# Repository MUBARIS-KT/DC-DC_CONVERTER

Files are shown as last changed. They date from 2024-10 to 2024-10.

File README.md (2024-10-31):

# DC to DC Converter

This project provides the complete design and code for a DC to DC converter that steps up 12V DC to 300V DC. The project is a comprehensive solution in power electronics, including PCB design, STM32 code for PWM generation, datasheets, design references, and the full converter design.

## Features

- **High Voltage Conversion**: Steps up 12V DC input to 300V DC output.
- **PCB Design**: Includes a custom PCB layout tailored for the converter.
- **STM32 PWM Generation**: Code for PWM signal generation to drive the converter.
- **Comprehensive Documentation**: Includes datasheets and design references for all components used.
- **Optimized for Power Electronics Applications**: Designed with efficiency and stability in mind, suited for high-voltage DC applications.

## Getting Started

This project is designed for use with STM32 microcontrollers and requires STM32CubeIDE for code development. The PCB design files are available and can be used with compatible design software.

### Prerequisites

- **STM32CubeIDE**: Required for programming and PWM generation.
- **PCB Design Software**: To view and edit the PCB layout files.
- **Basic Knowledge in Power Electronics**: Understanding of DC to DC converters and high-voltage safety practices.

## Usage

This project can be used as a base for developing custom high-voltage DC converters. It includes a full design, making it adaptable to various power electronics applications requiring DC step-up conversion.

## Technologies Used

- **Programming Language**: C (for STM32 PWM generation)
- **Libraries**: STM32 HAL for embedded development
- **PCB Design**: Provided layout files compatible with PCB design software

---

This README is structured for quick reference and ease of use. Let me know if you’d like any further customization!

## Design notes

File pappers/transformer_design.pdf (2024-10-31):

# DESIGN OF TRANSFORMER

# Classification of transformer

## Depending upon the type of construction used: I. Core type II. Shell type

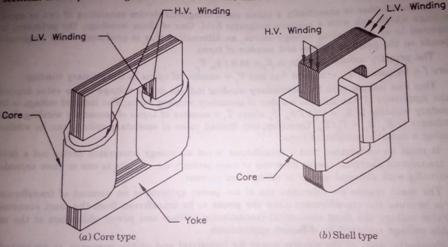
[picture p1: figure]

## Comparison of core type and shell type transformers:-

I. Construction:- Core type transformers are much simpler in design and permit easier assembly and insulation of winding.
II. Mechanical forces:- The forces produced between windings is proportional to the product of the currents carried by them. Very large electromagnetic forces are produced when secondary winding is short circuited. Since the windings carry currents in opposite direction, there exists a force of repulsion between them. Hence, the inner winding experiences a compressive force and outer winding experiences a tensile force.

In a shell type transformer, windings have greater capability of withstanding forces produced under short circuit as these windings are surrounded and supported by the core. But in a core type transformer windings have a poorer mechanical strength.

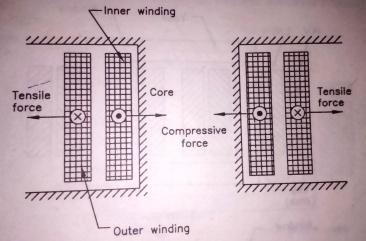
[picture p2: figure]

III. Leakage reactance:- In core type transformer large space required between the high and low voltage winding, it is not possible to subdivided the winding, while, in shell type transformer the windings can be easily subdivided by using sandwich coil. So it is possible to reduce the leakage reactance of shell type transformers.
IV. Repairs:- The winding of core type transformer is completely accessible so coils can be easily inspected. And also core type transformer is easy to dismantle for repair. In shell type transformer, the coils are surrounded by core, therefore difficulty in inspection and repair of coils.
V. Cooling:- In core type transformer windings are exposed and therefore the cooling is better in winding than core. In case of shell type transformer core is exposed therefore cooling is better than winding.

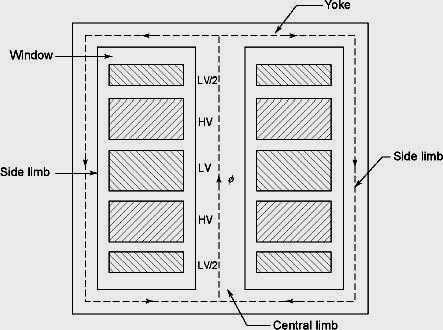
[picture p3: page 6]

CORE TYPE | SHELL TYPE
1. | Easy | in | design | and
construction.
1. Comparatively complex.
2. Has low mechanical strength due to non- bracing of windings.
2. High mechanical strength.
3. Reduction of leakage reactance is not easily possible.
3. Reduction of leakage reactance is highly possible.
4. The assembly can be easily dismantled for repair work.
4. It cannot be easily dismantled for repair work.
5. Better heat dissipation from windings.
5. Heat is not easily dissipated from windings since it is surrounded by core.
6. Has longer mean length of core and shorter mean length of coil turn. Hence best requirement
6. It is not suitable for EHV (Extra High voltage) requirement.

## Classification on the basis of type of service: I. Distribution transformer II. Power transformer

## Classification on the basis of power utility: I. Single phase transformer II. Three phase transformer

# Construction of transformer

I. Transformer core
II. Winding
III. Insulation
IV. Tank
V. Bushings
VI. Conservator and breather VII. Tapping and tap changing VIII.Buchholz Relay
IX. Explosion vent
X. Transformer oil

## - The most important function performed

by transformers are,

### – Changing voltage and current level in an electric

system.

### – Matching source and load impedances for maximum power transfer in electronic and

control circuitry.
– Electrical isolation.

### Nomenclature

Vp

, Vs

### = terminal voltages at primary and Secondary winding respectively, V

Ep

, Es

### = emf induced in the primary and secondary windings per phase, V

Et

### = emf per turn, V

Tp

, Ts

### = number of primary and secondary turns per phase

Ip

, I
s

### = primary and secondary currents per phase , A

ap

, as

### = area of the primary and secondary winding conductors, m² Φm –=main flux in weber = AiBm

Bm

### = Maximum value of the flux density = Φm / Ai

### tesla

Ai – Net iron area of the core or leg or limb (m² )= KiAgi
Ki – Iron or stacking factor = 0.9 approximately Agi – Gross area of the core, m²
Ac – area of copper in window, m²
Aw – window area, m²
D – distance between core centers, m d= diameter of circumscribing circle, m Kw – window space factor
δ - Current density (A/m²
). Assumed to be same for both LV and HV winding.

## Output Equation of Transformer

- The equation which relates the rated kVA output of a transformer to the area of core and window is called output equation.
- In transformers the output kVA depends on flux density and ampere-turns.
- The flux density is related to core area and the ampere-turns is related to window area.
- The low voltage winding is placed nearer to the core in order to reduce the insulation requirement.
- The space inside the core is called window and it is the space available for accommodating the primary and secondary winding.
- The window area is shared between the winding and their insulations.

### The simplified cross-section of core type and shell type single phase transformers

### Core Type Transformer Shell Type Transformer¹⁴

### Single phase core type transformer

The induced emf in a transformer,

Emf per turn,

The window in single phase transformer contains one primary and

one secondary winding.

The window space factor Kw is the ratio of conductor area in window

to total area of window.

Conductor area in window,

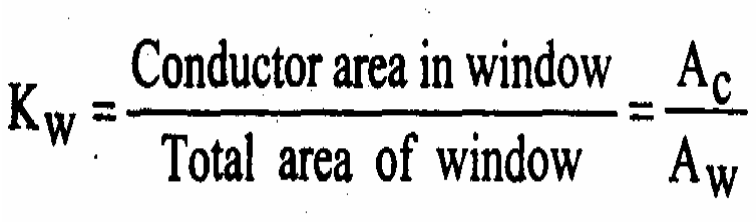
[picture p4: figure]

The current density is same in both the windings. Therefore Current

density =

Area of cross - section of primary conductor,

Area of cross - section of secondary conductor,

If we neglect magnetizing mmf then primary ampere turns is equal to secondary ampere turns. Therefore ampere turns,

Total copper area in window,
Ac = Copper area of primary winding + Copper area of secondary winding
= (Number of primary turns x area of cross-section of primary conductor) + (Number of secondary turns x area of cross -section of secondary conductor)

On equating the above equations, we get,

Therefore Ampere turns,

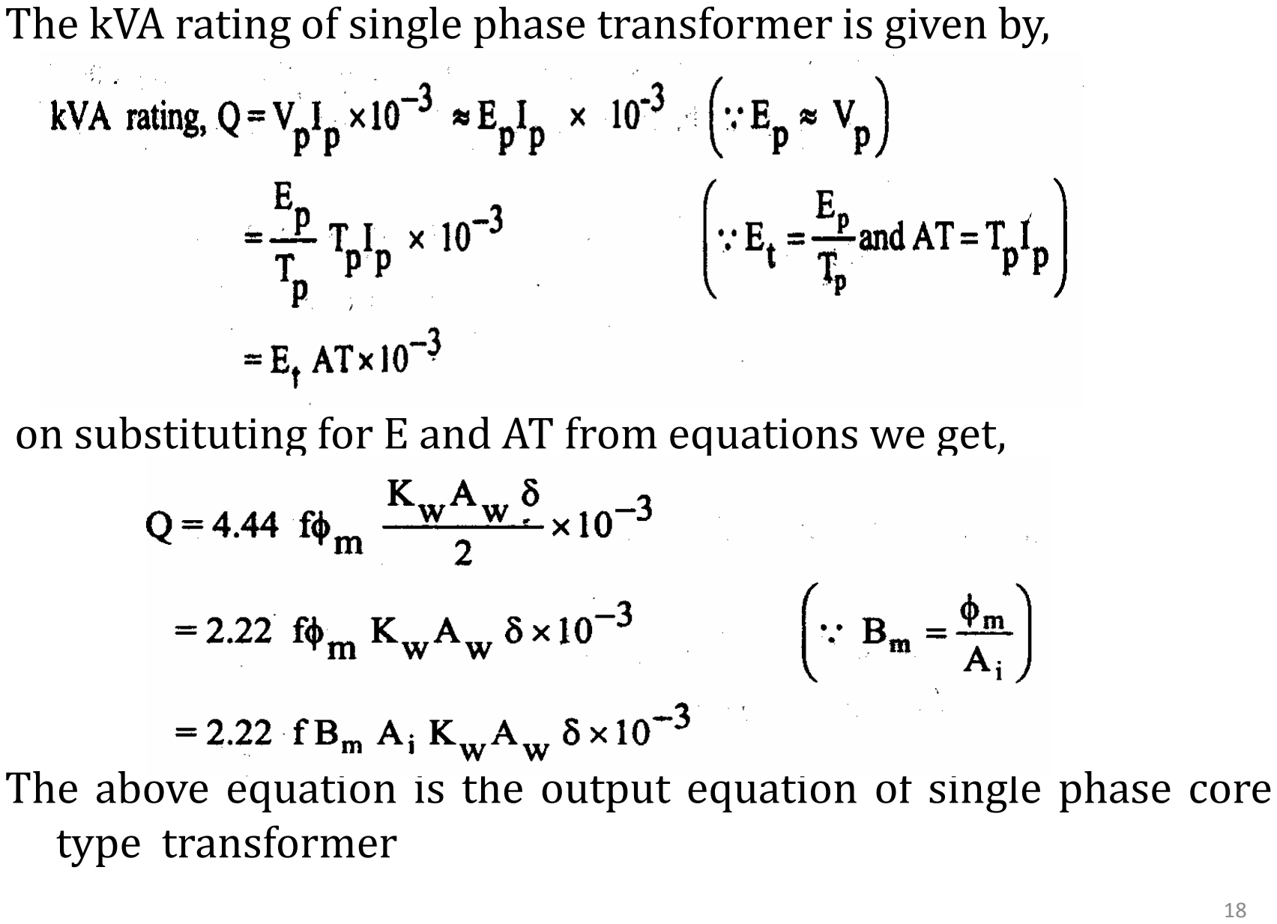
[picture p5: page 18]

The kVA rating of single phase transformer is given by,

on substituting for E and AT from equations we get,

The above equation is the output equation of single phase core type transformer

### Single phase shell type transformer

The induced emf in a transformer,

Emf per turn,

The window in single phase transformer contains one primary and

one secondary winding.

The window space factor Kw is the ratio of conductor area in window

to total area of window.

Conductor area in window,

The current density is same in both the windings. Therefore Current

density =

Area of X - section of primary conductor,

Area of X - section of secondary conductor,

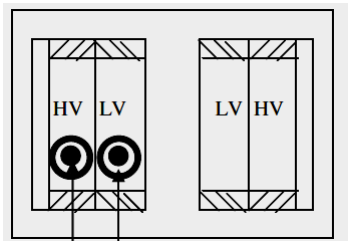
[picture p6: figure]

If we neglect magnetizing mmf then primary ampere turns is equal to secondary ampere turns. Therefore ampere turns,

Since there are two windows, it is sufficient to design one of the two windows as both the windows are symmetrical. Since the LV and HV windings are placed on the central leg, each window accommodates Tp

and Ts

turns of both primary and
secondary windings
Copper area in window Ac

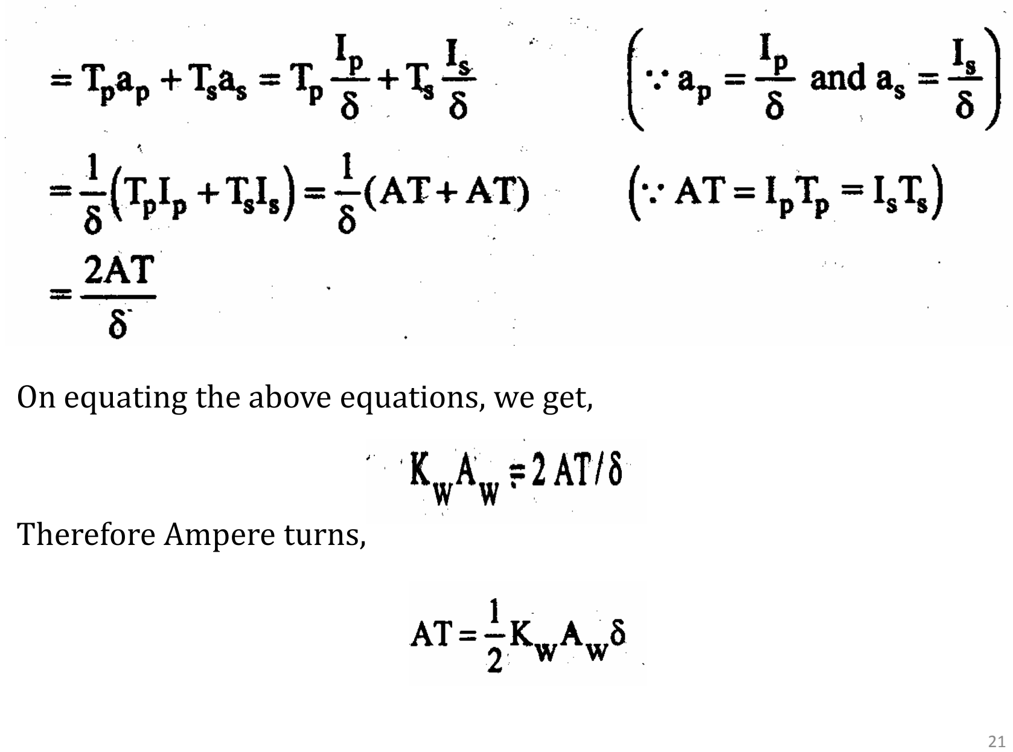
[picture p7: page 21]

On equating the above equations, we get,

Therefore Ampere turns,

The kVA rating of single phase shell type transformer is given by,

on substituting for E and AT from equations we get,

The above equation is the output equation of single phase shell type transformer

### Three phase core type transformer

- Core type three phase transformer has three limbs and two windows as shown in figure.
- Each limb carries the low voltage and high voltage winding of a phase.

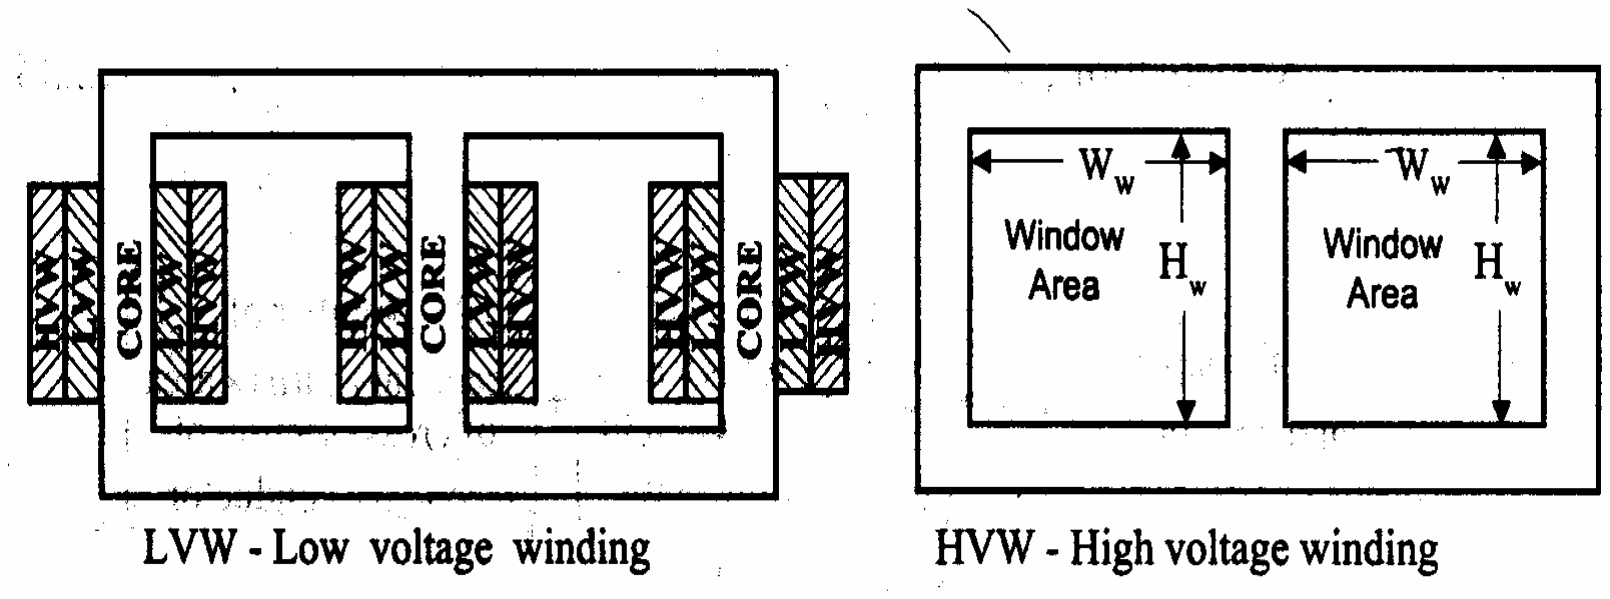
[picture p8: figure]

The induced emf in a transformer,

Emf per turn,

In case of three phase transformer, each window has two

primary and two secondary windings.

window space factor Kw is

Conductor area in window,

The current density is same in both the windings. Therefore

Current density =

Area of cross - section of primary conductor,

Area of cross - section of secondary conductor,

If we neglect magnetizing mmf then primary ampere turns is equal to secondary ampere turns. Therefore ampere turns,

Total copper area in window, Ac = (2 x Number of primary turns x area of cross-section of primary conductor) + ( 2 x Number of secondary turns x area of cross - section of secondary conductor)

On equating the above equations, we get,

The kVA rating of three phase transformer is given by,

on substituting for E and AT from equations we get,

The above equation is the output equation of three phase transformer

### Three phase shell type transformer

### Rating of the transformer in Q = Vp

Ip

### x 10⁻³ = Ep

Ip

### x 10⁻³ kVA = 4.44 Φm f Tp

### x Ip

### x 10⁻³ kVA

Since there are six windows, it is sufficient to design one of the six windows, as all the windows are symmetrical. Since each central leg carries the LV and HV windings of one phase, each window carries windings of only one phase.

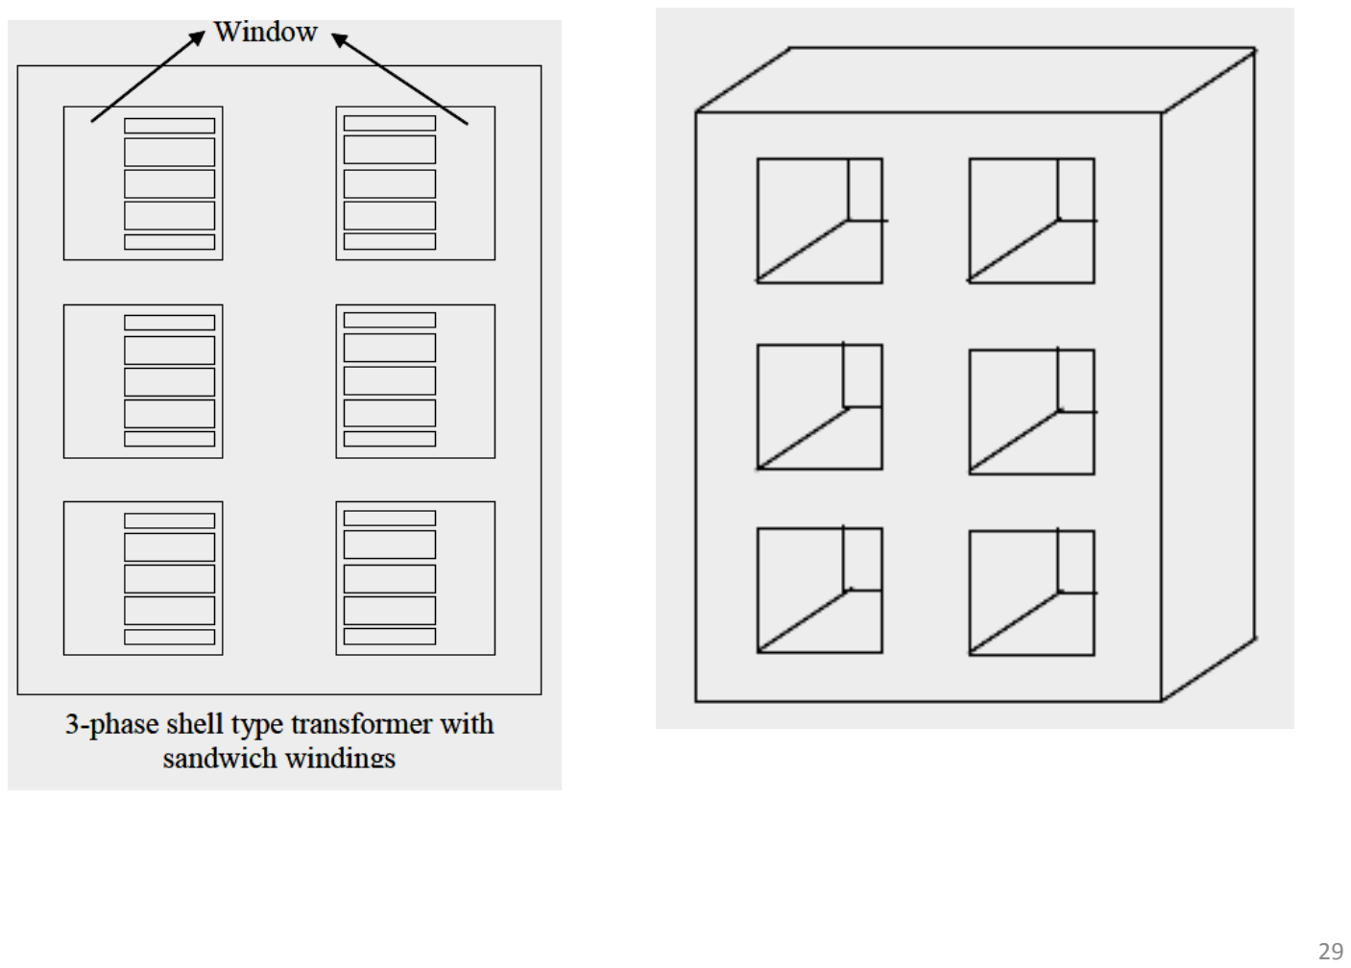
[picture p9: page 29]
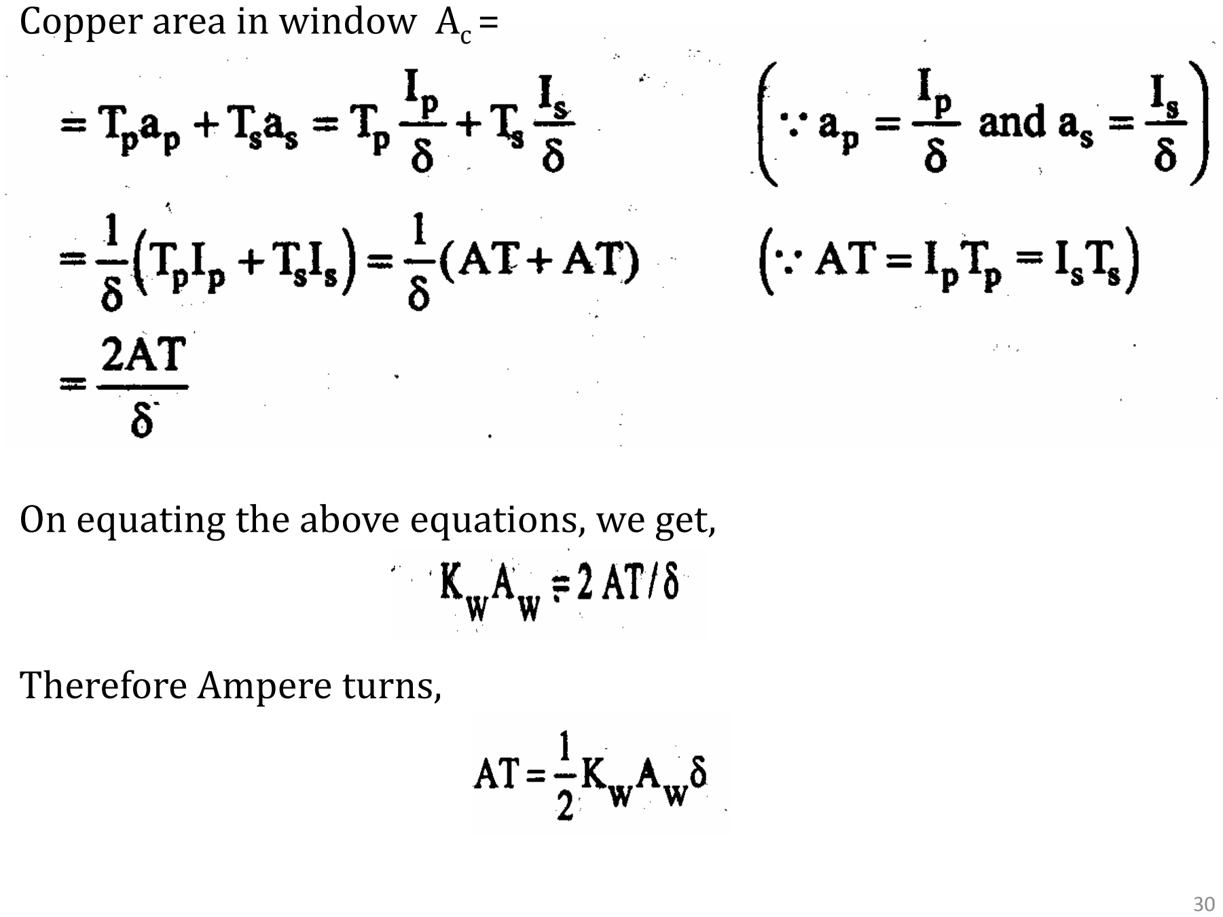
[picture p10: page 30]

Copper area in window Ac

=

On equating the above equations, we get,

Therefore Ampere turns, on substituting AT in kVA rating,

Q = 3 x 4.44 AiBmf x (AwKwδ/2) x 10⁻³ kVA

Q = 6.66 f δ AiBm AwKw

x 10⁻³ kVA

### Output equation of transformer

Single phase core type & shell type transformer :-

Three Phase core type transformer :-

Three Phase shell type transformer :-

### Q = 6.66 f Bm δ KwAw Ai

### . 10⁻³ kVA

## Usual values of flux density

Normal Si-Steel | 0.9 to 1.1 T

### (0.35 mm thickness, 1.5%—3.5% Si)

HRGO | 1.2 to 1.4 T

### (Hot Rolled Grain Oriented Si Steel)

CRGO | 1.4 to 1.7 T

### (Cold Rolled Grain Oriented Si Steel) (0.14---0.28 mm thickness)

This depends upon cooling method employed

Natural Cooling: | 1.5---2.3 A/mm2
AN | Air Natural cooling
ON | Oil Natural cooling
OFN | Oil Forced circulated with Natural air cooling
Forced Cooling : | 2.2---4.0 A/mm2
AB | Air Blast cooling
OB | Oil Blast cooling
OFB | Oil Forced circulated with air Blast cooling
Water Cooling:5.0 ---6.0 A/mm2 OW Oil immersed with circulated Water cooling OFW Oil Forced with circulated Water cooling

## Usual values of current density

## Emf per turn equation

To solve the output equation,
kVA = 2.22 or 3.33 or 6.66 f δ AiBm AwKw x 10⁻³ having two unknowns Ai

and Aw , volt per turn equation is considered.
Rating of the transformer per phase Q = Vp

Ip

x 10⁻³ = Ep
Ip
x 10⁻³ kVA | (Vp ≈ Ep
)
= 4.44 Φm f Tp

Ip

x 10⁻³

The term Φm is called the magnetic loading and I1T1

is
called the electric loading. The required kVA can be obtained by selecting a higher value of Φm and a lesser of IpTp or vice-versa.

As the magnetic loading increases, flux density and hence the core loss increases and the efficiency of operation decreases. Similarly as the electric loading increases, number of turns, resistance and hence the copper loss increases. This leads to reduced efficiency of operation. It is clear that there is no advantage by the selection of higher values of IpTp or Φm. For an economical design they must be selected in certain proportion. Let, ratio of specific magnetic and electric loading be,

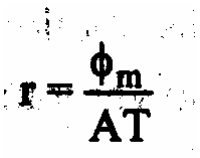
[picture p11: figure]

Considering the primary voltage and current per phase

kVA rating of transformer:

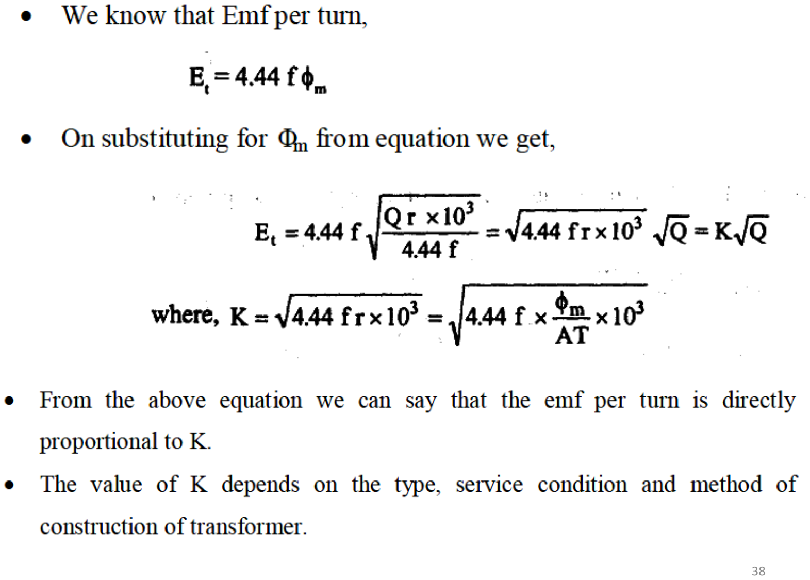
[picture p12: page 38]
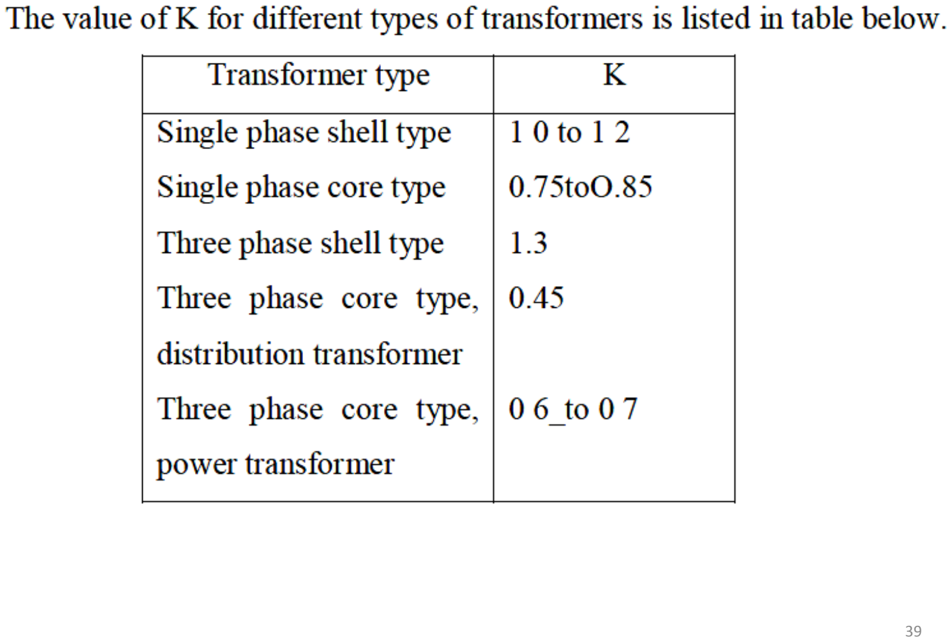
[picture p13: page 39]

## Design of Cores

Rectangular core: It is used for core type distribution transformer and small power transformer for moderate and low voltages and shell type transformers.
In core type transformer the ratio of depth to width of core varies between 1.4 to 2.
In shell type transformer width of central limb is 2 to 3 times the depth of core.
Square and stepped cores: For high voltage transformers, where circular coils are required, square and stepped cores are used.

# Square and stepped core

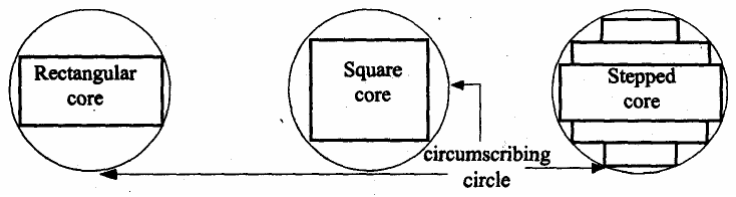
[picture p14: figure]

## Square Core

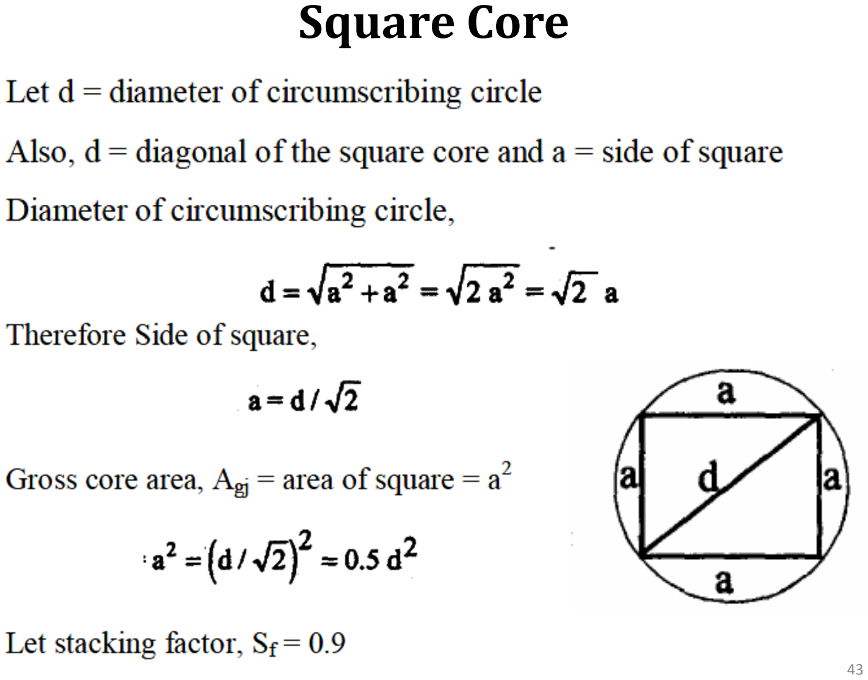
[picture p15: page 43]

## Square Core

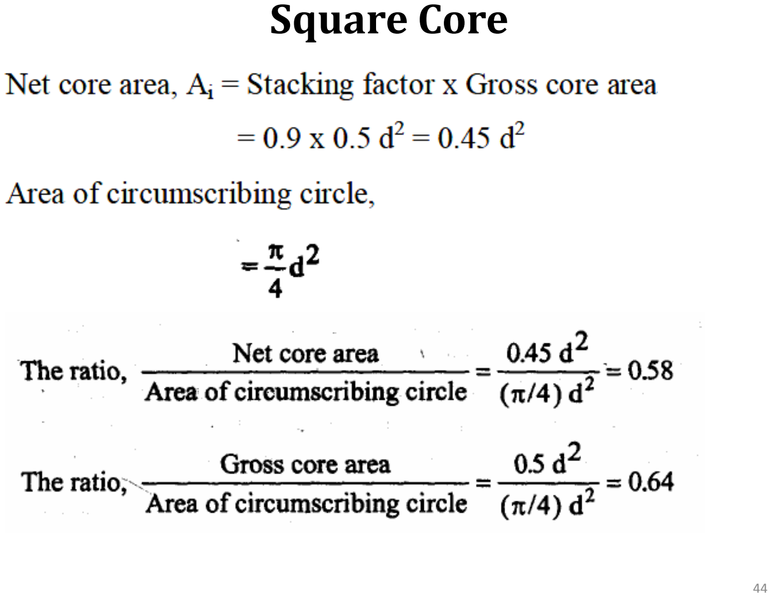
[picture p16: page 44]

## Two Stepped Core for Cruciform Core

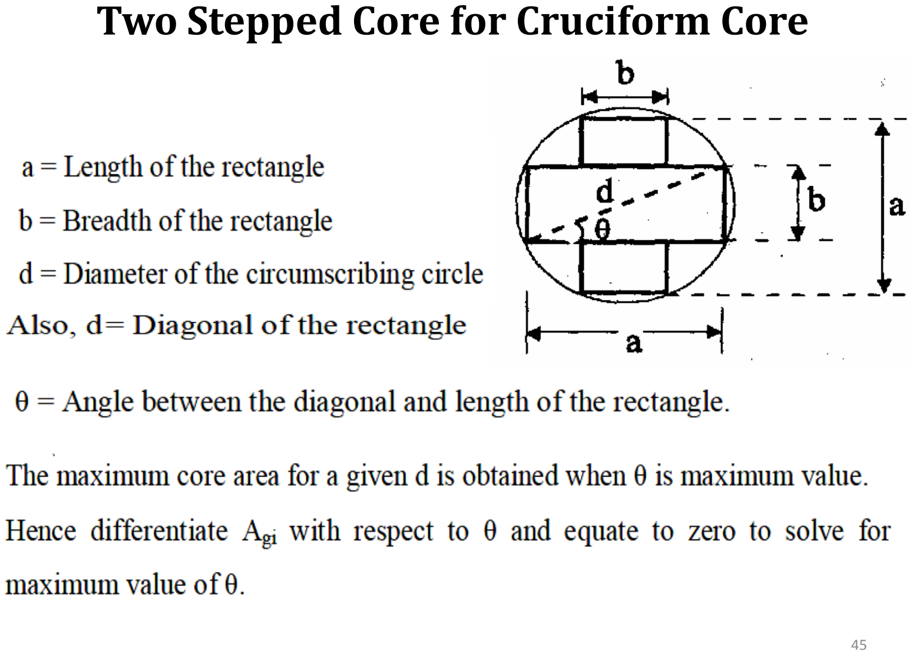
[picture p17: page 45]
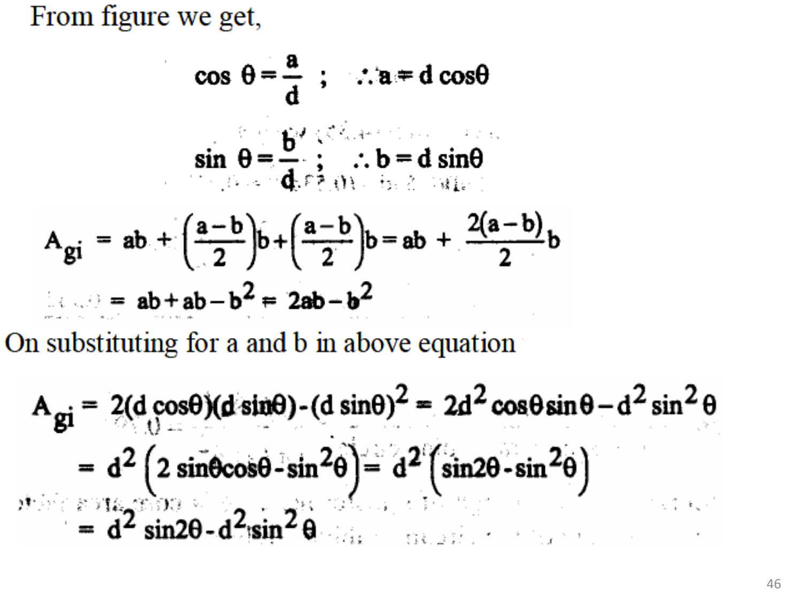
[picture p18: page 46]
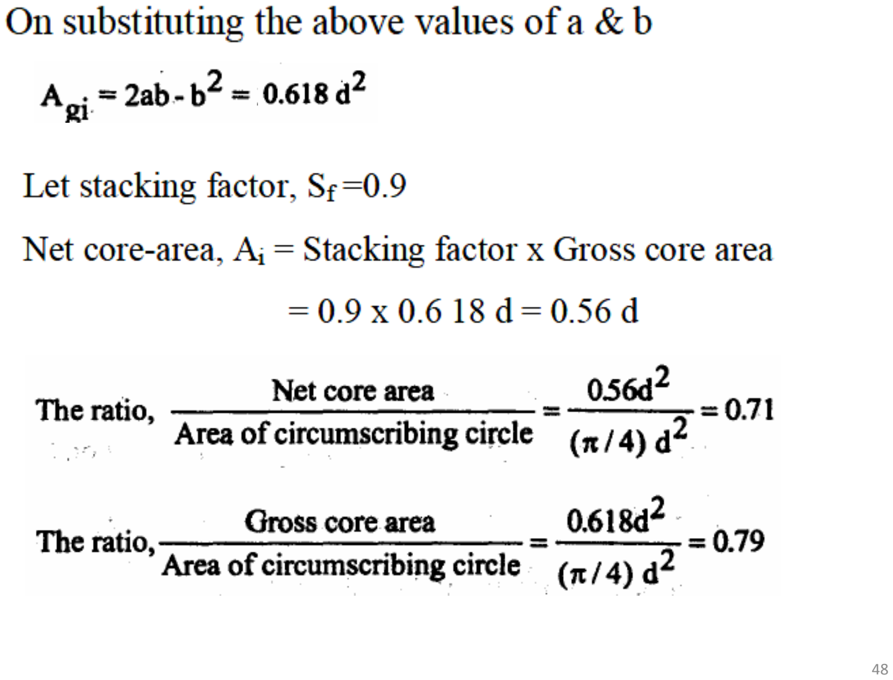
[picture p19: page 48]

### Cross-section and dimensions of Stepped cores

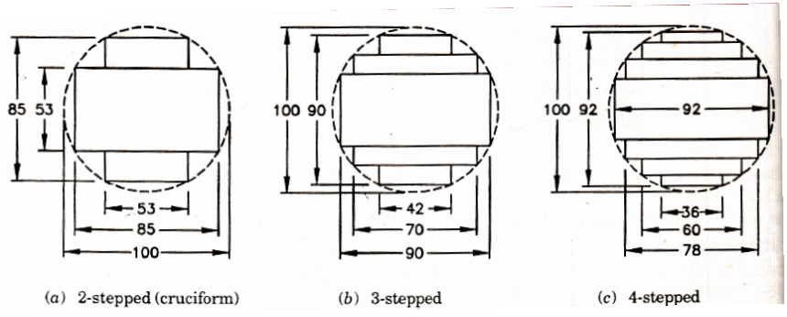
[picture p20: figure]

Area %age of circumscribing circle | Square | Cruciform | Three stepped | Four Stepped
Gross core area, Agi Net core area, Ai | 64 58 | 79 71 | 84 75 | 87 78
Net core area 2 Ai=kcd , kc | 0.45 | 0.56 | 0.6 | 0.62

Window Space Factor: It is the ratio of copper area in the window to the total window area.

Kw = 10/(30+kV) | for transformer rating 50 to 200kVA
Kw = 12/(30+kV) | for rating about 1000 kVA
Kw = 8/(30+kV) | for rating about 20 kVA

Window dimensions:
The area of window depend upon total conductor area and window space factor.
Area of window Aw = total conductor area/ window space factor = 2.ap Tp/Kw for 1-ph transformer = 4.ap Tp/Kw for 3-ph transformer

Aw = height of window x width of window = Hw x Ww
The ratio of height to width of window, Hw /Ww is b/w 2 to 4.

Design of Yoke: The section of yoke can either be taken as rectangular or it may be stepped.
In rectangular section yokes,
depth of the yoke = depth of core
area of yoke Ay = Dy x Hy
Dy = depth of yoke= width of largest core stamping = a
Ay = 1.15 to 1.25 of Agi for hot rolled steel
= Agi for CRGO

### Overall Dimensions

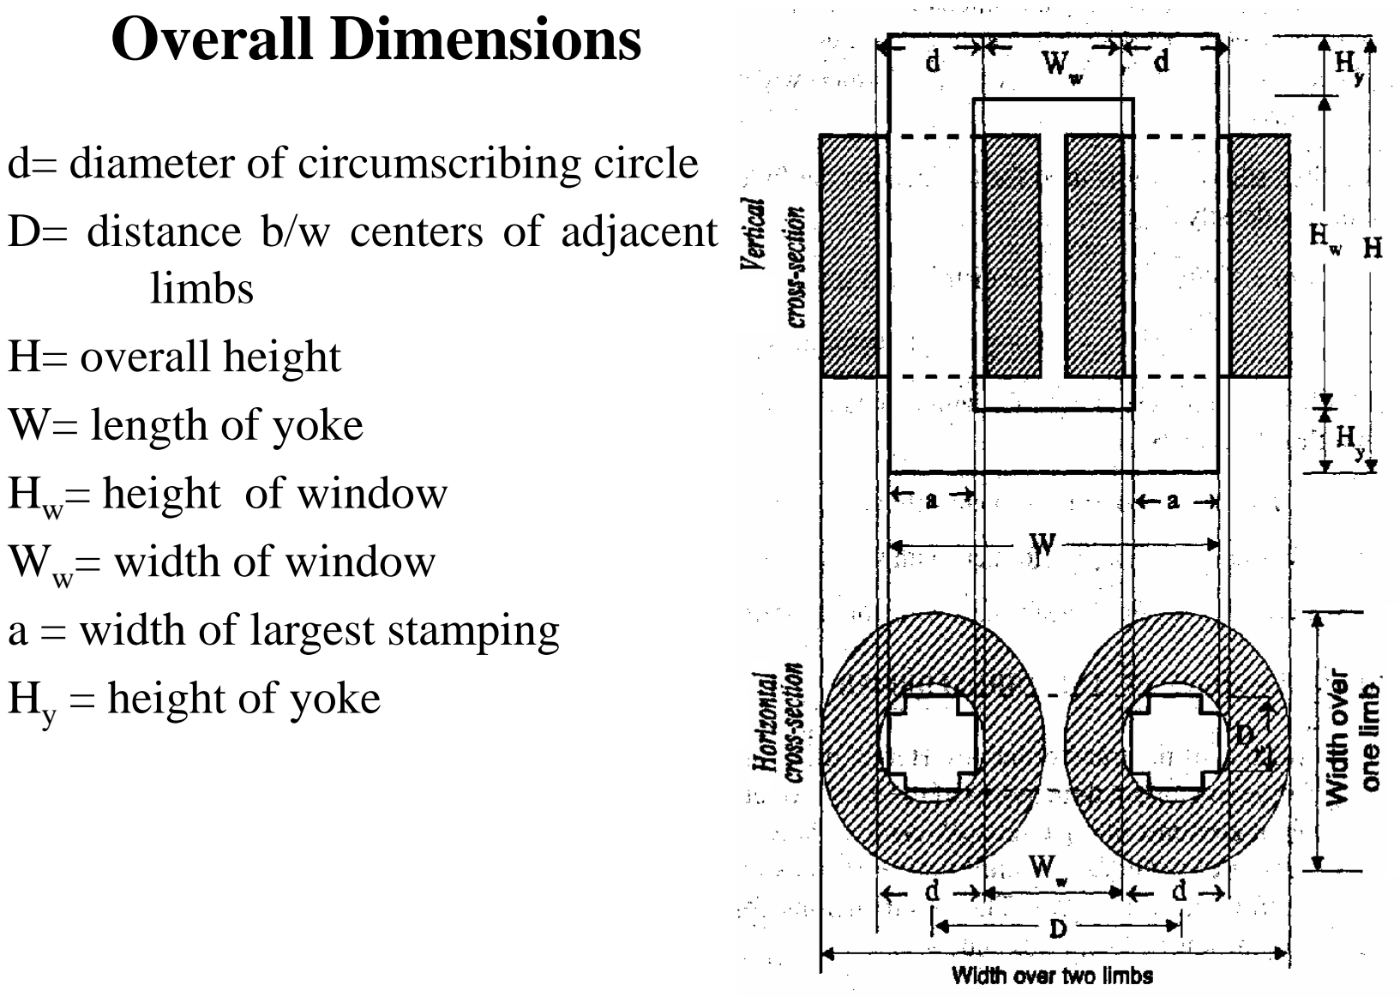
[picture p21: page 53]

d= diameter of circumscribing circle D= distance b/w centers of adjacent limbs
H= overall height
W= length of yoke
Hw

= height of window
Ww

= width of window
a = width of largest stamping Hy

= height of yoke

1-Φ Core Type Transformer
D = d + Ww
Dy

= a
H = Hw + 2Hy
W = D + a
Width over two limbs = D + outer diameter of hv winding Width over one limb = outer diameter of hv winding
3-Φ Core Type Transformer
D = d + Ww

, Dy

= a
H = Hw + 2Hy
W = 2D + a
Width over three limbs = 2*D + outer diameter of hv winding Width over one limb = outer diameter of hv winding

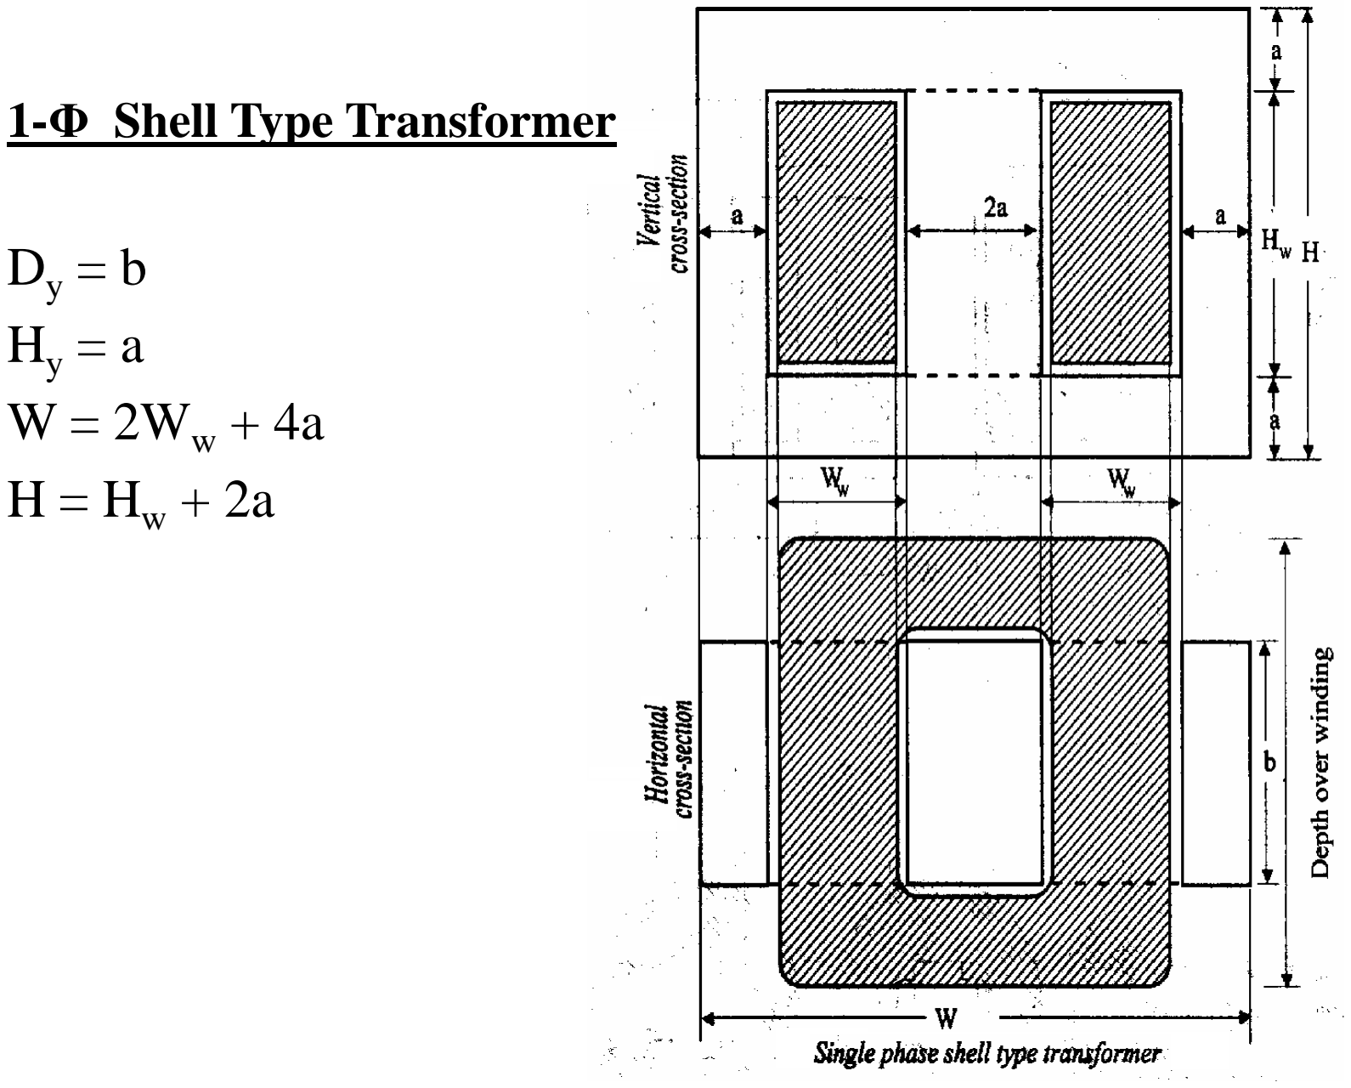
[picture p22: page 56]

1-Φ Shell Type Transformer

Dy = b
Hy = a
W = 2Ww + 4a
H = Hw + 2a

Estimation of no of turns :

Primary no of turns Tp = Vp / Et

Secondary no of turns Ts = Vs / Et

Estimation of sectional area of windings

Primary current Ip

= Q*10⁻³
/3Vp

Secondary current Is

= Q*10⁻³
/3Vs

Sectional area of primary winding ap

= Ip

/ δ

Sectional area of primary winding as

= Is

/ δ

Resistance of Transformer

Resistant of the primary winding/phase rp

= (ρLmt) Tp

/ap ohm
Mean length of turn of the primary winding Lmt_p

= π x mean
diameter of the primary winding
Resistant of the secondary winding/phase rs

= (ρLmt) Ts /as ohm
Mean length of turn of the Secondary winding Lmt_s

= π x mean
diameter of the secondary winding
Resistance of the transformer referred to primary / phase Rp

= rp + rs

‘ = rp + rs
(Tp

/Ts

)
Resistance of the transformer referred to primary / phase Rs

= rs + rp

‘ = rs + rp
(Ts

/Tp

)

Reactance of Transformer

Useful flux: It is the flux that links with both primary and secondary windings and is responsible in transferring the energy Electro-magnetically from primary to secondary side. The path of the useful flux is in the magnetic core.
Leakage flux: It is the flux that links only with the primary or secondary winding and is responsible in imparting inductance to the windings. The path of the leakage flux depends on the geometrical configuration of the coils and the neighboring iron masses.

If xp

and xs

are the leakage reactances of the primary and secondary windings, then the total leakage reactance of the transformer referred to primary winding
Xp

= xp + xs

'

= xp+ xs

(Tp

/Ts

)

2

and total leakage reactance of the transformer referred to primary winding
Xs

= xs + xp

'

= xs+ xp

(Ts

/Tp

)

2

Voltage Regulation

V .R. = Is RsCosΦ2 ± Is Xs SinΦ2 *100
Es
= RsCosΦ2
* 100 ± Xs SinΦ2

*100
Es
/ Is | Es

/ Is
= %RsCosΦ2 ± %Xs SinΦ2

No-load current of transformer

The no-load current I0 is the vectorial sum of the magnetizing current Im and core loss or working component current I
c
[Function of Im is to produce flux Φm in the magnetic circuit and the function of I
c

is to satisfy the no load losses of the transformer].

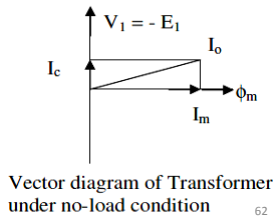
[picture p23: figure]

No load input to the transformer/ph = V1

I0 Cosϕo = V1
Ic

No load losses as the output is zero and input = output + losses.

Since the copper loss under no load condition is almost negligible,

the no load losses can entirely be taken as due to core loss only. Thus

the core loss component of the no load current

I
c

= core loss/ V1

for single phase transformers

Ic

= core loss/ 3V1

for three phase transformers

RMS value of magnetizing current Im

=

The magnetic circuit of a transformer consists of both iron and air path. The iron path is due to legs and yokes and air path is due to the unavoidable joints created by the core composed of different shaped stampings. If all the joints are assumed to be equivalent to an air gap of length lg

, then the total ampere turns for the transformer magnetic circuit is equal to ATfor iron + 800,000lgBm

ATo

= ATfor iron + 800,000lgBm

ATfor iron = 2 atc

l

c + 2aty

l
y

for single phase transformer

ATfor iron = 3 atc

l

c + 2aty

l
y

for three phase transformer

l
c

, l
y

= length of flux path through core and yoke respectively atc

, aty
= mmf/m for flux densities in core and yoke respectively

1. In case of a transformer of normal design, the no load current will generally be less than about 2% of the full load current.
2. No load power factor Cosϕo = Ic/Io and will be around 0.2.
3. Transformer copper losses:
a) The primary copper loss at no load is negligible as Io

is very less.
b) The secondary copper loss is zero at no load, as no current flows in the secondary winding at no load.
4. Core or iron loss:
Total core loss = core loss in legs + core loss in yokes.
Core loss in leg = loss/kg in leg * weight of leg in kg = loss / kg in leg * volume of the leg (Ai

*Hw

) * density of
steel or iron used
Core loss in yoke = loss/kg in Yoke * volume of yoke (Ay

* mean length of
the yoke) * density of iron used

### Temperature rise of Transformer

•The losses developed in the transformer cores and windings are converted into thermal energy and cause heating of corresponding transformer parts.
•The heat dissipation in transformer occurs by Conduction, Convection and Radiation.
The paths of heat flow in transformer are the following
1. From internal most heated spots of a given part (of core or winding) to their outer surface in contact with the oil.
2. From the outer surface of a transformer part to the oil that cools it.
3. From the oil to the walls of a cooler, eg. Wall of tank.
4. From the walls o the cooler to the cooling medium air or water.

•In the path 1 mentioned above heat is transferred by conduction. •In the path 2 and 3 mentioned above heat is transferred by convection of the oil.
•In path 4 the heat is dissipated by both convection and radiation.
In small capacity transformers the surrounding air will be in a position to cool the transformer effectively and keeps the temperature rise well with in the permissible limits.
As the capacity of the transformer increases, the losses and the temperature rise increases. In order to keep the temperature rise with in limits, air may have to be blown over the transformer. This is not advisable as the atmospheric air containing moisture, oil particles etc., may affect the insulation. To overcome the problem of atmospheric hazards, the transformer is placed in a steel tank filled with oil.

Further as the capacity of the transformer increases, the increased losses demands a higher dissipating area of the tank or a bigger sized tank. This calls for more space, more volume of oil and increases the cost and transportation problems. To overcome these difficulties, the dissipating area is to be increased by artificial means with out increasing the size of the tank. The dissipating area can be increased by
1. fitting fins to the tank walls | 2. fitting tubes to the tank
3. using corrugated tank | 4. using auxiliary radiator tanks

Since the fins are not effective in dissipating heat and corrugated tank involves constructional difficulties, they are not much used now a days. The tank with tubes are much used in practice.

Heat goes dissipated to the atmosphere from tank by radiation and convection. It has been found by experiment that a plain tank surface dissipate 6.0W and 6.5W/m²–

oC by radiation and
convection respectively. Thus a total loss dissipation is 12.5W/m²–

oC.

Temp rise θ

St = Heat dissipating surface of tank

Plain Walled Tanks

Design of Tank with Tubes

If the temperature rise of plain tank exceeds the permissible limit of about 50 degree centigrade, then cooling tubes are to be added to reduce the temperature rise. With the tubes connected to the tank, dissipation due to radiation from a part of the tank surface screened by the tubes is zero. So there is no change in surface as far as dissipation of heat due to radiation is concerned. Because the oil when get heated up moves up and cold oil down, circulation of oil in the tubes will be more. Obviously, this circulation of oil increases the heat dissipation by convection about 35%.

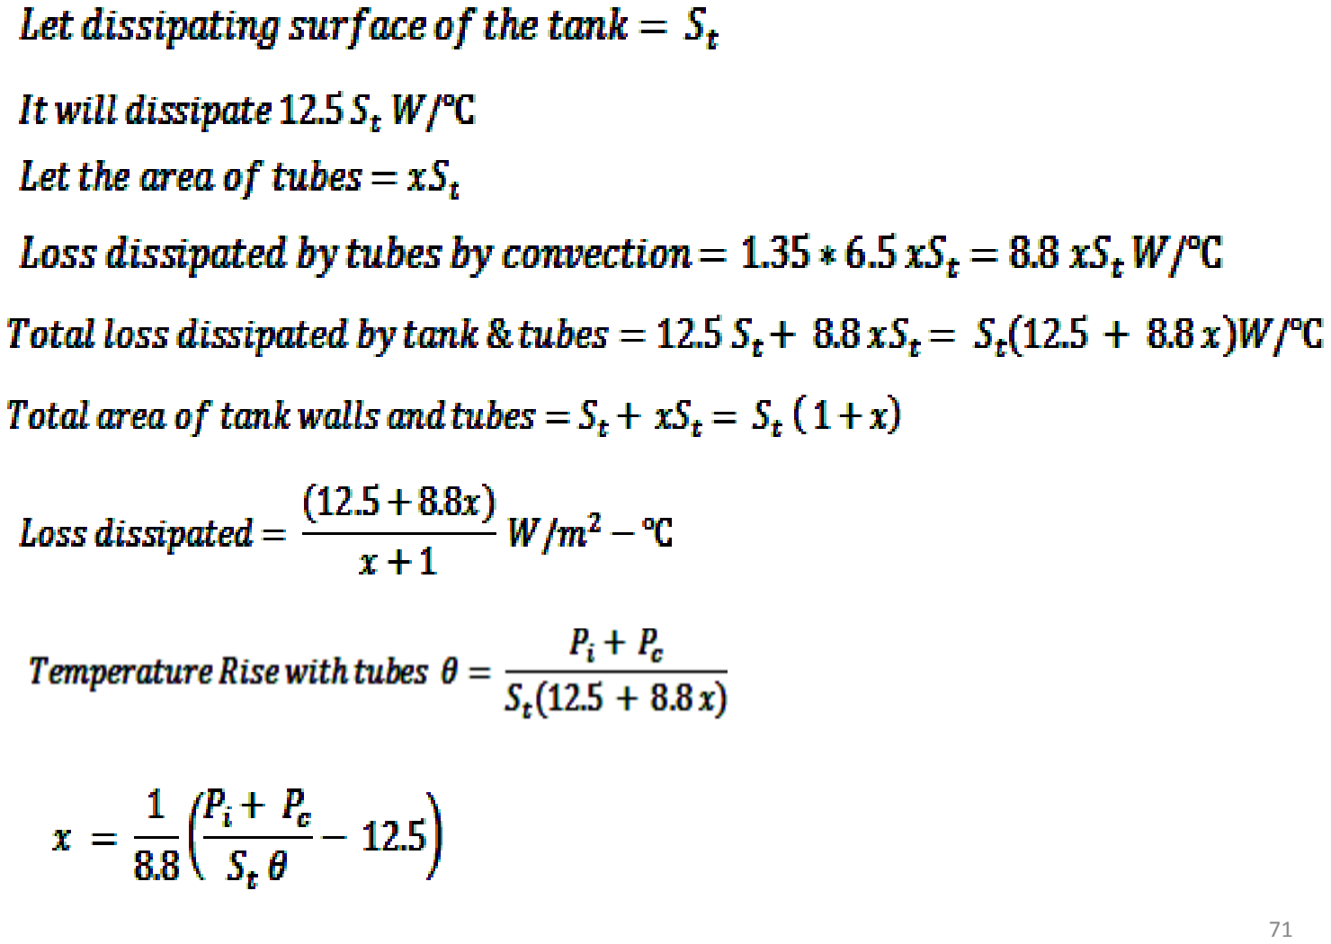
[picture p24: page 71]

The diameter of tubes, normally used, is 50 mm and they are spaced at 75 mm

Cooling of Transformer

The coolants used in transformers are air and oil.
Transformers using air as coolant are called Dry type transformers while transformers which use oil as coolant are called Oil immersed transformers.

Methods of Cooling of Transformers: the choice of cooling method depends upon the size, type of application and the type of conditions of installation sites.
The symbols designated these methods depend upon medium of cooling used and type of circulation employed.
Medium:- Air-A, Gas-G, Oil-O, Water-W, Solid insulation-S Circulation:- Natural-N, Forced-F

Cooling of Dry-type transformer Air Natural (AN), Air Blast (AB)

Cooling of oil immersed transformer Oil Natural (ON)
Oil Natural Air Forced (ONAF)
Oil Natural Water Forced (ONWF) Forced Circulation of Oil (OF)
i. Oil Forced Air Natural (OFAN) ii. Oil Forced Air Forced (OFAF) iii. Oil Forced Water Forced (OFWF)

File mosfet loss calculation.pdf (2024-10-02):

### MOSFET

### MosFET Losses

The losses in a switching MosFET are due to

- Conduction losses
- Losses due to on-state resistance/Rds-on losses
- Switching losses
- Losses due to output capacitor/Coss losses
- Turn on losses
- Turn off losses
- Gate losses – Gate charge losses and losses on the internal gate resistor

The equations regarding the above losses are expressed below

Where,

Rdson losses
The conduction loss in a MosFET is due to drain to source on-state resistance. Rdson depends upon the gate to source voltage and the junction temperature. In the datasheet of a MosFET, there will be two graphs indicating the variation of Rdson, one with respect to gate-source voltage and drain current, another one with respect to junction temperature.

From the first curve, find the Rdson corresponding to the maximum drain current (RMS) and Vgs or find the multiplier if the curve gives normalized values. Multiply with the maximum Rdson given in table to obtain the actual value.

From the Rdson vs junction temperature curve, find the Rdson or multiplier corresponding to a junction temperature of 75°C or higher as per the maximum external ambient temperature. If the ambient is above 50°C, select the Rdson multiplier corresponding to 125°C og junction temperature. Find the Rdson_hot by multiplying the Rdson obtained from the first curve or table value

The Rdson losses can be found out from equation below

Where,

= RMS value of the current through MosFET

= Rdson at working junction temperature

Coss Losses
Coss is the virtual capacitor across MosFET drain and source. While switch is off, the Coss will be charged to the voltage across drain and source and when the switch turns on Coss discharges first.

Find the Coss from curve showing capacitance vs drain to source voltage, for the working Vds.

The Coss losses can be found from equation below

Where,

Coss losses

Coss at working

Drain to source voltage

Switching frequency

Turn on and Turn off of MosFET
The equivalent circuit below shows the MosFET with components having great effects in switching process.


Figure 1. MosFET equivalent circuit

The datasheet of a MosFET shows 3 capacitances,

Input capacitor

Output capacitor

Reverse transfer capacitance

The relation between the datasheet capacitances and equivalent circuit capacitances are as given below

with shorted

Where,

Gate to source capacitor

Gate to drain capacitor

Drain to source capacitor

Turn-on Process
The graph below shows the MosFET turn on process.


Figure 2 – MosFET turn on curve

– When a voltage of | is applied across MosFET gate, | and | is charged initially. Until the
voltage reaches the threshold value of gate voltage | , there is no change in voltage and current across
MosFET.
– Once the gate voltage reaches | , the current starts increasing, but drain to source voltage still
remains the same. When the gate voltage reaches the plateau voltage | , | is fully charged and the
drain current reaches its final value. This time | is called turn on delay time | .
– Once gate voltage reaches plateau voltage | , the voltage remains at the same level until the
capacitor | is fully charged. This capacitor is called Miller capacitor and the region is known as Miller
plateau. When voltage reaches plateau, | starts falling and at the end of plateau region, | reaches
the minimum value of 10% of maximum | . The time | is called rise time

– Once | is fully charged at the end of plateau, the capacitors | and | charges up to the final
value of applied | .
The gate charge parameters in MosFET datasheet | and | are the bare minimum charge required to
turn on the MosFET, but an additional charge should be required to keep the MosFET on, thus making the total charge to be

. Power loss will be there when voltage and current changes, this occur at times and

. The equations for the times can be found out from the capacitor charging equations.


Figure 3 – Turn on times and capacitances

The capacitor charging equation in general is
(
(

⁄ )

)
(

)

Where,

Capacitor voltage at the end of time t.

Source voltage

Time taken for the capacitor voltage to rise from 0 to

Charging resistor

The capacitance

For times | and
, the capacitor | charges from gate supply through a resistor | , where | is
the sum of internal and external gate resistances in the charging path.

[

]

Transforming the general equation into MosFET charge parameters, we will get
(

)

(

)

Equation 2 – 1 gives
(

)

Where,

Turn on delay time

Sum of internal and external gate resistances in the charging path

Input capacitor at working , taken from graph

Gate-source driver supply voltage

Gate threshold voltage

Miller plateau voltage

For time

, the capacitor | charges from gate supply through a resistor | at a voltage | . The
rise time | can be found out from the equation below.
(

)

Where,

Rise time

Sum of internal and external gate resistances in the charging path

Reverse transfer capacitor at working , taken from graph

Gate-source driver supply voltage

Drain to source working voltage

Miller plateau voltage

The total on time is given by,

(

) | (

)

Turn-off Process
The graph below shows the MosFET turn off process.


Figure 4 – Mosfet turn off curve

– When the gate voltage of | is made zero from the driver, the voltage across Mosfet gate
capacitors starts discharging from the high level value of | . Until the voltage reaches the miller plateau
voltage | , there is no change in voltage and current across MosFET.
– Once the gate voltage reaches | , | starts rising and at the end of plateau region | reaches
the value of 90% of maximum | . This time | is called turn off delay time | .

– At the end of plateau region, the drain current and gate voltage starts falling. Drain current reaches
its minimum value, when the gate voltage crosses the threshold value of gate voltage | . As the drain
current falls, the leakage and stray inductances in the switching path generates a spike in the | . The
time | is called fall time and at the end of fall time, the mosfet is completely turned off.
– The remaining gate voltage from | discharges to zero at this time period.
Power loss will be there when voltage and current changes, this occur at times | and

. The
equations for the times can be found out from the capacitor discharging equations. The figure below shows the turn off times and capacitances.


Figure 5 – Mosfet turn off times and capacitances

The capacitor discharging equation in general is

(

⁄ )
(

)

Where,

Capacitor voltage at the end of time t.

Initial voltage

Time taken for the capacitor voltage to fall from

to

Discharge resistor

The capacitance

For times | and
, the capacitor | discharges from the plateau voltage | through a resistor | ,
where | is the sum of internal and external gate resistances in the gate turn off path.

Transforming the general equation into MosFET gate discharge parameters, we will get

(

)

Where,

Fall time

Sum of internal and external gate resistances in the discharging path

Input capacitor at working , taken from graph

Gate threshold voltage

Miller plateau voltage

For time

, the capacitor | discharges through a resistor | at a voltage | . The turn off delay
time | can be found out from the equation below.
(

)

Where,

Turn off delay time

Sum of internal and external gate resistances in the discharging path

Reverse transfer capacitor at working , taken from graph

Drain to source working voltage

Miller plateau voltage

The total off time is given by,

(

) | (

)

Turn on and turn off losses
Now that we have the turn on and turn off time of mosfet, we can find out the losses in these regions.

Turn on losses can be calculated from

Where,

Turn on losses

Drain to source voltage excluding and spikes

Total turn on time

Switching frequency

The current at which mosfet turns on – For discontinuous and boundary conduction modes, I min will be zero and hence there will not be any turn on losses. For continuous conduction mode, will be the difference between the peak current and peak to peak ripple current.

Turn off losses can be calculated from

Where,

Turn off losses

Drain to source voltage including the turn off spike

Total turn off time

Switching frequency

The current at which mosfet turns off – For all conduction modes, will be the maximum peak current in the mosfet.

Gate losses
Gate losses are due to the gate charge losses and the power loss on the internal gate resistor due to gate current.

Where,

Total gate losses

Gate charge losses

Losses on the internal gate resistance

Gate charge losses
The total gate charge of the mosfet has to be found out from the datasheet curve for the working gate voltage.

Gate charge losses can be found out from the equation below

Where,

Total gate charge from datasheet curve

Gate-source driver supply voltage

Switching frequency

Losses in internal gate resistance
When the gate current flows through the internal gate resistance, the ohmic losses contribute a minor portion in the total losses. The total gate charge divided by the time taken for charge and discharge respectively will give the average current while charging and discharging. The figure 6 below explains the charging and discharging characteristics of mosfet.


Figure 6 – Mosfet gate characteristics – turn on and turn off

At time

, input capacitor | charges from 0 to gate threshold | through | . The time

is
given by the equation;
(

)

At time

, capacitor | charges at gate threshold | through | . The time

is given by the
equation;
(

)

At time

, capacitor | charges from gate threshold voltage | to final value of the applied gate
voltage | through | . The time | can be found out from the capacitor time constant equation
considering 98% charge.

At time

, input capacitor | discharges from | to gate threshold | through | . The time
is given by the equation;
(

)

At time

, capacitor | discharges at gate threshold | through | . The time
| | | | is given by
the equation;
(

)

At time

, capacitor | discharges from gate threshold voltage | to 0 through | . The time
can be found out from the capacitor time constant equation considering 98% discharge.

Total charging time and discharging time is given by

The average current during turn on and turn off is given by

Average power loss in gate resistor is given by

(

) (

)

Where,

The average gate current during on time and off time

Total charging time and discharging time

### MosFET Design Considerations

There are certain things to be considered while selecting a mosfet. The major two things which effect the switching are listed below

•

⁄ protection

- External gate resistor selection
- Gate-source resistor selection

dV/dt Protection
When the mosfet turns on and off, drain to source voltage changes very fast. While this process, there is chance that false turn on may occur or at certain conditions, catastrophic failure may occur if the dV/dt is not limited. While turn on and turn off of the mosfet, the dV/dt can occur. The turn on time dV/dt protection can be given by connecting a resistor across mosfet gate to source and turn off time protection can be given by selecting the external gate resistor properly.

There are two ways dV/dt can occur while turn off. The maximum rate of rise of drain to source voltage is limited by the peak reverse recovery of body diode. While the mosfet is turning off, the drain to source voltage rises, the miller capacitor discharges through the gate resistor and creating a voltage drop across gate to source. If this voltage drop exceeds the gate threshold value, the mosfet turns on again, this may lead into failure. Another mechanism of false turn on is due to the parasitic BJT appears across drain and source of mosfet.

Turn off dV/dt protection can be given by selecting lower turn off impedance

| . One common
method is to provide a diode to bypass some resistance in the turn on path.

When the mosfet is used in inverter or freewheeling applications, the body diode conducts at some switching times, there the reverse recovery should be considered for maximum dV/dt.

External Gate resistor selection
The external gate resistor has to be selected according to two parameters
- dV/dt Protection
- Gate drive current capability

Gate resistor selection based on dV/dt protection – turn off
The maximum dV/dt limit can be found out by the equation below. One important parameter to consider is the negative temperature coefficient in the gate threshold voltage. At higher temperatures, the gate threshold voltage will considerably reduce due to this negative temperature coefficient.

(

- )

Where,

the maximum allowable dV/dt

Gate threshold voltage

Gate threshold voltage temperature coefficient

Mosfet junction temperature

Internal gate resistance

Gate to drain capacitor = Reverse transfer capacitor at working

Figure 7 below shows the mosfet turn off equivalent circuit with a gate drive circuitry.


Figure 7 – Mosfet gate turn off path with gate drive

The gate resistance at turn off is the sum of internal gate resistance, external gate resistance and the turn off impedance of gate drive circuitry.

Where,

Internal gate resistance

External gate resistance

Gate drive resistance

The maximum possible external gate resistance value depends upon the actual dV/dt present in the circuit. Maximum turn off resistance is given by

(

)
(

)

Where,

(

)
the maximum dV/dt possible in the circuit

has to be selected which is lesser than the maximum value obtained from equation 1 and 2. Another factor to be considered is if the external gate resistor selected is too low, which reduces the fall time where the current falls very fast, which in turn increases the dI/dt and hence the spike in drain source voltage. Thus care should be taken to select the proper gate resistance.

Gate resistor selection based on gate drive current capability – turn on
The on time gate resistor selection is based upon the gate drive current capability. Lower the value of gate resistor, smaller the turn on time, but higher the gate current. While selecting the gate resistor, the gate drive current has to be taken into account. Again higher dV/dt causes switching noises which appear as radiated emission.

The minimum turn on gate resistance is given by

Where,

Maximum on time gate current, which is limited by the gate driver

Gate-Source resistor selection
The gate to source resistor is important in giving dV/dt protection while mosfet turn on. A resistance value lesser than the maximum can be selected which is depending upon the maximum possible dV/dt appearing in the mosfet. The maximum value of gate source resistor is given by the equation below

(

)
(

)

Where,

The maximum value of Gate to Source resistance
(

)
The maximum dV/dt possible in the circuit

Steps to find the gate resistors
Selecting a gate resistor is an iterative process. Even if theoretically matches also, while doing the EMI EMC tests the gate resistor tuning may be required, as the stray inductance completely depends upon the switching tracing in PCB, mosfet leads, soldering etc.

Steps to find the turn off resistance

STEP 1 : Find the maximum dV/dt limit from the equation (If esr is not given in mosfet datasheet, use the gate source ESR value)

(

)

STEP 2 : Select a dV/dt lesser than the limit – use approximations like select fall time from datasheet to start with and from design with 20% spike voltage.
STEP 3 : Find the maximum off time gate resistance and hence the maximum external gate resistance possible from the equations below – use available values, omit if not known.

(

)
(

)

STEP 4 : Select nearest standard value for external gate resistance and find the fall time and turn off delay time.
(

)

(

)

STEP 5 : Find the mosfet turn off spike voltage generated by the stray inductances- consider 20nH for approximation.
STEP 6 : Find the actual maximum dV/dt from equation below. Check if the dV/dt max is less than the dV/dt limit. If yes, proceed to STEP 7, else go to STEP 3 and substitute lesser value of dV/dt max.
STEP 7 : Find the turn off losses in the mosfet and check whether the value is acceptable or not. If acceptable we have the external gate resistance value, if not acceptable reduce the dV/dt further and repeat the steps from STEP 3 onwards until a satisfactory result is achieved.

(

) | (

)

Steps to find the turn on resistance

STEP 1 : Find the maximum gate drive current possible from the driver and find the gate resistance required.
STEP 2 : Check if the minimum value obtained from STEP 1 is lesser than the sum of internal and external gate resistors at turn off. If its lesser, use the same external resistance for on time also, else select the nearest standard value and proceed to next step.
STEP 3 : Calculate the turn on delay time, rise time and turn on losses.
(

)

(

)

(

) (

)

Steps to find gate source resistance

STEP 1 : Find the maximum gate source resistor for the turn on dV/dt calculated as below and select the nearest standard value lesser than the maximum.
(

)

(

)
(

)

Sample calculation

### References

[1]. Power MOSFET Basics: Understanding Gate Charge and Using it to Assess Switching Performance - Device Application Note AN608A- VISHAY SILICONIX
[2]. Power MOSFET Electrical Characteristics Application Note – Toshiba
[3]. Power MOSFET Basics By Vrej Barkhordarian, International Rectifier, El Segundo, Ca.
[4]. Fundamentals of MOSFET and IGBT Gate Driver Circuits - Application Report SLUA618A- Texas Instruments
[5]. PowerMOSFET Application Note - AN-080E Rev.1.1- Fuji Power MOSFET
[6]. Understanding power MOSFET data sheet parameters - application note AN11158 – Nexperia [7]. AN-9010 MOSFET Basics - Fairchild

### EMI-EMC

Electro- magnetic interference (EMI) can be defined as the electro magnetic energy which affects the functioning of an electronic device. Electromagnetic compatibility (EMC) is the devices ability to work in noisy environment. The measure of emi generated by the device which is known as emission testing, and the assessing the proper functioning of a device under electro-magnetic energy field is known as susceptibility or immunity.

### EMC standards and limits

CISPR11-FCC Part 15C

The measure for emi noise generation is of two types

Conducted emission and radiated emission

Conducted emission is the disturbance produced by the power electronic converter in the ac mains when it is operating. The frequency range for conducted emission measurement is 150kHz to 30MHz.

Radiated emission is the electro magnetic energy waves produced by the power electronic circuit in a near field through air. The frequency range starting from 30mHz to 1GHz.

The equipments are classified into groups and classes as per the CISPR11 standard.

Class A equipment is equipment suitable for use in all establishments other than domestic and those directly connected to a low voltage power supply network which supplies buildings used for domestic purposes

Class B equipment is equipment suitable for use in domestic establishments and in establishments directly connected to a low voltage power supply network which supplies buildings used for domestic purposes

The tables below shoes the conducted and radiated noise levels in class B equipments


### Common mode noise and differential mode noise

The figure below explains the common mode and differential mode noises

In differential mode noise, the noise source appears across power supply lines and is in series with the power supply line, and the noise current flows in the same direction as the power supply current. It is called "differential mode" because the outgoing and return currents are oppositely-directed.

Common mode noise is noise in which a noise current that has leaked via a stray capacitance or the like passes through ground and returns to the power supply line. It is called "common mode" noise because the direction of the noise currents on the positive (+) and the negative (-) sides of the power supply have the same direction. A noise voltage does not appear across the power supply lines.

The noise appearing in switching power supplies can be well explained using figure below.


Figure 1 Common mode and differential mode noise

The differential mode noises is due to the high speed turn on and turn off of switching elements which in turn produces the ringing between the trace inductance and stray capacitances. The current and voltage are given by the equations

The mosfet turn on and turn off ringing are due to the LC tank circuits appearing for the switching time.

### Radiation

The figure below shows the radiation due to differential mode appearing at a point at a distance r from the loop with an area S, which is having a loop current of Id and a frequency f. The equation of electric field intensity is given by the equation in the figure


Figure 1 : radiation due to differential mode noise

The figure shows the radiation due to common mode noise which varies depending upon the cable length, common mode current and frequency.


Figure 2 : radiation due to common mode noise

### References

[1]. EMC Basics verA2 – Rohm Semiconductor [2].

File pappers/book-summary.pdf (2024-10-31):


# Power Electronics Step-by-Step

# Power Electronics Step-by-Step

Design, Modeling,

# Simulation, and Control

## Weidong Xiao

University of Sydney

New York Chicago San Francisco Athens London Madrid
Mexico City Milan New Delhi Singapore Sydney Toronto

Library of Congress Control Number: 2020949938

McGraw Hill books are available at special quantity discounts to use as premiums and sales promotions or for use in corporate training programs. To contact a representative, please visit the Contact Us page at www.mhprofessional.com.

Power Electronics Step-by-Step: Design, Modeling, Simulation, and Control

Copyright © 2021 by McGraw Hill. All rights reserved. Printed in the United States of America. Except as permitted under the United States Copyright Act of 1976, no part of this publication may be reproduced or distributed in any form or by any means, or stored in a data base or retrieval system, without the prior written permission of the publisher.

1 2 3 4 5 6 7 8 9 LCR 25 24 23 22 21 20

ISBN 978-1-260-45697-4
MHID 1-260-45697-8

This book is printed on acid-free paper.

Sponsoring Editor
Lara Zoble

Editorial Supervisor
Stephen M. Smith

Production Supervisor
Lynn M. Messina

Acquisitions Coordinator
Elizabeth M. Houde

Project Managers
Poonam Bisht and
Rishabh Gupta, MPS Limited

Copy Editor
Mohammad Taiyab Khan, MPS Limited

Proofreader
Nicole Schlutt

Indexer
Michael Ferreira

Art Director, Cover
Jeff Weeks

Composition
MPS Limited

Information contained in this work has been obtained by McGraw Hill from sources believed to be reliable. However, neither McGraw Hill nor its authors guarantee the accuracy or completeness of any information published herein, and neither McGraw Hill nor its authors shall be responsible for any errors, omissions, or damages arising out of use of this information. This work is published with the understanding that McGraw Hill and its authors are supplying information but are not attempting to render engineering or other professional services. If such services are required, the assistance of an appropriate professional should be sought.

To my son, William, and my daughter, Emily

About the Author
Weidong Xiao is Associate Professor in the School of Electrical and Information Engineering and the Centre for Future Energy Networks at the University of Sydney. His research involves modeling, design, simulation, and control of power electronics with focus on photovoltaic power systems. Dr. Xiao has authored one book and hundreds of technical papers and is on an editorial board at IEEE.

# Contents

ix

x | Contents
2.6 | Passive Components | | 41
2.7 | Circuits for Low-Pass Filtering | | 43
2.8 | Summary | | 47
Bibliography | | 48
Problems | | 49
3 | Non-Isolated DC/DC Conversion | | 51
3.1 | Pulse Width Modulation | | 51
| 3.1.1 | Analog PWM | | 51
| 3.1.2 | Digital PWM | | 53
3.2 | Operational Condition | | 54
| 3.2.1 | Steady State | | 54
| 3.2.2 | Nominal Operating Condition | | 55
3.3 | Buck Converter | | 55
| 3.3.1 | Steady-State Analysis | | 57
| 3.3.2 | Continuous Conduction Mode | | 58
| 3.3.3 | Discontinuous Conduction Mode | | 59
| 3.3.4 | Boundary Conduction Mode | | 60
| 3.3.5 | Case Study and Circuit Design | | 61
| 3.3.6 | Simulation of Buck Converter for
| | Concept Proof | | 63
3.4 | Boost Converter | | 67
| 3.4.1 | Steady-State Analysis | | 67
| 3.4.2 | Continuous Conduction Mode | | 69
| 3.4.3 | Boundary Conduction Mode | | 69
| 3.4.4 | Discontinuous Conduction Mode | | 70
| 3.4.5 | Circuit Design and Case Study | | 72
| 3.4.6 | Simulation and Concept Proof | | 73
3.5 | Non-Inverting Buck-Boost Converter | | 76
3.6 | Buck-Boost Converter: Inverting Version | | 79
| 3.6.1 | Steady-State Analysis | | 79
| 3.6.2 | Continuous Conduction Mode | | 80
| 3.6.3 | Boundary Conduction Mode | | 80
| 3.6.4 | Discontinuous Conduction Mode | | 81
| 3.6.5 | Circuit Design and Case Study | | 82
| 3.6.6 | Simulation and Concept Proof | | 83
3.7 | Cuk Converter ´ | | | 85
| 3.7.1 | Steady-State Analysis | | 86
| 3.7.2 | Specification and Circuit Design | | 88
| 3.7.3 | Modeling for Simulation | | 89
3.8 | Synchronous Switching | | 92
3.9 | Summary | | 92
Bibliography | | 94
Problems | | 94

Contents | xi
4 | Computation and Analysis | | 97
4.1 | Root Mean Square | | 97
4.1.1 | DC Waveforms | | 99
4.1.2 | AC Waveforms | 101
4.2 | Loss Analysis and Reduction | 101
4.2.1 | Conduction Loss | 102
4.2.2 | Switching Loss | 102
4.2.3 | Cause of Switching Delay | 104
4.2.4 | Minimization of Switching Loss | 104
4.3 | Gate Driver | 106
4.3.1 | Low-Side Gate Driver | 107
4.3.2 | High-Side Gate Driver | 108
4.3.3 | Half-Bridge Driver | 109
4.4 | Fourier Series | | 110
4.5 | Power Quality of AC | | 110
4.5.1 | Displacement Power Factor | | 111
4.5.2 | Total Harmonic Distortion | | 112
4.6 | Power Quality of DC | | 114
4.7 | Thermal Stress and Analysis | | 116
4.8 | Summary | | 118
Bibliography | | 118
Problems | | 119

### 5 DC to Single-Phase AC Conversion | 123

5.1 | Square Wave AC | 124
5.1.1 | Chopping | 125
5.1.2 | Phase Shift and Modulation | 125
5.1.3 | Total Harmonic Distortion | 128
5.2 | Sine-Triangle Modulation | 129
5.2.1 | Bipolar Pulse Width Modulation | 129
5.2.2 | Unipolar Pulse Width Modulation | 131
5.2.3 | Moving Average and Filtering Circuit | 133
5.3 | Two-Switch Bridge for DC/AC | 134
5.4 | Modeling for Simulation | | 135
5.4.1 | Bridge Model | 135
5.4.2 | Phase Shift Modulation | 136
5.4.3 | Bipolar Pulse Width Modulation | 136
5.4.4 | Unipolar Pulse Width Modulation | 137
5.4.5 | Integrated Modes for Simulation | 137
5.5 | Case Study | 138
5.5.1 | Chopped Square AC Output | 138
5.5.2 | Sinusoidal AC Output | 139
5.6 | Summary | 140
Bibliography | 141
Problems | 141

xii Contents

### 6 Single-Phase AC to DC Conversion | 143

6.1 | Half-Wave Rectification | 143
6.1.1 | Capacitor for Filtering | 144
6.1.2 | Case Study | 145
6.2 | Full-Wave Bridge Rectifier | 145
6.2.1 | Capacitor for Filtering | 146
6.2.2 | Inductor for Filtering | 148
6.2.3 | LC Filter | 150
6.3 | Active Rectifier | 153
6.4 | Alternative Configuration | 155
6.4.1 | Synchronous Rectifier | 155
6.4.2 | Center-Tapped Transformer | 156
6.5 | Modeling for Simulation | 157
6.5.1 | C Filter for One-Diode Rectifier | 157
6.5.2 | Full-Wave Rectifier without Filtering | 158
6.5.3 | Full-Wave Rectifier with C Filtering | 159
6.5.4 | Full-Wave Rectifier with L Filter | 161
6.5.5 | Full-Wave Rectifier with LC Filter | 161
6.5.6 | Active Rectifier | 163
6.6 | Summary | 164
Bibliography | 165
Problems | 165

### 7 Isolated DC/DC Conversion | 167

7.1 | Region of Magnetic Field | 167
7.1.1 | Operational Quadrant and Classification | 168
7.1.2 | Critical Checkpoint for Saturation | 169
7.2 | Flyback Topology | 169
7.2.1 | Derivation from Buck-Boost Converter | 170
7.2.2 | Flyback Operation | 171
7.2.3 | Continuous Conduction Mode | 172
7.2.4 | Discontinuous Conduction Mode | 173
7.2.5 | Circuit Specification and Design | 174
7.2.6 | Simulation for Concept Proof | 175
7.3 | Forward Converter | 177
7.3.1 | Two-End-Switching Topology | 177
7.3.2 | One-Transistor Solution | 180
7.3.3 | Circuit Specification and Design | 181
7.3.4 | Simulation for Concept Proof | 182
7.4 | Synchronous Rectification | 183
7.5 | Full Bridge for DC/AC Stage | 185
7.5.1 | Steady-State Analysis | 186
7.5.2 | Circuit Specification and Design | 187
7.5.3 | Simulation for Concept Proof | 188
7.6 | Push-Pull Converters | 189
7.7 | Variation and Enhancement | 191

Contents | xiii
7.8 | Summary | 192
Bibliography | 194
Problems | 194

### 8 Conversion Between Three-Phase AC and DC | 197

8.1 | DC/AC Conversion | 197
8.1.1 | Bridge and Switching Operation | 197
8.1.2 | 180◦ Modulation | 200
8.1.3 | Sine-Triangle Modulation | 202
8.1.4 | Modeling for Simulation | 204
8.1.5 | Case Study and Simulation Result | 205
8.2 | AC/DC Conversion | 207
8.2.1 | Passive Rectifier for Three Pulses per Cycle | 207
8.2.2 | Passive Rectifier for Six Pulses per Cycle | 209
8.2.3 | Passive Rectifier for 12 Pulses per Cycle | 210
8.2.4 | Active Rectifier | | 211
8.2.5 | Simulation | 213
8.3 | AC/AC Conversion | 214
8.4 | Summary | 216
Bibliography | 216
Problems | 217

### 9 Bidirectional Power Conversion | 219

9.1 | Non-Isolated DC/DC Conversion | 219
9.2 | Dual Active Bridge | 221
9.2.1 | Forward Power Flow | 222
9.2.2 | Reverse Power Flow | 225
9.2.3 | Zero-Voltage Switching | 227
9.2.4 | Losing Zero-Voltage Switching | 231
9.2.5 | Critical Phase Shift for ZVS | 233
9.2.6 | Simulation and Case Study | 235
9.3 | Conversion Between DC and AC | 236
9.3.1 | Between DC and Single-Phase AC | 237
9.3.2 | Between DC and Three-Phase AC | 237
9.4 | Summary | 238
Bibliography | 239
Problems | 239

### 10 Averaging for Modeling and Simulation | 241

10.1 Switching Dynamics | 241
10.2 Continuous Conduction Mode | 242
10.2.1 Buck Converter | 242
10.2.2 Dynamic Analysis of Second-Order Systems | 244
10.2.3 Boost Converter | 246
10.2.4 Buck-Boost Converter | 247

xiv Contents

10.3 Discontinuous Conduction Mode | 249
10.3.1 Buck Converter | 249
10.3.2 Boost Converter | 250
10.3.3 Buck-Boost Converter | 251
10.4 Integrated Simulation Model | 252
10.4.1 Buck Converter | 252
10.4.2 Boost Converter | 253
10.4.3 Buck-Boost Converter | 255
10.5 Summary | 256
Bibliography | 257
Problems | 257
| 11 Linearized Model for Dynamic Analysis | 259
11.1 General Linearization | 259
11.2 Linearization of Dual Active Bridge | 261
11.3 Linearization Based on CCM | 263
11.3.1 Boost Converter | 263
11.3.2 Buck-Boost Converter | 266
11.3.3 Non-Minimal Phase | 269
11.4 Linearization Based on DCM | 271
11.5 Summary | 271
Bibliography | 272
Problems | 273
| 12 Control and Regulation | 275
12.1 Stability and Performance | 275
12.2 On/Off Control | 276
12.2.1 Hysteresis Control | 277
12.2.2 Case Study and Simulation | 278
12.3 Affine Parameterization | 279
12.3.1 Design Procedure | 280
12.3.2 Desired Closed Loop | 281
12.3.3 Derivation of Q(s) and C(s) | 282
12.3.4 Relative Stability and Robustness | 283
12.4 Controller Implementation | 286
12.4.1 Digital Control | 286
12.4.2 PID Controllers | 288
12.4.3 Analog Control | 289
12.4.4 Case Study for Buck Converter | 290
12.4.5 Case Study for Boost Converter | 292
12.5 Cascade Control | 293
12.5.1 Case Study and Simulation | 294
12.5.2 Advantage | 295
12.6 Windup Effect and Prevention | 296
12.6.1 Case Study and Simulation | 296
12.6.2 Anti-Windup | 297

Contents xv

12.7 Sensing and Measurement | 299
12.7.1 Voltage Sensing and Conditioning | 300
12.7.2 Current Sensing and Conditioning | 302
12.8 Summary | 303
Bibliography | 304
Problems | 305
Acronyms | 307
Index | 311

# Preface

P
ower electronics has drawn significant attention in recent years because of the trend toward modern electrical systems, the variety of load profiles, and the high demand for integrating renewable energy. Although there are quite a few books on the subject available for use in academia and industry, there is a lack of proper guidebooks for beginners and self-learners to learn modern power electronics efficiently. Traditional power electronics instructors focus on AC/DC and AC/AC conversion because AC has been dominant among applications since the 1880s. For example, many books put great emphasis on the analysis and design of various AC/DC rectifiers using either diode or thyristor bridges, usually with the consideration of all kinds of load profiles. However, some topologies have been phased out due to stricter power quality requirements and limited functionality. The latest power electronics relies on active switching technologies using modern power semiconductors. One distinguishing characteristic of this book is the focus on the latest technologies and solutions.
The topologies for non-isolated DC/DC conversion are introduced at the beginning to demonstrate the switching concept, which is fundamental in power electronics. The concept is essential for learners because an increasing proportion of generation and load units is based on DC instead of AC. In particular, one chapter is dedicated to bidirectional DC power flow devices, which are widely used for rechargeable batteries, ultracapacitors, and solid-state transformers. Throughout the book, the instructions for each important subject in power electronics are given within a clear framework. The step-by-step approach is aimed at helping readers build up their knowledge progressively. For example, the knowledge of DC/AC (Chap. 5) and AC/DC (Chap. 6) conversion naturally leads to the discussion of galvanic isolated DC/DC converters (Chap. 7) since many topologies are based on the integration of both conversion stages, which finally join together as DC/AC/DC configurations with isolation transformers. The insights of the step-by-step approach come from the author’s self-learning and teaching experience in power electronics and renewable power systems.
Dynamic modeling methods are properly categorized into multiple classes, including switching, averaging, and small-signal models, following the scales of linearity from highly nonlinear to piecewise linear. The switching dynamics leads to the development of detailed simulation models that are only based on basic blocks in MATLAB/Simulink, which is a commercial software widely available in universities. In particular, averaging dynamic modeling mostly leads to switching-agnostic models that can be utilized for fast simulation and nonlinear control measures. It has been proven effective in simulating long-term operations of a system with a large number of power converters and

## xvii

xviii | Preface
| distributed generation units. Moreover, the final phase of dynamic modeling features linearized mathematical functions, based on dynamic analysis and linear control theory. For a closed-loop controller design, the technique of affine parameterization is intro- duced, which translates controller parameters to stability and performance. The step- by-step approach allows readers to understand the basics of system simulation and to bridge the gap between linear control theory and power electronics.

This book can serve as a reference book as well as the textbook in a senior-level uni-
| versity course related to the subject of power electronics. It also covers practical design subjects that can be very useful for readers in industry who seek to master the subject matter through self-study or professional training. Familiarity with the fields of electron- ics, signal theory, and linear control engineering is recommended so as to fully benefit from this book.

## Key Features

| This book is comprehensive in covering the fundamental subjects in modern power elec- tronics and control engineering. The book is organized as follows:
- The common platforms and tools for developing power electronics are introduced at the beginning.
- A comprehensive classification of power electronics applications is presented in terms of signal waveforms, power flow directions, and voltage levels.
- One important feature of this book is the emphasis on computer-aided analysis, design, and evaluation. Without losing generality, all simulation models are built and mathematical analyses are carried out using the fundamental blocks in Simulink.
- Gate drivers for power switches, which are essential for modern power electronics, are covered.
- The book also covers the topologies used for bidirectional DC/DC conversion, which has been widely adopted in industry because of the increasing usage of energy storage, such as rechargeable batteries.
- Modeling for simulation follows a modular and step-by-step approach such that a converter system is divided into individual blocks, including the power train, low-pass filtering, load, modulation, and control. The development follows the operational principle and creates a clear framework that makes it easy to understand, construct, and debug.
- Simulation models are built for most converter topologies and related modulation methods for readers to follow.
- A dedicated chapter is provided to demonstrate the averaging technology for modeling and simulation purposes. The averaging methodology is general and covers not only continuous conduction mode but also discontinuous conduction mode.
- The development of mathematical models for dynamic analysis and controller synthesis is separate from the discussion on converter simulation. Linearization and small-signal methodology are utilized to mathematically construct linear

Preface xix

models to accommodate the well-established linear control theory for the analyses of damping, speed, stability, and robustness.
- Most chapters provide a significant number of practical examples in the form of case studies in order to demonstrate and verify the design. Readers can duplicate the results through various computer-aided design and analysis platforms, which also provide a systematic way to develop and evaluate new systems.
- Abundant photos, diagrams, graphs, equations, and tables appear throughout the book for a clear explanation of the subject matter. A significant number of flowcharts have been drawn to show the procedures of system design as well as component selection in a step-by-step manner.
- A brief introduction to tools and types of equipment is recommended for those who wish to practice power electronics, including electrical computer-aided design, simulation platforms, and hardware.
- A comprehensive summary is presented at the end of each chapter.

## Organization by Chapter

The book is divided into 12 chapters, organized in such a way as to provide easy following and understanding. The text provides step-by-step introductions of the individual components and controls for power electronics systems. A brief description of each chapter follows:
Chapter 1 provides a brief background about power electronics. Some important terms are clarified in this chapter to avoid ambiguity.
Chapter 2 introduces important components of power electronics. The power electronics industry came into existence upon the diode’s invention. Switching technology led to the development of various transistors and thyristors. The characteristics of power inductors, capacitors, and resistors are discussed in this chapter.
Chapter 3 introduces the best-known topologies for non-isolated DC/DC conversion, namely buck, boost, buck-boost, and C`uk. Simulation verification accompanies each design state.
Chapter 4 focuses on power computation to evaluate power equivalence, loss analysis, and power quality, which naturally leads to the necessity of gate driver circuits. Chapter 5 discusses DC to single-phase AC conversion, especially the bridge circuit and modulation methods to achieve the design objective.
Chapter 6 introduces power conversion from single-phase AC to DC and addresses the related power quality concerns.
Chapter 7 focuses on isolated DC/DC conversion, which is an advanced arrangement built on the topologies in previous chapters.
Chapter 8 deals with three-phase AC power conversion. It covers DC/AC, AC/DC, and AC/AC conversion. The modulation for DC to three-phase AC conversion is also introduced.
Chapter 9 focuses on the topologies for bidirectional power conversion, featuring non-isolated DC/DC, isolated DC/DC, and DC/AC converters. A special topology is introduced and analyzed, which is the dual active bridge.

xx Preface

Chapter 10 introduces an averaging technique for dynamic modeling and fast sim-
| ulation of different converters in the cases of continuous conduction modes and discon- tinuous conduction modes.

Chapter 11 discusses mathematical modeling of power converters for dynamic anal-
| ysis. Linearization is widely used to derive the small-signal models. The non-minimal- phase issue is also discussed.

Chapter 12 provides control system analysis and design. Affine parameterization is
| introduced as a systematic way to synthesize controllers for power conversion regarding the balance of stability, robustness, and performance.

## Acknowledgments

| I would like to thank Mr. Jacky Han for a great work of proofreading, technically and grammatically. Special thanks go to Ms. Lara Zoble, Senior Editor in the Professional Group at McGraw Hill, for providing professional support for this project through all phases. Since I was busy writing this book for the past two years, I missed sharing quality time with my family members. Hence, last but not the least, I heartily thank all of them for their great patience and understanding, because without their continuous support and sacrifices this book would not have been possible.

## Technical Support

| All modeling and simulation for case studies in this book were developed by the basic functions of Simulink®
and MATLAB®
, which will help readers understand the fun-
| damental principles behind various simulation tools. Version R2018b or higher of the MATLAB®
and Simulink®
software can be used to repeat the results of the example
| cases or to develop new studies accordingly.

Weidong Xiao

# Power Electronics Step-by-Step

# CHAPTER 1

# Background

D
irect current (DC) flows in only one direction of electric charge, whereas its counterpart, alternating current (AC), periodically reverses current flowing direction. These two forms of currents widely present in power electronics and power systems. The “battle of the currents” refers to the significant debate and competition of electric power transmission systems in the United States, either AC or DC, in the late 1880s. It turned out that the AC-based power distribution and transmission prevailed because of its more cost-effectiveness and efficiency than DC. Power grids started with AC-based networks. Thanks to the early development of line-frequency (LF) power transformers, AC voltage can be either “stepped up” or “stepped down” to achieve different voltage levels. For a given level of power, higher voltage indicates less current flow and lower conduction loss in the transmission. Up to now, the LF power transformer is still the backbone in the power grids around the world to support high-voltage (HV) power transmission, medium-voltage (MV) distribution, and low-voltage (LV) supply to end-users. The lack of power electronics is considered one of the critical reasons leading to the failure of DC in the “battle of the currents’’ and the dominance of AC in the present power networks.
Technological development brings optimism that DC will eventually win, since the recent trend indicates more and more DC-based power generation, transmission, distribution, and applications. DC can eliminate the long-term difficulties of AC related to its frequency stability, power factor, synchronization, and interconnection. For example, the renewable resource of photovoltaic and fuel-cell generators produces DC. The utilization of energy storage of rechargeable batteries is mainly through DC. These components are important to represent the future energy network in terms of “smart” and “green” energy systems. Meanwhile, the steep growth of DC-powered loads is due not only to the computer-related products but also to the spread of devices for lighting and home appliances. Even though the majority of electric motors are conventional AC devices, high performance can only be realized by using the driver system, which is based on power electronics and mostly supplied by DC. High-voltage DC (HVDC) is becoming the norm for long-distance power transmission, thanks to the advantage of low loss and simple interconnection. The broad utilization and fast advance of power electronics make DC weigh more than before for all different voltage levels, such as high voltage (HV), medium voltage (MV), low voltage (LV), and extra-low voltage (ELV). Power electronics uses the solid-state technology to convert, process, and regulate electric power flow in terms of voltage and current from one form to another. The static power conversion technology serves as the power interface for a variety of applications. The industry started with the invention of the p-n junction to produce diodes. It boomed with the availability of thyristors thanks to the turn-on controllability. The power semiconductor devices can achieve safe and efficient power conversion and regulate the
1

### 2 Chapte r One

different levels of voltage, current, and power. Recently, the rapid growth of power electronics is considered as the backbone of modernized power systems, high-efficiency power supplies, and future energy networks because of the following factors:

- Advances in power semiconductor devices for controllable, high-efficiency, reliable, and versatile implementations.
- Trend toward modern electrical systems regarding distributed power generation, modular energy storage, and renewable power generation.
- Rise of portable consumer electronics and high-efficiency appliances.
- Advances and maturity of control engineering regarding both hardware and software to achieve high-performance and reliable operation.
- Demand for high-efficiency power supply systems to reduce pollution and retire low-efficiency devices.

## 1.1 Classification of Power Conversion

The level of power conversion can be different from the milliwatt to megawatt capacity. Various criteria can be applied to classify the system of power electronics. A device that converts power signals from one form to another is commonly called “converter,” which has become the most common term in power electronics. Therefore, one classification can be based on the conversion form in terms of DC and AC:

- AC-to-DC conversion (AC/DC)
- DC-to-AC conversion (DC/AC)
- DC-to-DC conversion (DC/DC)
- AC-to-AC conversion (AC/AC)

The AC-to-DC converter is commonly called a “rectifier,” referring to the rectification operation. Meanwhile, the DC-to-AC converter is sometimes called the “inverter.” Figure 1.1 illustrates the blocks to present the classification of AC/DC, DC/AC, DC/DC, and AC/AC. These will be applied in system diagrams throughout the book.
Another classification is based on the direction of active power flow in steady state. For example, rechargeable batteries require bidirectional power flow to charge and discharge when one converter is utilized for the power interface. The same operation is commonly required for the power conversion to interface ultracapacitors. Thus, the power conversion can be classified as either unidirectional or bidirectional, as illustrated in Fig. 1.2. The input and output ports can be clearly identified in the unidirectional power conversion. The input port is always connected to the source; meanwhile, the load is linked to the output port. When energy storage is applied, e.g., rechargeable batteries, the definition of input and output ports is no longer clear for
(a) | (b) | (c) | (d)

FIGURE 1.1 Blocks of power conversion: (a) AC/DC; (b) DC/AC; (c) DC/DC; (d) AC/AC.

Background | 3
Input: | voltage
source

Output:
load current

Converter

Converter

voltage
current

voltage
current

voltage
current

(a)

(b)

FIGURE 1.2 Diagrams showing power conversion: (a) unidirectional; (b) bidirectional.

the bidirectional converters. The DC terminal of rechargeable batteries can be either the source or load, depending on the conversion operation. The bidirectional power conversion shows fast growth due to the wide utilization of rechargeable batteries. The bidirectional power conversion can have any of the following forms: AC/DC, DC/AC, DC/DC, and AC/AC.
Classification can be defined and based on the voltage level. Power converters are widely utilized to supply portable devices, such as tablets, mobile phones, and laptops, which are classified as the group of extra-low-voltage (ELV) applications. Based on the average value of human body resistance, the voltage level is usually considered as low risk to life. Other voltage levels are higher and pose a threat to life; therefore, devices having such a higher voltage should be strictly isolated from human contacts. The following definitions are considered as a reference for the discussion and analysis that follow.
- Extra-low voltage (ELV): <50 V
- Low voltage (LV): 50–1000 V
- Medium voltage (MV): 1–35 kV
- High voltage (HV): 35–230 kV
- Extra-high voltage (EHV): >230 kV

Classification of voltage levels can be sourced from the International Electrotechnical Commission (IEC). It should be noted that the voltage rates listed above are just for a general reference. The strict definition varies for DC and AC, and is different from one country to another. Figure 1.3 demonstrates the diagrams of power systems indicating various voltage levels at the different conversion stages. Theoretically, the higher the voltage level, the lower the conduction loss for long-distance transmission and distribution.
The conventional power system is represented by the highly centralized grid structure, as shown in Fig. 1.3a. The power from the centralized power generation facility is eventually delivered to end-users through the networks of transmission and distribution. Voltage conversion mainly relies on power transformers. The modernized network adopts more renewable energy resources, distributed power generations, demand response, and energy storage. The impact of microgrids and smart grids is likely to change the future grid infrastructure, especially at the distribution levels, as illustrated in Fig. 1.3b. An important element of such power systems is the prosumer that is able to supply power to grids from the local power generation system. Power electronics eventually plays an important role in supporting the transition into modern

### 4 Chapte r One

Centralized
Generation

(a)

(b)

Centralized
Generation

Transmission
HV or EHV

Transmission
HV or EHV

Distribution
&
MV loads

MV distribution,
loads, storage,
and generation

LV & ELV supply,
loads, storage, EVs,
and generation

LV supply
&
loads

ELV supply
&
loads
HV | HV | MV | LV | LV | ELV
MV | HV HV | MV | MV | LV
MV | MV

FIGURE 1.3 Conversion for power systems: (a) conventional; (b) modernized.

Dynamics and control engineering; Electromagnetics; Power; Electronics; Thermal analysis; Electric machines; Solid-state physics; Circuit theory; Power systems; Signal processing; Simulation and computing

FIGURE 1.4 Interdisciplinary nature of power electronics.

electrification. The bidirectional power conversion will be demanded at different levels to make the future system efficient, adaptable, reliable, and more.

## 1.2 Interdisciplinary Nature of Power Electronics

Power electronics is commonly considered as the bridge between the power engineering and electronic application. The subject actually covers many technologies more than power and electronics. The interdisciplinary nature of power electronics is illustrated in Fig. 1.4.
Accurate power conversion cannot be realized without the support of control engineering. Modern power electronics tends to use digital control technology and relies on fast computing hardware and digital signal processors to improve control capability and performance. The solid-state components of electromagnetics and electronics form the foundation of power electronics. The power switching operation relies on the advances in power semiconductor devices to reduce both conduction and high-frequency loss.

Background 5

System analysis and design are always based on circuit and electromagnetic theories. Fast computer simulation has become a norm for the concept proof and guides for system improvement. Additionally, more and more power conversions are digitally controlled by various computational devices such as microprocessors, digital signal processors, microcontrollers, and field-programmable gate array (FPGA). Electric machines bridge mechanical engineering and electrical engineering, but rely on power electronics to efficiently and accurately drive the motion and convert generating power for utilization. Thermal analysis is commonly linked to mechanical analysis and design but becomes an important sector to support the highly efficient and reliable power conversion.

## 1.3 Typical Applications

The telecommunications industry mainly relies on DC and uninterrupted power supplies (UPS), which require the conversion of AC/DC and DC/DC. The DC power traditionally supports the operation of signal processing, transmission, amplifier, etc. Modern power electronics tends to directly serve as the power amplifiers for communication purposes, which provide simplicity and improve the overall system efficiency. Modern transportation tends to be electrified to reduce pollution and better dynamics. The concept of electric vehicles (EVs) is referred to as not only ground automobiles but also any form of transportation in air and water. The propulsion is based on electric motors, drivers, energy storage units, etc. Power electronics is essential for the system coordination, power management, speed regulation, battery charging, and discharging. EVs are also expected to participate in the grid support for future energy network in partnership with power electronics. Aerospace relies on power supplies to operate space shuttles, stations, satellites, etc. Modern aircrafts demand more power electronics to coordinate the power balance among loads, generators, and energy storage units for high efficiency and high power density.
Modern homes are full of various electrical appliances, e.g., microwave ovens, airconditioners, induction cookers, high-efficiency lightings, and residential photovoltaic (PV) power generators. Power electronics plays an important role in supporting the smart operation, high efficiency, reliability, and flexibility. Portable electronic devices are increasingly being used in our daily lives. DC and conversion are required for power supply to computers, cell phones, and tablets.
Future energy networks demand more power conditioning to interface various renewable energy resources such as PV and wind. The HVDC applications have shown significant advantages over HVAC for long-distance transmission. The operation relies on the AC/DC and DC/AC conversion at the HV level. Solid-state transformers at the MV level have become the trend for grid support and make the system more controllable, based on the application of bidirectional power conversion. Further, the utilization of energy storage, e.g., rechargeable batteries, requires power converters for energy management and power regulation.
Recently, DC systems show high potential to replace traditional AC power infrastructure at different voltage levels because of advances in power electronics. The ELVDC and HVDC have become the norms in daily life and long-distance power transmission. More efforts will focus on the applications of LVDC and MVDC in attaining high efficiency, high reliability, flexible interconnection, and low cost.

### 6 Chapte r One

## 1.4 Tools for Development

Hardware equipment and software platforms are required to practice power electronics, which commonly include:

- Software packages for electronic and electrical computer-aided design (ECAD).
- Software platforms for circuit simulation and control system analysis.
- Oscilloscopes with high-bandwidth probes for measuring and recording voltage and current signals.
- Desktop or portable multimeters to detect voltage, current, resistance, and temperature.
- DC and AC programmable power supplies to sufficiently support dynamic speed and power rating.
- Function generators to produce required signals for quick tests.
- Programmable AC and DC loads to emulate variable load profile, meet power rating requirement, and perform disturbed load variation.
- Soldering machines and repair stations for prototyping and practical solution.
- Impedance analyzers or LCR meter to evaluate a circuit network or individual components, e.g., inductor and capacitor, etc.
- Data logger for long-term data acquisition or evaluation of long-term system performance, such as battery charge/discharge cycle and power quality, etc.
- Thermal imager or thermal meter for untouched temperature sensing and thermal assessment.

It is worthwhile to emphasize the importance of thermal analysis in power electronics even though the subject is traditionally related to other disciplines. Regarding power conversion, the temperature is considered an indirect measure of the system efficiency and electrical performance. More and more studies treat the device temperature as the direct indicator of aging and lifespan prediction. Therefore, the thermal imager and meter are important tools for practicing power electronics. The thermal sensing embedded in circuits also becomes the trend to operate a highly reliable and efficient power conversion system.

### 1.4.1 Electrical Computer-Aided Design

One key feature of ECAD software is to develop circuit schematics and printed circuit boards (PCBs). Typical, commercially available ECAD software platforms are as follows:

- EAGLE
- Circuit maker and Altium Designer
- Allegro PCB Designer
- OrCAD PCB Designer

Even though the ECAD software platforms are different from each other, the PCB design generally follows the same step-by-step procedure, as illustrated in Fig. 1.5. Schematic symbol libraries should be first created or loaded from other existing

Background; Circuit schematic capture; Component placement; PCB trace routing; Satisfied?; iterative adjustment; PCB Manufacturing; yes; Technical review and simulation

Load or create libraries of all component symbols in schematics

Load or develop libraries of all component footprints for PCB layout

Match of schematic symbols and pins with PCB footprints

Transform from schematic diagram into PCB design interface

FIGURE 1.5 Schematics showing computer-aided design procedure to manufacture PCB.

resources, including all components that need to be placed in the circuit diagram. The circuit schematic should first be developed for simulation and technical review. The simulation can be performed by the same ECAD software or a completely different platform, such as MATLAB/Simulink.
When the schematic design is approved, the next important step is to select physical components. The selection involves a comprehensive procedure that largely influences the system performance, cost, and reliability. Some PCBs can be directly picked from off-the-shelf products. Many need to be specifically designed and custom-made, e.g., magnetic components of inductors and transformers. The component footprint links the conceptual and representative symbols in the schematic to the practical device mounted on the PCB. It is essential for the library of the component footprints to correspond to/with the symbols and pins in the schematic diagram while representing the real footprints of practical components. The schematic diagram should be updated to include the information of footprints or other physical information resulting from the footprint libraries.
The next step is to transform all the components and connection of the schematic diagram to the PCB design platform, which will appear as the practical footprints in the PCB design interface. The interconnection should strictly follow the design in the schematic diagram. The final step is the PCB layout and routing. The most important step is to place all components in the best location and rotate them for the simplest interconnection. Performing optimal placement and making iterative adjustments are time-consuming, but they are the only ways to minimize the critical and total routing length with full consideration of the thermal constraints as well as system performance. Short traces

### 8 Chapte r One

in PCBs not only improve board density and cost-effectiveness but also show many benefits. The short trace on board leads to low loss, low parasitic inductance, and low electromagnetic inference (EMI), which results in high efficiency, clean signal path, low oscillation, and system robustness. Grounding design is another key factor that should be carefully considered. It provides many benefits of creating one complete layer just for the common ground interconnection. Thermal consideration and ventilation design in PCB are also critical since power converters prefer a “cool” environment for a long-term operation, which links to the reliability and long lifespan.
In general, the PCB design is a time-consuming but critical step in power electronics, which requires a comprehensive review in each step to minimize mistakes and imperfections. Modern power electronics relies on high-frequency power switching and depends on optimally designed PCB to achieve high performance.

### 1.4.2 Simulation

Simulation is an effective tool to prove the concept of theoretical design and circuit analysis. Computer simulation for circuits started with the development of the Simulation Program with Integrated Circuit Emphasis (SPICE) in the 1970s. A group of scholars at the University of California, Berkeley, initialized this significant development in the computer simulation history. Based on the principle of SPICE, the Personal Simulation Program with Integrated Circuit Emphasis (PSPICE) was founded and released by the company MicroSim. The addition of “P” refers to the software operating platform, the personal computer (PC), which became affordable and widely used in the 1980s. Coding was generally required to operate the early version of PSPICE. The latest versions provide graphic-based human–machine interfaces that are easy to learn and use. Following the success of PSPICE, several software packages are commercially available to simulate power electronics. Some of them are listed below:

- PSpice Simulator by Cadence Design Systems Inc. (https://www.cadence.com)
- PSIM by Powersim Inc. (https://powersimtech.com/)
- LTspice by Analog Devices, Inc. (https://www.analog.com)
- PLECS by Plexim GmbH (https://www.plexim.com)
- Simscape Electrical™ package with MATLAB/Simulink by MathWorks (https://www.mathworks.com)

A schematic capture interface is commonly provided by the software packages to develop the circuit-based model. The graphic interface can illustrate the simulation result in terms of time-domain waveforms and frequency-domain analysis. Most components in the library can be integrated with non-ideal factors, such as equivalent series resistors (ESRs), the voltage drop of power semiconductors, and even parasitic parameters. It aims to show the capability for accurate simulation, close to the real-world conditions. Convergence failure is one critical issue for the circuit-based simulation. It has been a common problem for new users to use the early version of PSPICE. The issue generally results from the lack of fundamental knowledge of simulation and power electronic dynamics. The improper setting is another common cause of nonconvergence. Due to the constraints of numerical simulation, some parameters must be included in the model to guarantee convergence. For example, the circuit design can allow a voltage source suddenly applied to a capacitor with a different voltage charge. It causes the convergence issue if the capacitor parameters include zero value of ESR. In theory, the current should

Background 9

jump to an infinite level in response to the step voltage change and lead to nonconvergence in numerical simulation.
There are arguments about the precise simulation including all non-ideal factors. The challenge leads to how the parameters of non-ideal factors can be accurately extracted from a practical system to represent the real-world scenario. Otherwise, this can create a dilemma for learners of power electronics if the problem is not clearly and properly addressed. It is even difficult for experienced engineers to develop accurate models including all non-ideal factors, such as parasitic components in power electronic devices. Even though a component datasheet provides some information about the non-ideal factors, it is simply considered a quick reference since the test is based on a very specific condition. A simple example shows that the ESR value of power semiconductor devices is only valid for one specific operating condition since it changes significantly with the core temperature. The reality faces nonlinear and time-variant factors in a physical system. Circuit parameters mostly becomes unpredictable in real-time operations since they change with the operating conditions, environmentally and electrically. The body temperature or core temperature of a physical device is difficult to be accurately predicted in reality. Therefore, making simulation exactly follow the experimental result requires significant effort and experience, but the accuracy is only guaranteed case by case, not in general.
The author always recommends the start of simulation to be based on all ideal components for quick concept proof without too much complication. The misdefinition of non-ideal factors can only result in more trouble of simulation rather than any precise representation. It has been found that many users simply rely on the random or default values of non-ideal factors to start a circuit-based simulation. It turned out to show more misleading information rather than accuracy and precision. The misleading information is mostly hard to be explained or debugged due to the lack of a deep understanding of simulation fundamentals. Power electronics trusts more on the experimental result rather than on the so-called “accurate simulation,” confronting the complication of nonideality in the real world.
Throughout this book, simulation is only based on ideal components to avoid any mixed and confusing information about non-ideal factors. The discussion focuses on system dynamics to construct the fundamental knowledge of simulation principles. All simulation models shown in this book are based on the fundamental blocks of MATLAB/Simulink, without any complication or dedicated software tools. The approach allows beginners to better understand the simulation fundamentals, utilizing the given functions instead of being inhibited by the constraints on a certain software platform. It also shows the best agreement with the theoretical analysis in terms of steady states and transient responses.

## 1.5 Ideal Power Conversion

Modern power electronics tends to develop converters with the balance of conversion efficiency, lifespan, reliability, cost-effectiveness, power quality, power density, and functionality. The following expectations from power converters lead to continuous improvement and research:

- Stable and robust operation, regardless of disturbance or non-ideal environment.
- Conversion efficiency to be close to 100%.

### 10 Chapte r One

- High power quality appearing at all converter terminals referred to the nominal form of DC or AC.
- Accurate and fast regulation of voltage, current, and power.
- A fast and robust response to reject all sorts of disturbance.
- High power density to forge a small size and efficient operation.
- Low cost without compromising the lifespan.

Efficiency is one of the most important measures of power conversion. The low-efficiency power converters also increase the device size due to significant volume of heat sinks required. Modern power electronic devices are compact, thanks to high-frequency switching and higher efficiency. The efficiency curve is a common illustration for conversion performance according to the variation of the input and/or output characteristics in terms of power, voltage, and current. However, engineers always face the dilemma of maintaining the balance among the performance indices described earlier. As per the current technology, there is a clear trade-off among the factors of affordability, power density, and life expectancy. For example, a long-life capacitor is typically bulkier and more expensive than its short-life counterparts. Thus, a clear and detailed specification should be developed at the beginning of the design stage to find the best balance for the performance indices detailed earlier.

## 1.6 AC and DC

Modern power electronics deals with various forms of voltage and current, which are typically classified as DC, single-phase AC, and three-phase AC. Ideal DC can be plotted as a straight line as the waveform showing nothing but the zero-frequency component. Power electronics produce all different kinds of DC waveforms that can be significantly different from the ideal one. DC follows only one direction, of which the signal waveform does not show zero-crossing. However, the definition does not limit current amplitude as it can vary significantly and periodically from time to time. Thus, the averaged value, peak-to-peak ripple amplitude, and root-mean-square (RMS) value are the important measures for the rating and quality of such DC waveforms, which are covered in Chap. 4.

### 1.6.1 Single-Phase AC

An ideal single-phase AC voltage refers to the sinusoidal waveform showing the constant values in terms of frequency (ω) and amplitude (Vm), which is expressed by vac = Vm sin(ωt). When the voltage is applied to a pure resistive load, R, the current is expressed

by io =

Vm
R

sin(ωt). The instantaneous power is represented by (1.1), where Pm =

V

2
m
R
The averaged value of po can be derived and expressed by (1.2).

po(ωt) = vac(ωt) × io(ωt) = Pm ×

1 − cos(2ωt)
2

(1.1)

AVGpo(ωt)
=

Z π

0

Pm ×

1 − cos(2ωt)
2
d(ωt) = Pm
2

(1.2)

Figure 1.6 shows the waveforms of voltage, current, and power. The power waveform does not show zero-crossing since it follows one direction from the source to the

Background; AVG

FIGURE 1.6 Waveforms of ideal single-phase AC source and load including voltage, current, and power.

RMS; Sine; Square Chopped square

+Vm

−Vm

ωt

0 | π/4 | 3π/4 | 5 π | π/4 | 7π/4 | 9 2π | π/4 | 11π/4 | 13 3π | π/4 | 15π/4

FIGURE 1.7 Illustration of different AC waveforms.

load. The ripple frequency of the power is shown as 2ω, which is the double value of the frequency of vac and io. The power waveform indicates the active power measured in watts. The example illustrates the zero value of the reactive power that is measured in VAR.
AC waveform in power electronics is not limited to the ideal sinusoidal wave, as illustrated in Fig. 1.6. The definition of AC signal indicates a periodic waveform with zero-crossings of its current. Different kinds of AC waveforms are commonly produced by the switching operation of power converters. Figure 1.7 illustrates two common types: square waveform and chopped square waveform. They are plotted with the pure sine waveforms for comparison, and indicate the equality of the power consumption effectiveness when they are applied to the same resistive load. Other AC waveforms also appear in power electronics, such as the triangle waveform.

### 1.6.2 Three-Phase AC

Three-phase electric power is the backbone of AC systems in terms of generation, transmission, and distribution. The three-phase AC is commonly represented by three single-phase AC signals, as shown in Fig. 1.8a. The source and load share a common neutral point, which is the WYE connection or star connection. The line-to-neutral (LN) voltage and phase current are defined and expressed by (1.3) and (1.4), respectively. Ideally, all

### 12 Chapte r One

neutral
(a) (b)
3-phase source | Load in WYE

R

R

R

120°
120°

+

+

+

−

−

−

ia

i v | b an

vbn

vcn

vcn

van

vbn

ic

FIGURE 1.8 Illustration of three-phase source and load in WYE connection: (a) circuit; (b) phasor.

three-phase waveforms indicated in the circuit should be sinusoidal and share the same frequency and the same amplitude.

van = Vm sin(ωt), vbn = Vm sin
ωt −

2π
3

, vcn = Vm sin
ωt −

4π
3
(1.3)
ia = Im sin(ωt), ib = Im sin
ωt −

2π
3

, ic = Im sin
ωt −

4π
3
(1.4)

where Im =

Vm
R

, and the phase difference is 120◦ or

2π
3

among the three-phase voltage waveforms. The instantaneous power of each phase is computed by

pa = van × ia = Pm sin²
(ωt) | (1.5)

pb = vbn × ib = Pm sin²

ωt −

2π
3
| (1.6)

pc = vcn × ic = Pm sin²

ωt −

4π
3
| (1.7)

where Pm = Vm ×Im. The phasor diagram is commonly used to demonstrate three-phase signals, as shown in Fig. 1.8b. The phase voltage, current, and power are plotted in time domain and shown in Fig. 1.9. The phase lag of the LN voltage waveforms is measured as

2π
3

among the phases A, B, and C.

One important feature of the three-phase power systems is that the sum of the instantaneous power values of pa, pb
, and pc is a straight line, as shown in Fig. 1.10, when the balance of three phases is presented and the power factor is unity. The feature is important for the conversion between DC and three-phase AC. The sum of the three-phase AC power is expressed by
X(pa, pb
, pc) = 1.5Pm | (1.8)

Another configuration of three-phase power systems is the ∆ connection, as shown in Fig. 1.11a. The line-to-line (LL) voltages become the direct measurements, which are across the load resistors and symbolized by vab, vbc, and vca. The phasor diagram can

Background; van; vbn; vcn

FIGURE 1.9 Illustration of ideal three-phase waveforms.


FIGURE 1.10 Illustration of ideal three-phase waveforms in term of power.

demonstrate the connection between the LN and LL voltages, as illustrated in Fig. 1.11b. Mathematically, they are expressed by

vab = van − vbn =

√

3Vm sin
ωt +

π
6
(1.9)

vbc = vbn − vcn =

√

3Vm sin
ωt −

π
2
(1.10)

vca = vcn − van =

√

3Vm sin
ωt −

7π
6
(1.11)

where the voltage van = Vm sin(ωt)is the reference signal to mathematically present other LN and LL voltage waveforms. The LL and LN voltages show the amplitude difference of √
3. It is shown that the phase of vab leads van by 30◦ or

π
6

, the phase of vbc leads vbn by 30◦

, and the phase of vca leads vcn by 30◦ . The LL voltage waveforms also show the phase difference of 2π
3

among the three phases.

### 14 Chapte r One

3-phase
source

neutral

Load
in delta connection

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
− | +

−

vcn

vbn

van

vab

−v
v | an ca

vbn

−vcn
vbc

van

−vbn

vab

vcn

30°

120°

vca

ia

ib

ic

vbc

(a) (b)

FIGURE 1.11 Illustration of three-phase source and load in delta connection: (a) circuit; (b) phasor.

(a) | (b) | (c)

FIGURE 1.12 Galvanic isolation by (a) magnetics; (b) light; (c) capacitor.
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

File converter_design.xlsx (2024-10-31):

FULL BRIDGE CONVERTER DESIGN
INPUT PARAMETERS |  |  |  |  |  | OUTPUT DISPLAY
Input Voltage | Vin | 12 | v |  |  | Input Current | Iin | 83.33333333 | A
Output Voltage | Vo | 300 | v |  |  | Output Current | Io | 3.333333333 | A
Power | P | 1000 | w |  |  | Number of 10 turns | N1 | 0.8898454409 |  | 1
Duty Cycle | D | 0.5 |  |  |  | Number of 20 turns | N2 | 44.49227205 |  | 50
Switching frequency | Fs | 30000 | Hz |  |  | turn's ratio | n | 50
Diode Voltage drop | Vd | 2 | v |  |  | Area product(calcltd) | Ap | 54004.09647 | mm4
Current ripple ratio | CR | 0.4 |  |  |  | Inductance | I | 1160.714286 | H | 73 TURNS OF 17 SWG
Waveform factor | Kf | 5.656854249 |  |  |  | Capacitance | C
Core Type |  | EE5221
Copper Area (EE5521) | Ac | 361.2 | mm2
Window Area (EE5521) | Aw | 375.55 | mm2
Area Product (EE5521) | Ap | 135648.66 | mm4
Current Density | J | 3e-06 | A/M2
Magnetic flux density | Bm | 0.22 | T
Area factor | Ku | 0.4
 |  |  |  | V1 | 12
 |  |  |  | V2 | 600
 |  |  |  | %Io | 1
 |  |  |  | Io max | 3.833333333
 |  |  |  | Io min = | 2.833333333
 |  |  |  | Io rms = | 2.365844928
 |  |  |  | %IL | 1.333333333
 |  |  |  | ripl max | 4.666666667
 |  |  |  | rppl min | 2
 |  |  |  | del IL | 2.666666667
2024-07-25
design for 100 w converter for testing
primari inductance
primary resistance | 0.4
secondary inductance
seondary resistnce | 1.6
Losses Calculation | rds ON(mOHM)
80nf10 | 15
STB200nf03 | 0.0036 @ 10v

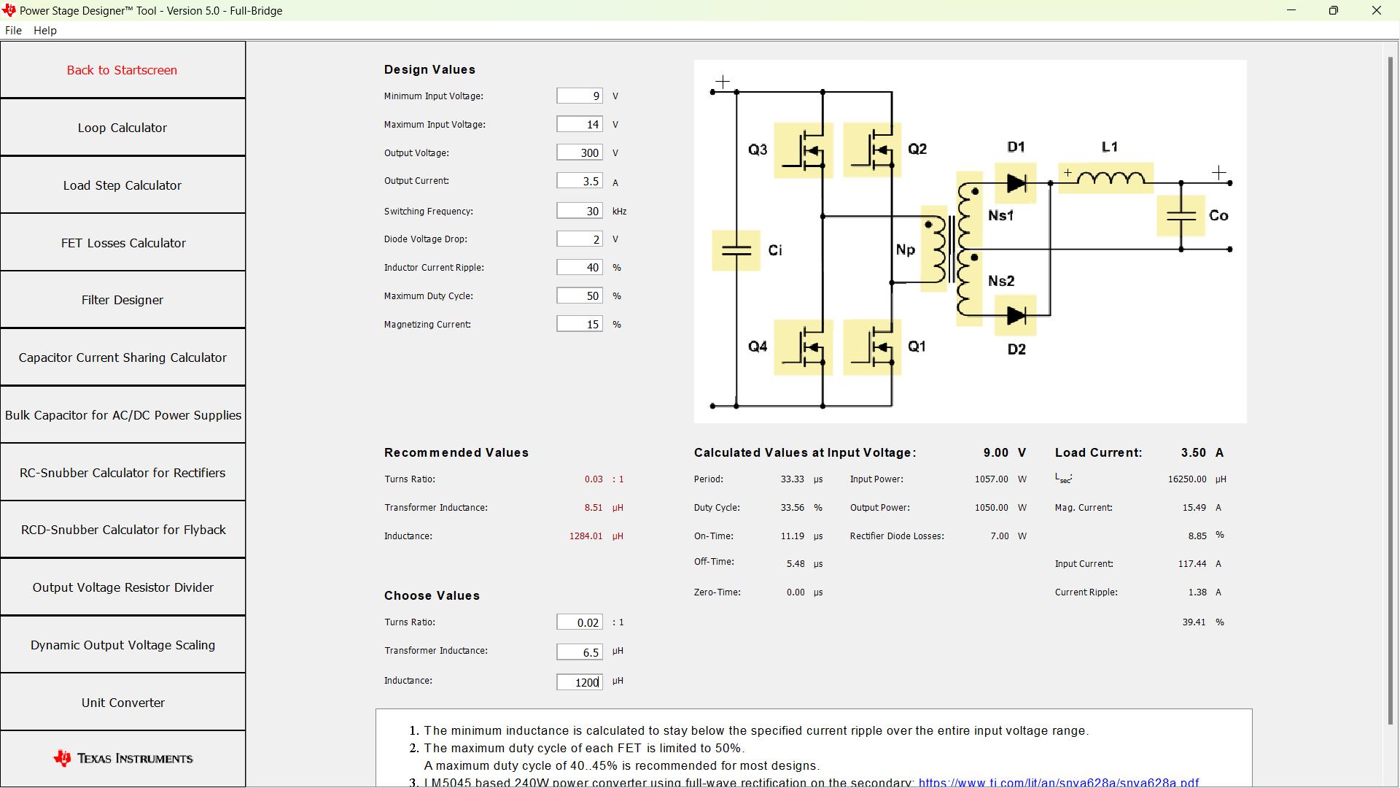
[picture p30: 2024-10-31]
Screenshot (3).png

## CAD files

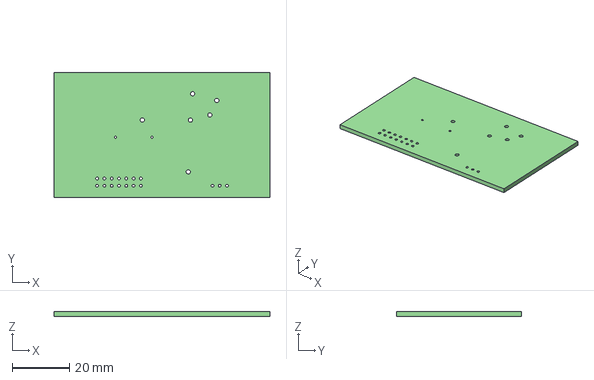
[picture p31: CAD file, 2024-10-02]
Gate Driver TLP152 V1.1/Gate Driver TLP152.step
75.2 x 43.4 x 1.60 mm

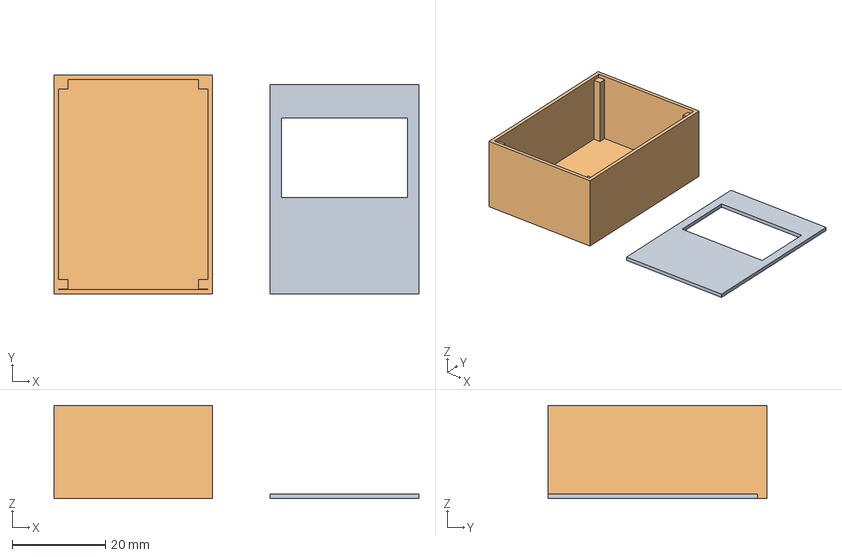
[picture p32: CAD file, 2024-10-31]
w5500/sketch_sep17b/ssd1306-1.8.5/ssd1306-1.8.5/examples/games/arkanoid/schematics/case.3mf
78.3 x 47.0 x 20.0 mm

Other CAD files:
pwm_ert_rtw/ert_main.obj
PWM/pwm_ert_rtw/ert_main.obj
matlab files/pwm_ert_rtw/ert_main.obj
matlab files/pwm_ert_rtw/F2837xD_PieCtrl.obj
PWM/pwm_ert_rtw/F2837xD_usDelay.obj
matlab files/pwm_ert_rtw/MW_c28xGlobalInterrupts.obj
PWM/pwm_ert_rtw/F2837xD_PieVect.obj
pwm_ert_rtw/F2837xD_PieVect.obj
matlab files/pwm_ert_rtw/MW_c28xx_pwm.obj
PWM/pwm_ert_rtw/sysctl.obj
pwm_ert_rtw/sysctl.obj
matlab files/pwm_ert_rtw/F2837xD_Adc.obj
PWM/pwm_ert_rtw/memcpy_fast.obj
pwm_ert_rtw/F2837xD_Ipc_Driver_Lite.obj
matlab files/pwm_ert_rtw/F2837xD_CpuTimers.obj
PWM/pwm_ert_rtw/MW_c28xx_adc.obj
PWM/pwm_ert_rtw/F2837xD_Adc.obj
PWM/pwm_ert_rtw/F2837xD_CodeStartBranch.obj
PWM/pwm_ert_rtw/F2837xD_CpuTimers.obj
PWM/pwm_ert_rtw/F2837xD_DefaultISR.obj
PWM/pwm_ert_rtw/F2837xD_Dma.obj
PWM/pwm_ert_rtw/F2837xD_GlobalVariableDefs.obj
PWM/pwm_ert_rtw/F2837xD_Gpio.obj
PWM/pwm_ert_rtw/F2837xD_Ipc_Driver_Lite.obj
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

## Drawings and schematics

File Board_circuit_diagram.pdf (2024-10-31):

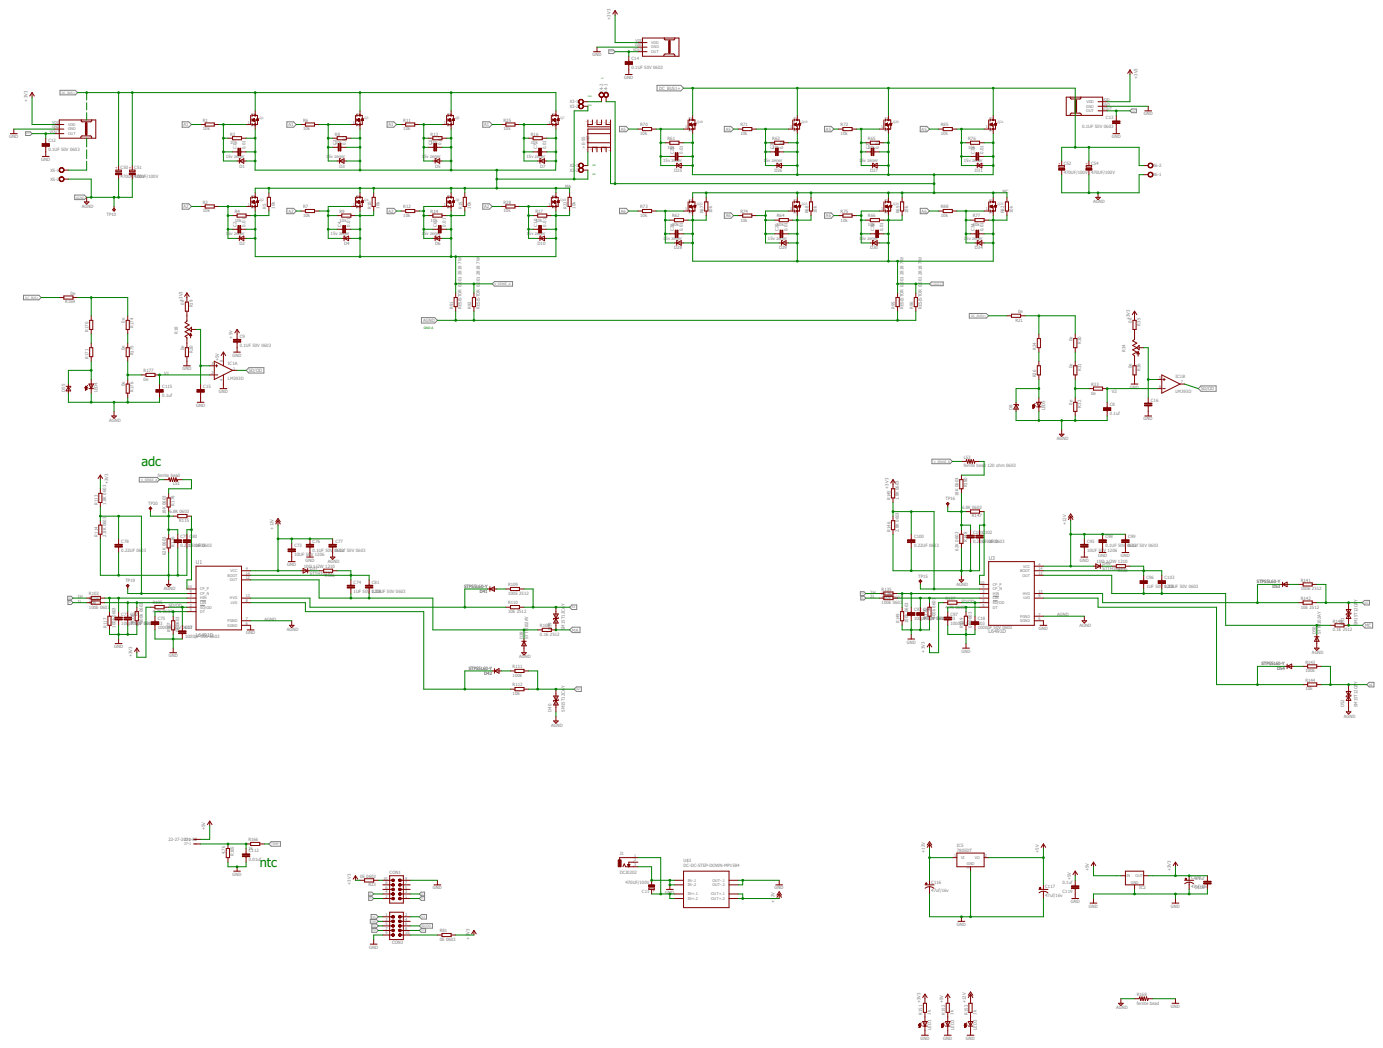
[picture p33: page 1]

DC-DC-STEP-DOWN-MP1584

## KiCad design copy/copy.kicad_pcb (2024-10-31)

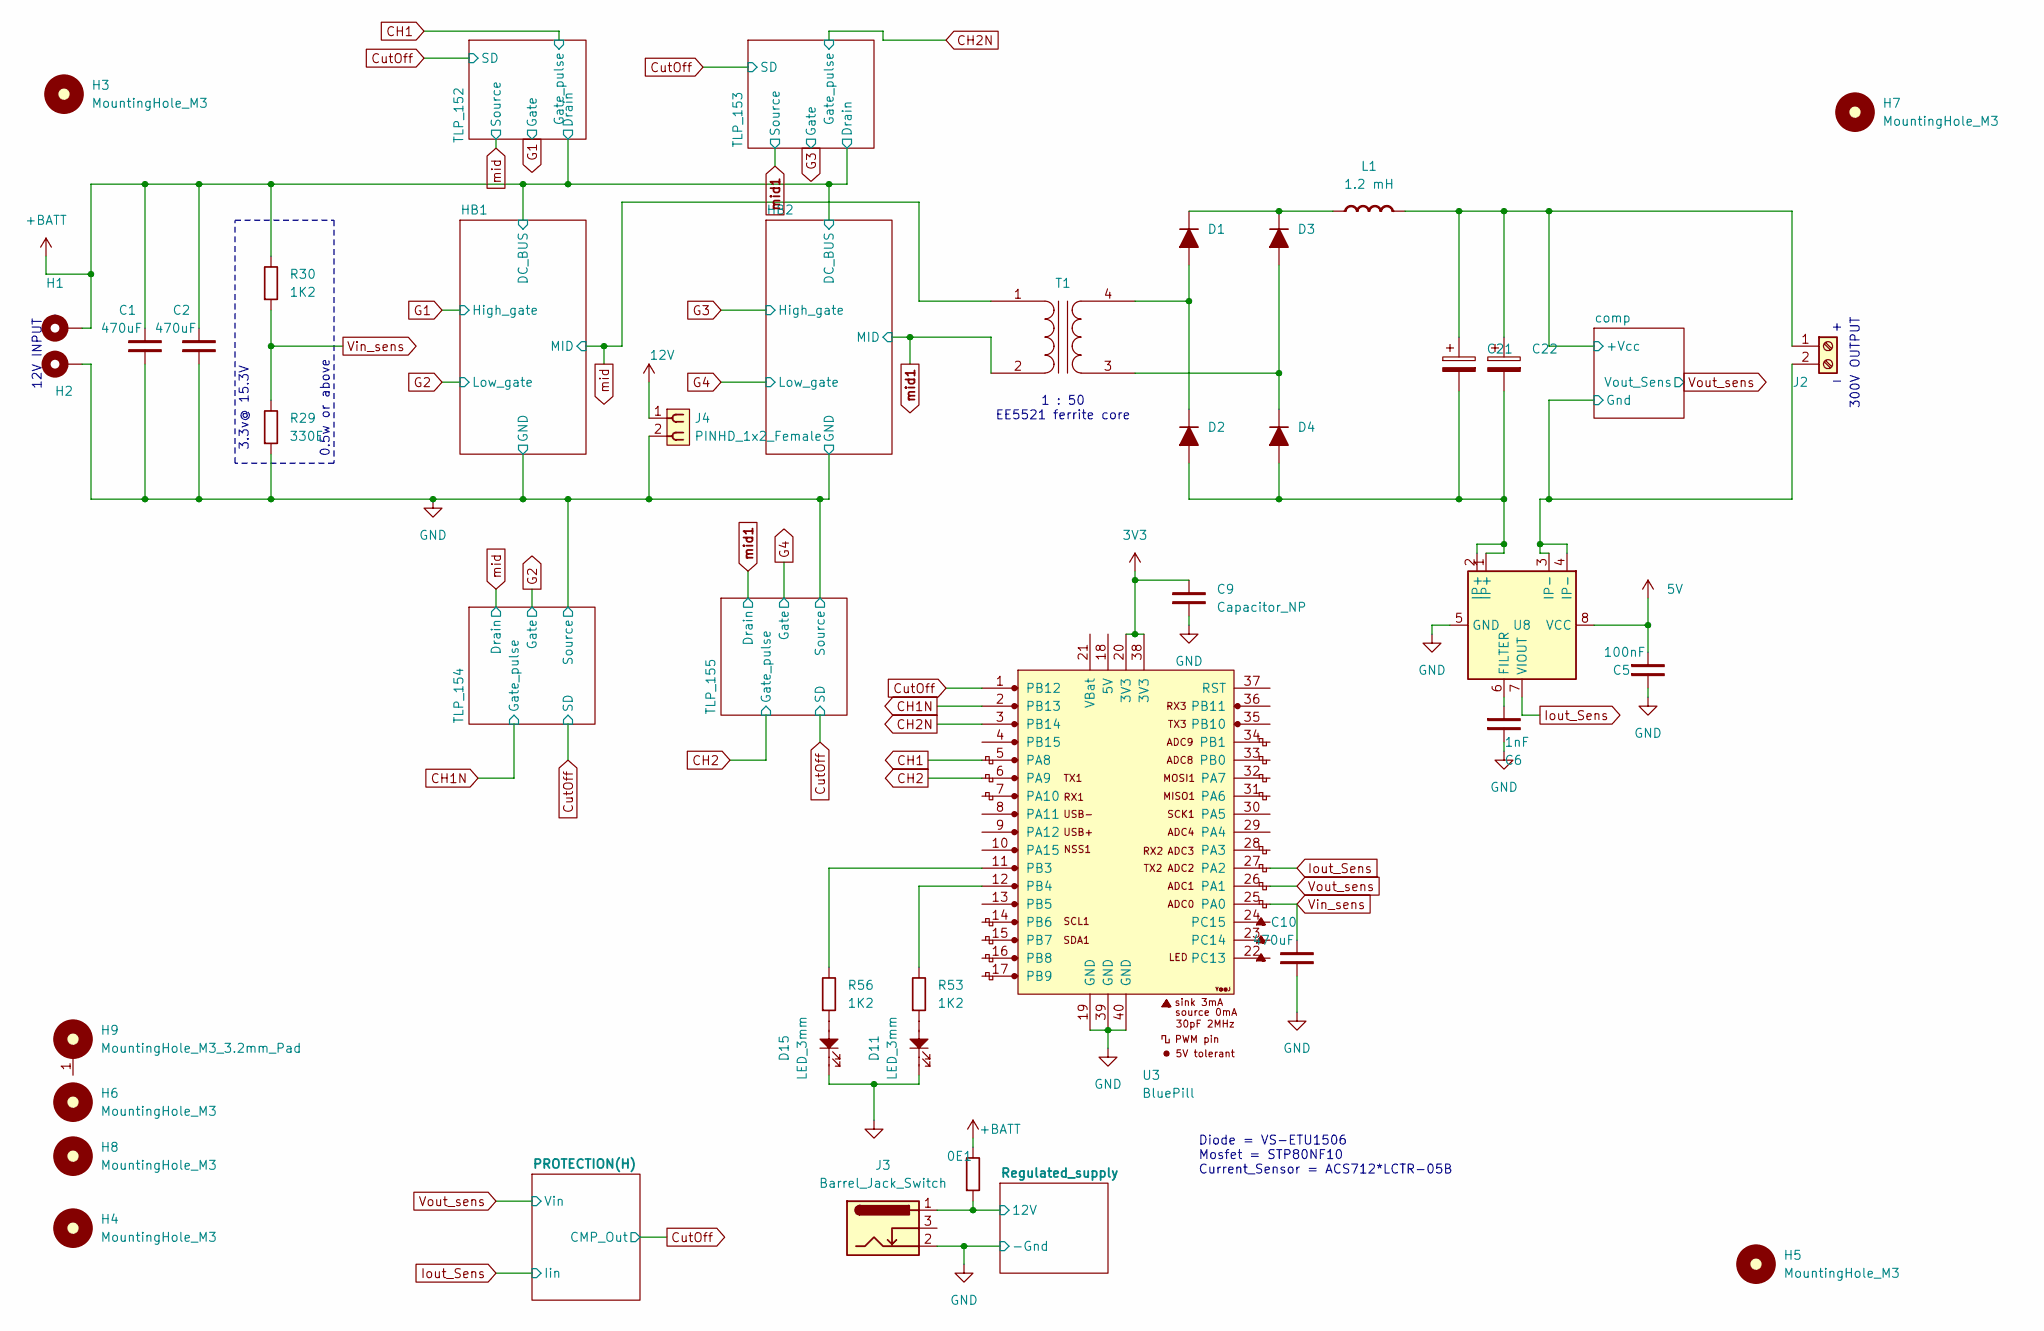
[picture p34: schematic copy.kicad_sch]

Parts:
0E1: Resistor; R_Axial_DIN0207_L6.3mm_D2.5mm_P10.16mm_Horizontal
C1, C2: 470uF; CP_Radial_D12.5mm_P5.00mm
C5: 100nF; C_Disc_D4.7mm_W2.5mm_P5.00mm
C6: 1nF; C_0805_2012Metric_Pad1.18x1.45mm_HandSolder
C9: Capacitor_NP; C_Disc_D3.0mm_W2.0mm_P2.50mm
C10: 470uF; C_0805_2012Metric_Pad1.18x1.45mm_HandSolder
C21, C22: CP_Generic; CP_Radial_D35.0mm_P10.00mm_SnapIn
D1, D2, D3, D4: VS-ETU1506; TO-220-2_Vertical
D11, D15: LED_3mm; LED_D3.0mm
H1, H2: M5_bolt_terminal; bolt_terminal_15x14.5mm
H3, H4, H5, H6, H7, H8: MountingHole_M3; MountingHole_3.2mm_M3
H9: MountingHole_M3_3.2mm_Pad; MountingHole_3.2mm_Pad
J2: 01x02; TerminalBlock_bornier-2_P5.08mm
J3: Barrel_Jack_Switch; BarrelJack_Horizontal
J4: PINHD_1x2_Female; 2pin_RMC
L1: 1.2 mH; EE 55; Rating A
R29: 330E; R_0805_2012Metric_Pad1.20x1.40mm_HandSolder
R30: 1K2; R_Axial_DIN0207_L6.3mm_D2.5mm_P10.16mm_Horizontal
R53, R56: 1K2; R_0805_2012Metric_Pad1.20x1.40mm_HandSolder
T1: Transformer_1P_1S; EE 55
U3: BluePill
U8: ACS712xLCTR-05B; SOIC-8_3.9x4.9mm_P1.27mm

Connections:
3V3: C9.2, U3.20 (3V3), U3.38 (3V3); also elsewhere on the board
5V: C5.1, U8.8 (VCC); also elsewhere on the board
12V: 0E1.1, J3.1, J4.1; also elsewhere on the board
+BATT: 0E1.2, C1.2, C2.2, H1.1, R30.2; also elsewhere on the board
/comp/+Vcc: C21.1, C22.1, J2.1, L1.2 (-); also elsewhere on the board
/comp/Gnd: J2.2, U8.3 (IP-), U8.4 (IP-); also elsewhere on the board
CH1: U3.5 (PA8); also elsewhere on the board
CH1N: U3.2 (PB13); also elsewhere on the board
CH2: U3.6 (PA9); also elsewhere on the board
CH2N: U3.3 (PB14); also elsewhere on the board
CutOff: U3.1 (PB12); also elsewhere on the board
GND: C1.1, C2.1, C5.2, C6.2, C9.1, C10.1, D11.1, D15.1, H2.1, J3.2, J4.2, R29.1, U3.19 (GND), U3.39 (GND), U3.40 (GND), U8.5 (GND); also elsewhere on the board
Iout_Sens: U3.27 (PA2), U8.7 (VIOUT); also elsewhere on the board
unnamed: D1.2 (A), D2.1 (K), T1.4 (SB)
unnamed: D1.1 (K), D3.1 (K), L1.1 (+)
unnamed: C21.2, C22.2, D2.2 (A), D4.2 (A), U8.1 (IP+), U8.2 (IP+)
unnamed: D3.2 (A), D4.1 (K), T1.3 (SA)
unnamed: D11.2, R53.1
unnamed: D15.2, R56.1
unnamed: R56.2, U3.11 (PB3)
unnamed: R53.2, U3.12 (PB4)
unnamed: C6.1, U8.6 (FILTER)
Vin_sens: C10.2, R29.2, R30.1, U3.25 (PA0)
Vout_sens: U3.26 (PA1); also elsewhere on the board
mid: T1.1 (AA); also elsewhere on the board
mid1: T1.2 (AB); also elsewhere on the board

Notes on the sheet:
12V INPUT
3.3v@ 15.3V
Diode = VS-ETU1506 Mosfet = STP80NF10 Current_Sensor = ACS712*LCTR-05B
0.5w or above
300V OUTPUT
1 : 50 EE5521 ferrite core

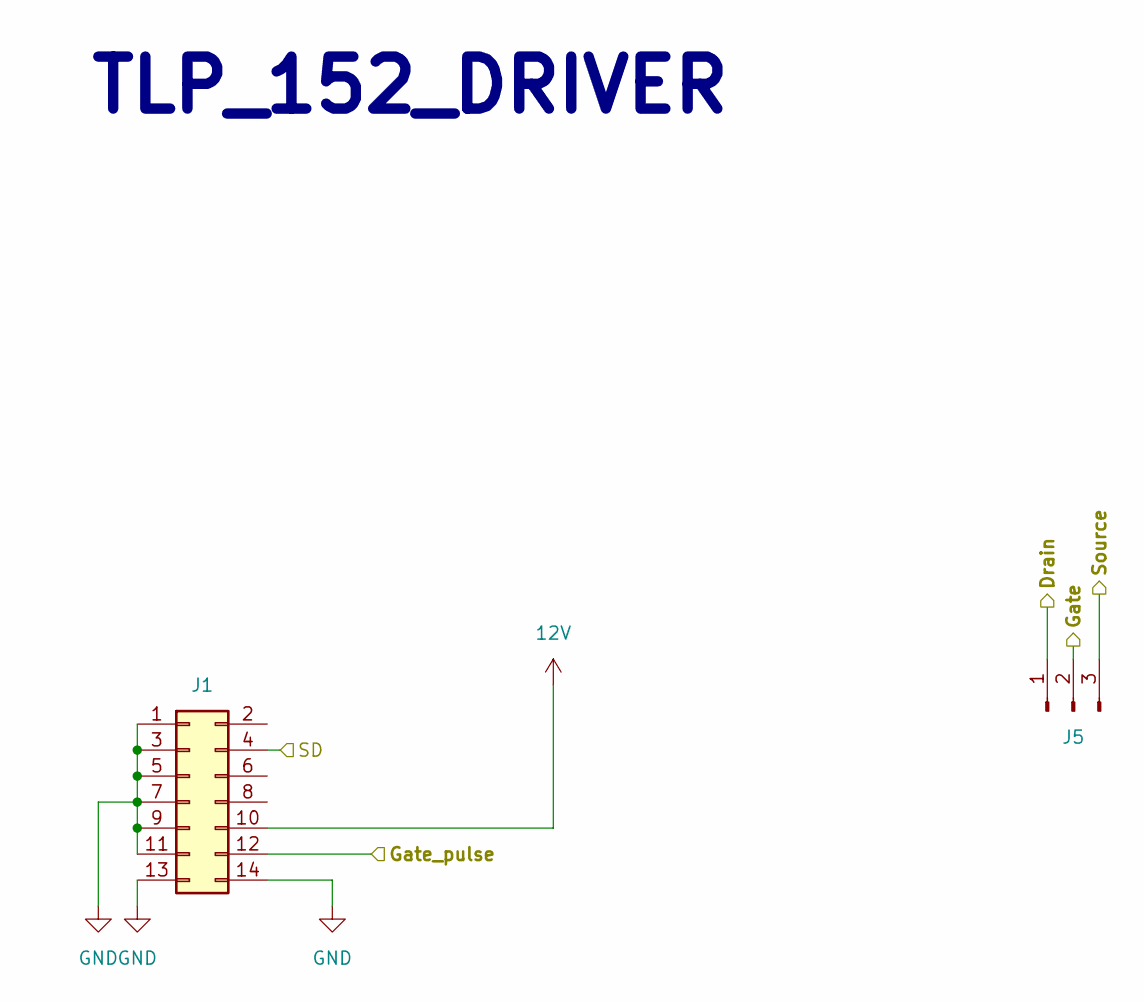
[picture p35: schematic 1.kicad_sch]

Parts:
J1: Conn_02x07_Row_Letter_Last; PinHeader_2x07_P2.54mm_Vertical
J5: Conn_01x03_Pin; PinHeader_1x03_P2.54mm_Horizontal

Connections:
12V: J1.10 (Pin_5b); also elsewhere on the board
+BATT: J5.1; also elsewhere on the board
CH2N: J1.12 (Pin_6b); also elsewhere on the board
CutOff: J1.4 (Pin_2b); also elsewhere on the board
G3: J5.2; also elsewhere on the board
GND: J1.1, J1.3 (Pin_2a), J1.5 (Pin_3a), J1.7 (Pin_4a), J1.9 (Pin_5a), J1.11 (Pin_6a), J1.13 (Pin_7a), J1.14 (Pin_7b); also elsewhere on the board
mid1: J5.3; also elsewhere on the board

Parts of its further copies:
J6, J8, J10: Conn_02x07_Row_Letter_Last; PinHeader_2x07_P2.54mm_Vertical
J7, J9, J11: Conn_01x03_Pin; PinHeader_1x03_P2.54mm_Horizontal

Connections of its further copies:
12V: J6.10 (Pin_5b), J8.10 (Pin_5b), J10.10 (Pin_5b); also elsewhere on the board
+BATT: J9.1; also elsewhere on the board
CH1: J8.12 (Pin_6b); also elsewhere on the board
CH1N: J6.12 (Pin_6b); also elsewhere on the board
CH2: J10.12 (Pin_6b); also elsewhere on the board
CutOff: J6.4 (Pin_2b), J8.4 (Pin_2b), J10.4 (Pin_2b); also elsewhere on the board
G1: J9.2; also elsewhere on the board
G2: J7.2; also elsewhere on the board
G4: J11.2; also elsewhere on the board
GND: J6.1, J6.3 (Pin_2a), J6.5 (Pin_3a), J6.7 (Pin_4a), J6.9 (Pin_5a), J6.11 (Pin_6a), J6.13 (Pin_7a), J6.14 (Pin_7b), J7.3, J8.1, J8.3 (Pin_2a), J8.5 (Pin_3a), J8.7 (Pin_4a), J8.9 (Pin_5a), J8.11 (Pin_6a), J8.13 (Pin_7a), J8.14 (Pin_7b), J10.1, J10.3 (Pin_2a), J10.5 (Pin_3a), J10.7 (Pin_4a), J10.9 (Pin_5a), J10.11 (Pin_6a), J10.13 (Pin_7a), J10.14 (Pin_7b), J11.3; also elsewhere on the board
mid: J7.1, J9.3; also elsewhere on the board
mid1: J11.1; also elsewhere on the board

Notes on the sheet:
TLP_152_DRIVER

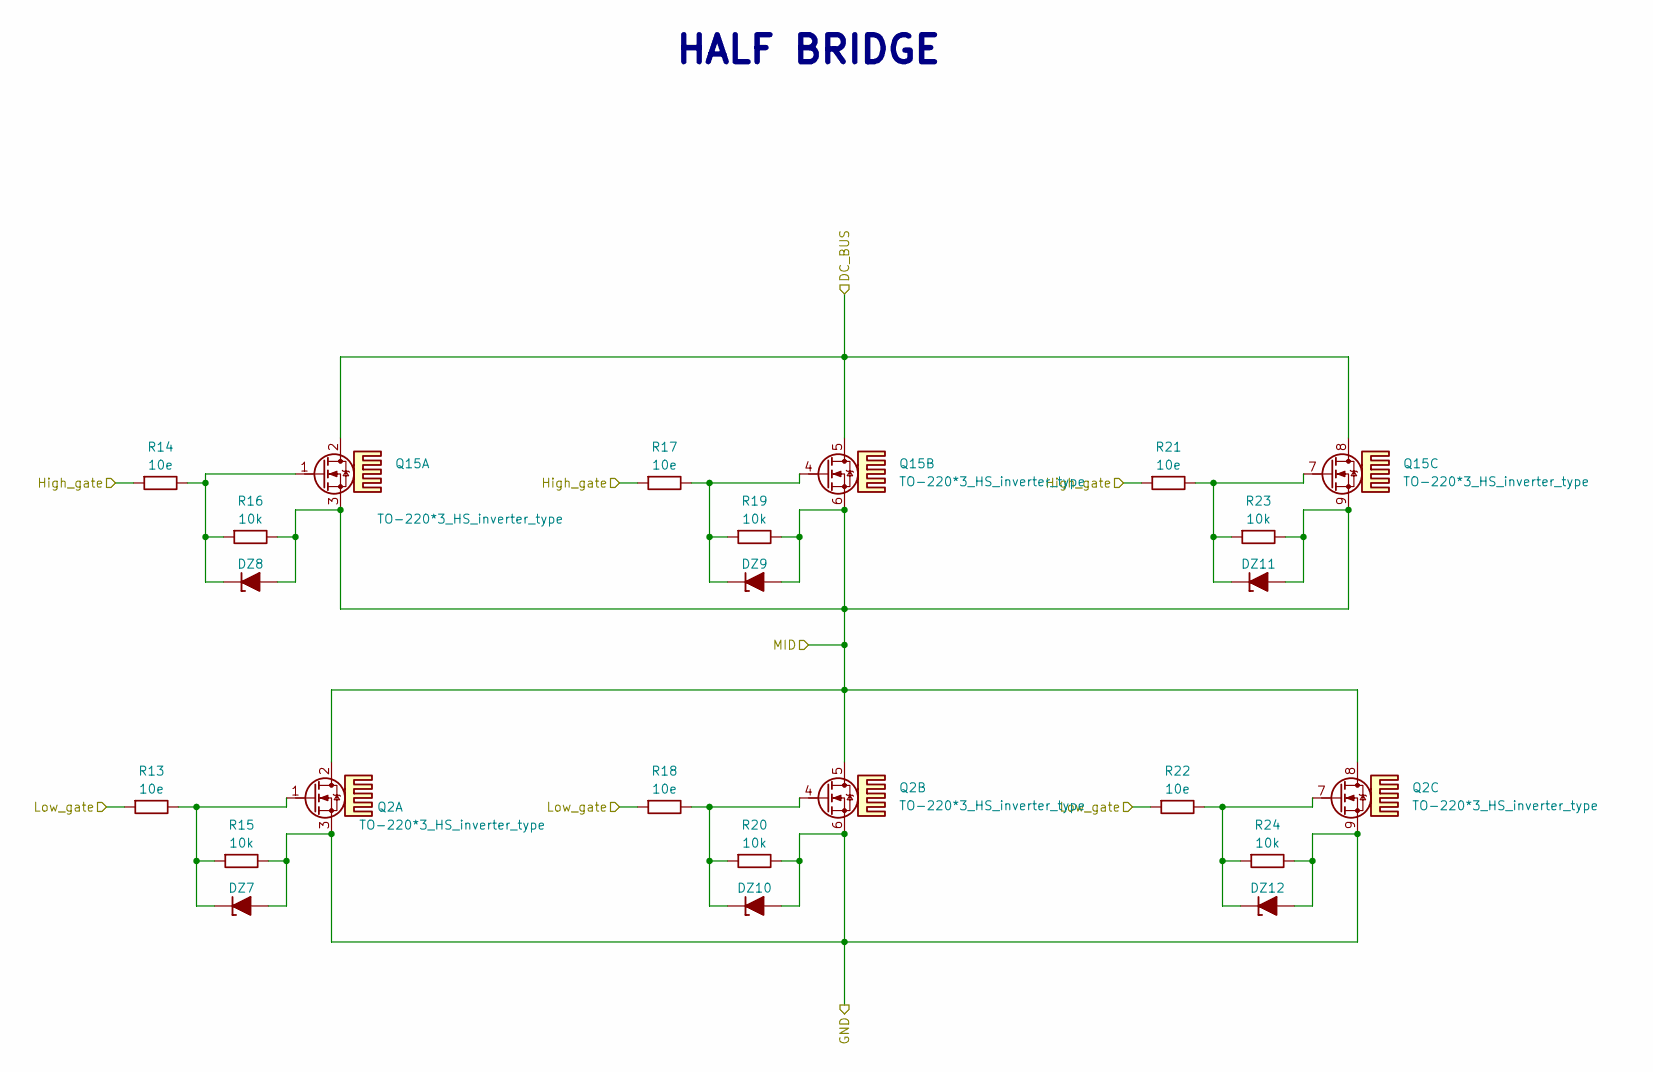
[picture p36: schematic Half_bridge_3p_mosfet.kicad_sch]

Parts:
DZ7, DZ8, DZ9, DZ10, DZ11, DZ12: D_Zener_Generic; D_MiniMELF
Q2, Q15: TO-220*3_HS_inverter_type; 3 FET heatsink inverter type
R13, R14, R17, R18, R21: 10e; R_0805_2012Metric_Pad1.20x1.40mm_HandSolder
R15, R16, R19, R20, R23, R24: 10k; R_0805_2012Metric_Pad1.20x1.40mm_HandSolder
R22: 10e; R_Axial_DIN0207_L6.3mm_D2.5mm_P10.16mm_Horizontal

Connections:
+BATT: Q15.2, Q15.5, Q15.8; also elsewhere on the board
G3: R14.1, R17.1, R21.1; also elsewhere on the board
G4: R13.1, R18.1, R22.1; also elsewhere on the board
GND: DZ7.2 (A), DZ10.2 (A), DZ12.2 (A), Q2.3, Q2.6, Q2.9, R15.2, R20.2, R24.2; also elsewhere on the board
unnamed: DZ7.1 (K), Q2.1, R13.2, R15.1
unnamed: DZ8.1 (K), Q15.1, R14.2, R16.1
unnamed: DZ9.1 (K), Q15.4, R17.2, R19.1
unnamed: DZ10.1 (K), Q2.4, R18.2, R20.1
unnamed: DZ11.1 (K), Q15.7, R21.2, R23.1
unnamed: DZ12.1 (K), Q2.7, R22.2, R24.1
mid1: DZ8.2 (A), DZ9.2 (A), DZ11.2 (A), Q2.2, Q2.5, Q2.8, Q15.3, Q15.6, Q15.9, R16.2, R19.2, R23.2; also elsewhere on the board

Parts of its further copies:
DZ1, DZ2, DZ3, DZ4, DZ5, DZ6: D_Zener_Generic; D_MiniMELF
Q1, Q14: TO-220*3_HS_inverter_type; 3 FET heatsink inverter type
R1, R3, R5, R7, R9: 10e; R_0805_2012Metric_Pad1.20x1.40mm_HandSolder
R2, R4, R6, R8, R10, R12: 10k; R_0805_2012Metric_Pad1.20x1.40mm_HandSolder
R11: 10e; R_Axial_DIN0207_L6.3mm_D2.5mm_P10.16mm_Horizontal

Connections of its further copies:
+BATT: Q14.2, Q14.5, Q14.8; also elsewhere on the board
G1: R1.1, R3.1, R5.1; also elsewhere on the board
G2: R7.1, R9.1, R11.1; also elsewhere on the board
GND: DZ4.2 (A), DZ5.2 (A), DZ6.2 (A), Q1.3, Q1.6, Q1.9, R8.2, R10.2, R12.2; also elsewhere on the board
unnamed: DZ1.1 (K), Q14.1, R1.2, R2.1
unnamed: DZ2.1 (K), Q14.4, R3.2, R4.1
unnamed: DZ3.1 (K), Q14.7, R5.2, R6.1
unnamed: DZ4.1 (K), Q1.1, R7.2, R8.1
unnamed: DZ5.1 (K), Q1.4, R9.2, R10.1
unnamed: DZ6.1 (K), Q1.7, R11.2, R12.1
mid: DZ1.2 (A), DZ2.2 (A), DZ3.2 (A), Q1.2, Q1.5, Q1.8, Q14.3, Q14.6, Q14.9, R2.2, R4.2, R6.2; also elsewhere on the board

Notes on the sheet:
HALF BRIDGE

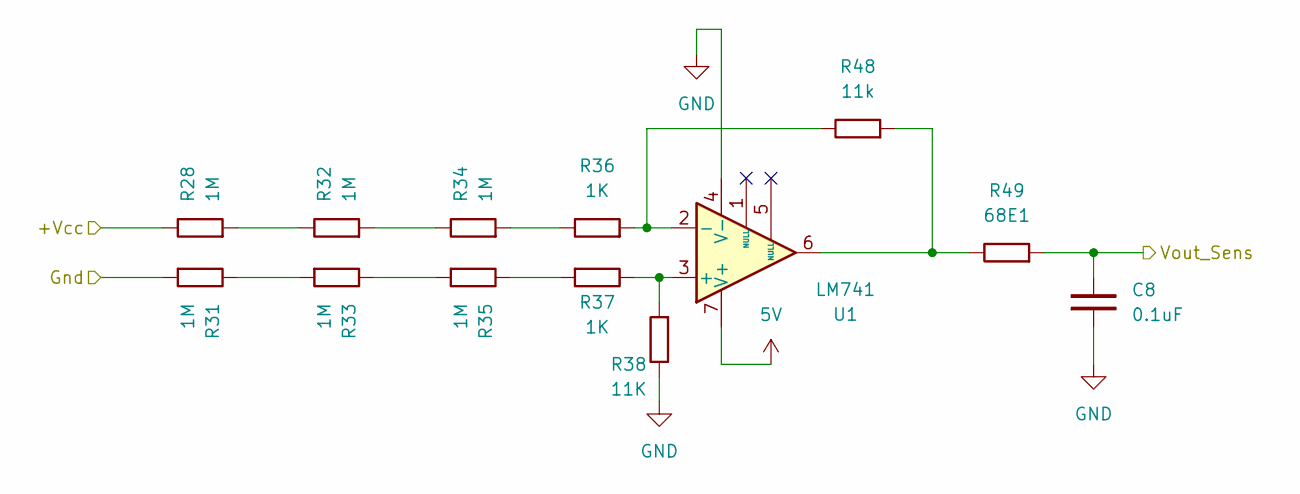
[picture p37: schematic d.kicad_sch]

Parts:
C8: 0.1uF; C_Disc_D3.0mm_W2.0mm_P2.50mm
R28, R32, R33, R34, R35: 1M; R_0805_2012Metric_Pad1.20x1.40mm_HandSolder
R31: 1M; R_Axial_DIN0207_L6.3mm_D2.5mm_P10.16mm_Horizontal
R36: 1K; R_Axial_DIN0207_L6.3mm_D2.5mm_P10.16mm_Horizontal
R37: 1K; R_0805_2012Metric_Pad1.20x1.40mm_HandSolder
R38: 11K; R_0805_2012Metric_Pad1.20x1.40mm_HandSolder
R48: 11k; R_0805_2012Metric_Pad1.20x1.40mm_HandSolder
R49: 68E1; R_Axial_DIN0207_L6.3mm_D2.5mm_P10.16mm_Horizontal
U1: LM741; DIP-8_W7.62mm

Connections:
5V: U1.7 (V+); also elsewhere on the board
/comp/+Vcc: R28.2; also elsewhere on the board
/comp/Gnd: R31.1; also elsewhere on the board
GND: C8.1, R38.2, U1.4 (V-); also elsewhere on the board
unnamed: R28.1, R32.2
unnamed: R31.2, R33.1
unnamed: R32.1, R34.2
unnamed: R33.2, R35.1
unnamed: R34.1, R36.2
unnamed: R35.2, R37.1
unnamed: R48.1, R49.2, U1.6
unnamed: R37.2, R38.1, U1.3 (+)
unnamed: R36.1, R48.2, U1.2 (-)
Vout_sens: C8.2, R49.1; also elsewhere on the board

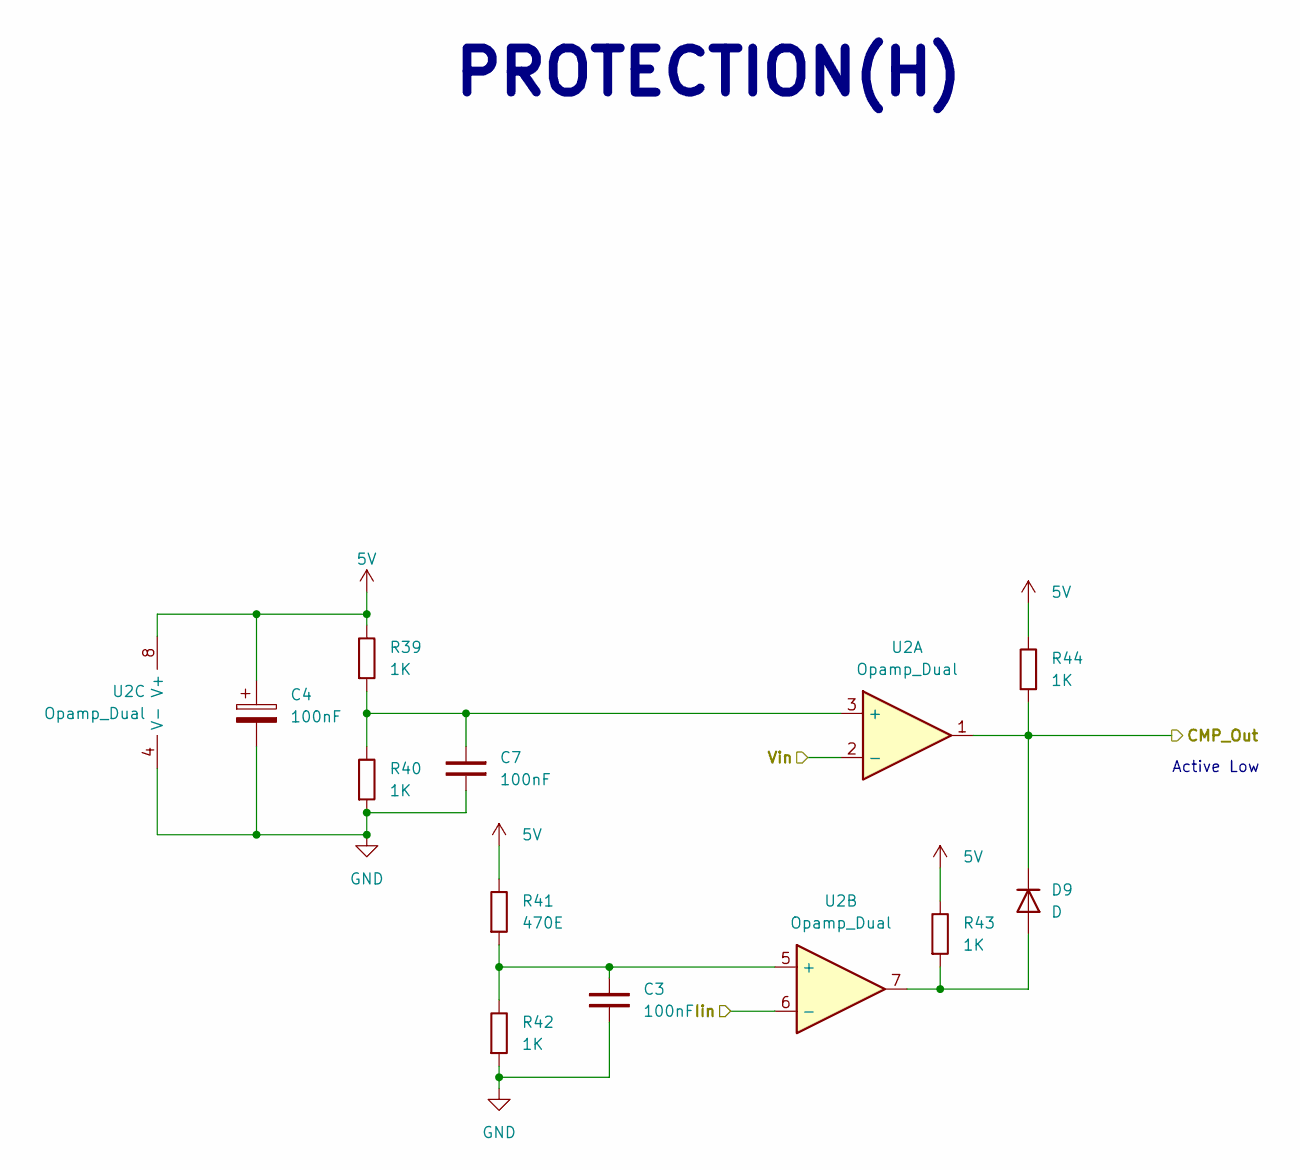
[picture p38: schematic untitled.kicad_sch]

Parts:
C3, C4, C7: 100nF; C_0805_2012Metric_Pad1.18x1.45mm_HandSolder
D9: D; D_A-405_P7.62mm_Horizontal
R39, R40, R43, R44: 1K; R_0805_2012Metric_Pad1.20x1.40mm_HandSolder
R41: 470E; R_0805_2012Metric_Pad1.20x1.40mm_HandSolder
R42: 1K; R_Axial_DIN0207_L6.3mm_D2.5mm_P10.16mm_Horizontal
U2: Opamp_Dual; DIP-8_W7.62mm

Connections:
5V: C4.1, R39.2, R41.2, R43.2, R44.2, U2.8 (V+); also elsewhere on the board
CutOff: D9.1 (K), R44.1, U2.1; also elsewhere on the board
GND: C3.1, C4.2, C7.2, R40.1, R42.1, U2.4 (V-); also elsewhere on the board
Iout_Sens: U2.6 (-); also elsewhere on the board
unnamed: D9.2 (A), R43.1, U2.7
unnamed: C7.1, R39.1, R40.2, U2.3 (+)
unnamed: C3.2, R41.1, R42.2, U2.5 (+)
Vout_sens: U2.2 (-); also elsewhere on the board

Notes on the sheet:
Active Low
PROTECTION(H)

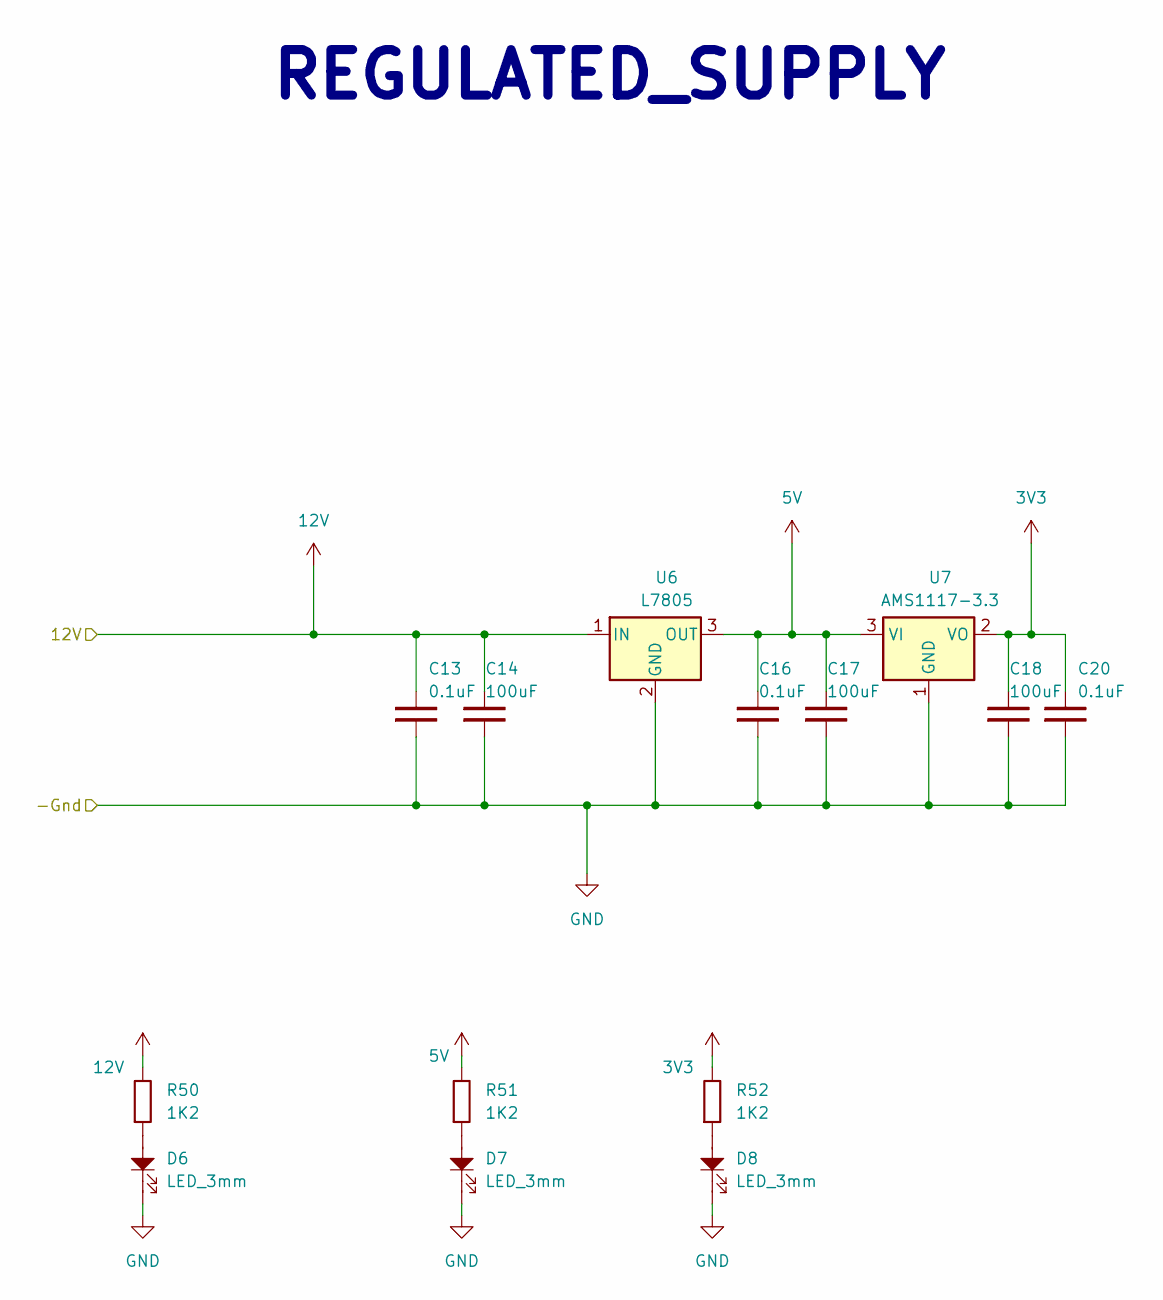
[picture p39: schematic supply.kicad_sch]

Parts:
C13: 0.1uF; C_0805_2012Metric_Pad1.18x1.45mm_HandSolder
C14, C17: 100uF; CP_Radial_D5.0mm_P2.50mm
C16: 0.1uF; C_Disc_D3.0mm_W2.0mm_P2.50mm
C18: 100uF; C_0805_2012Metric_Pad1.18x1.45mm_HandSolder
C20: 0.1uF; CP_Radial_D5.0mm_P2.50mm
D6, D7, D8: LED_3mm; LED_D3.0mm
R50, R51, R52: 1K2; R_0805_2012Metric_Pad1.20x1.40mm_HandSolder
U6: L7805; TO-220-3_Vertical_HS48_PL48_Heatsink
U7: AMS1117-3.3; SOT-223-3_TabPin2

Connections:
3V3: C18.2, C20.2, R52.2, U7.2 (VO); also elsewhere on the board
5V: C16.2, C17.2, R51.2, U6.3 (OUT), U7.3 (VI); also elsewhere on the board
12V: C13.2, C14.2, R50.2, U6.1 (IN); also elsewhere on the board
GND: C13.1, C14.1, C16.1, C17.1, C18.1, C20.1, D6.1, D7.1, D8.1, U6.2 (GND), U7.1 (GND); also elsewhere on the board
unnamed: D6.2, R50.1
unnamed: D7.2, R51.1
unnamed: D8.2, R52.1

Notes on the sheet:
REGULATED_SUPPLY

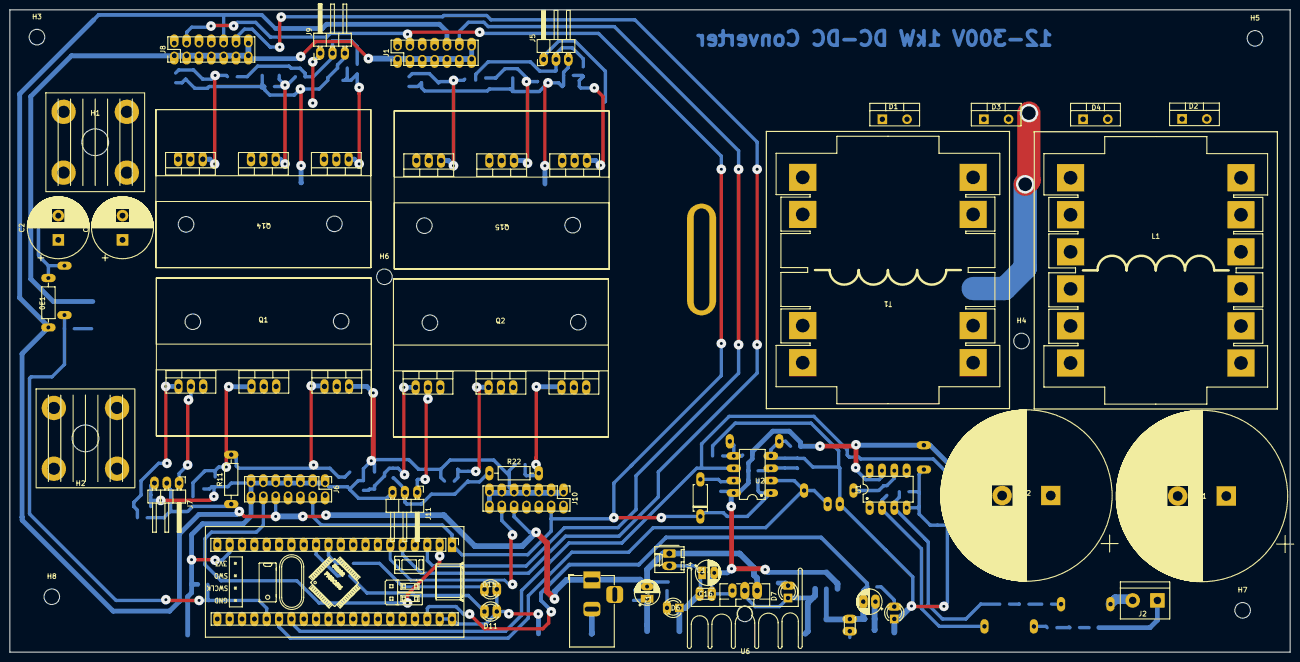
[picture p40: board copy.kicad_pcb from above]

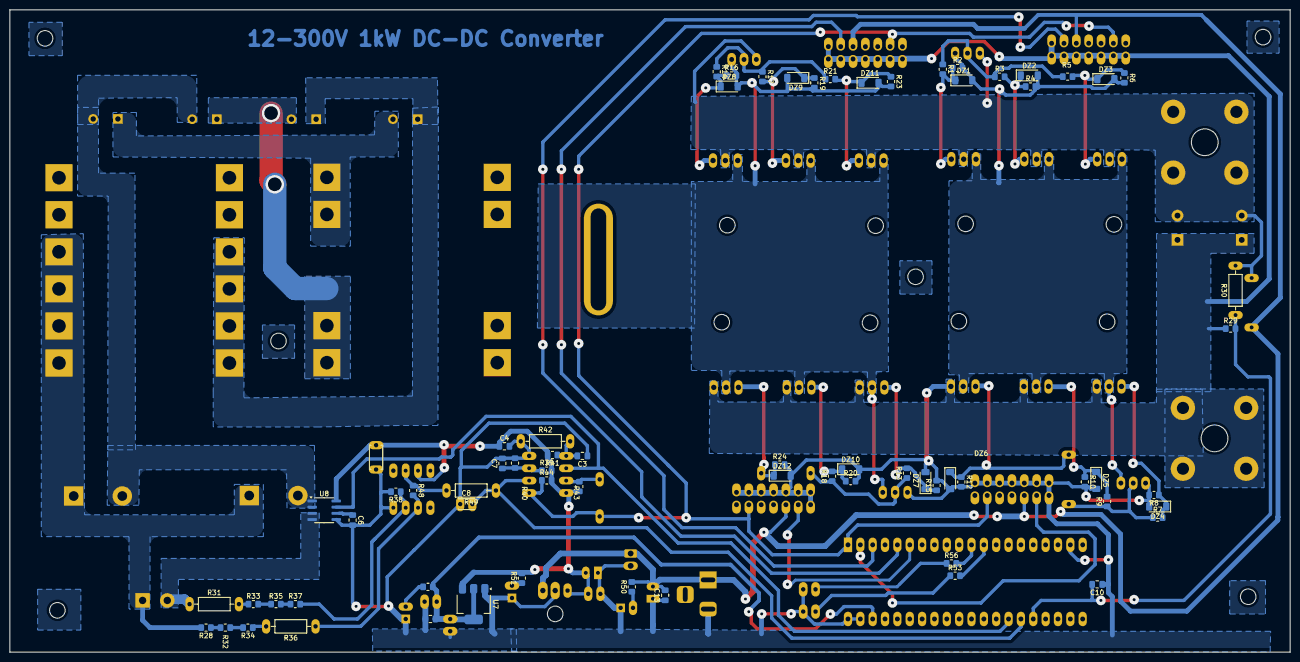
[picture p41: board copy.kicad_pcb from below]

Board: 2 copper layers, 263.2 x 132.1 mm, 121 parts (69 on the bottom side), 57 nets.

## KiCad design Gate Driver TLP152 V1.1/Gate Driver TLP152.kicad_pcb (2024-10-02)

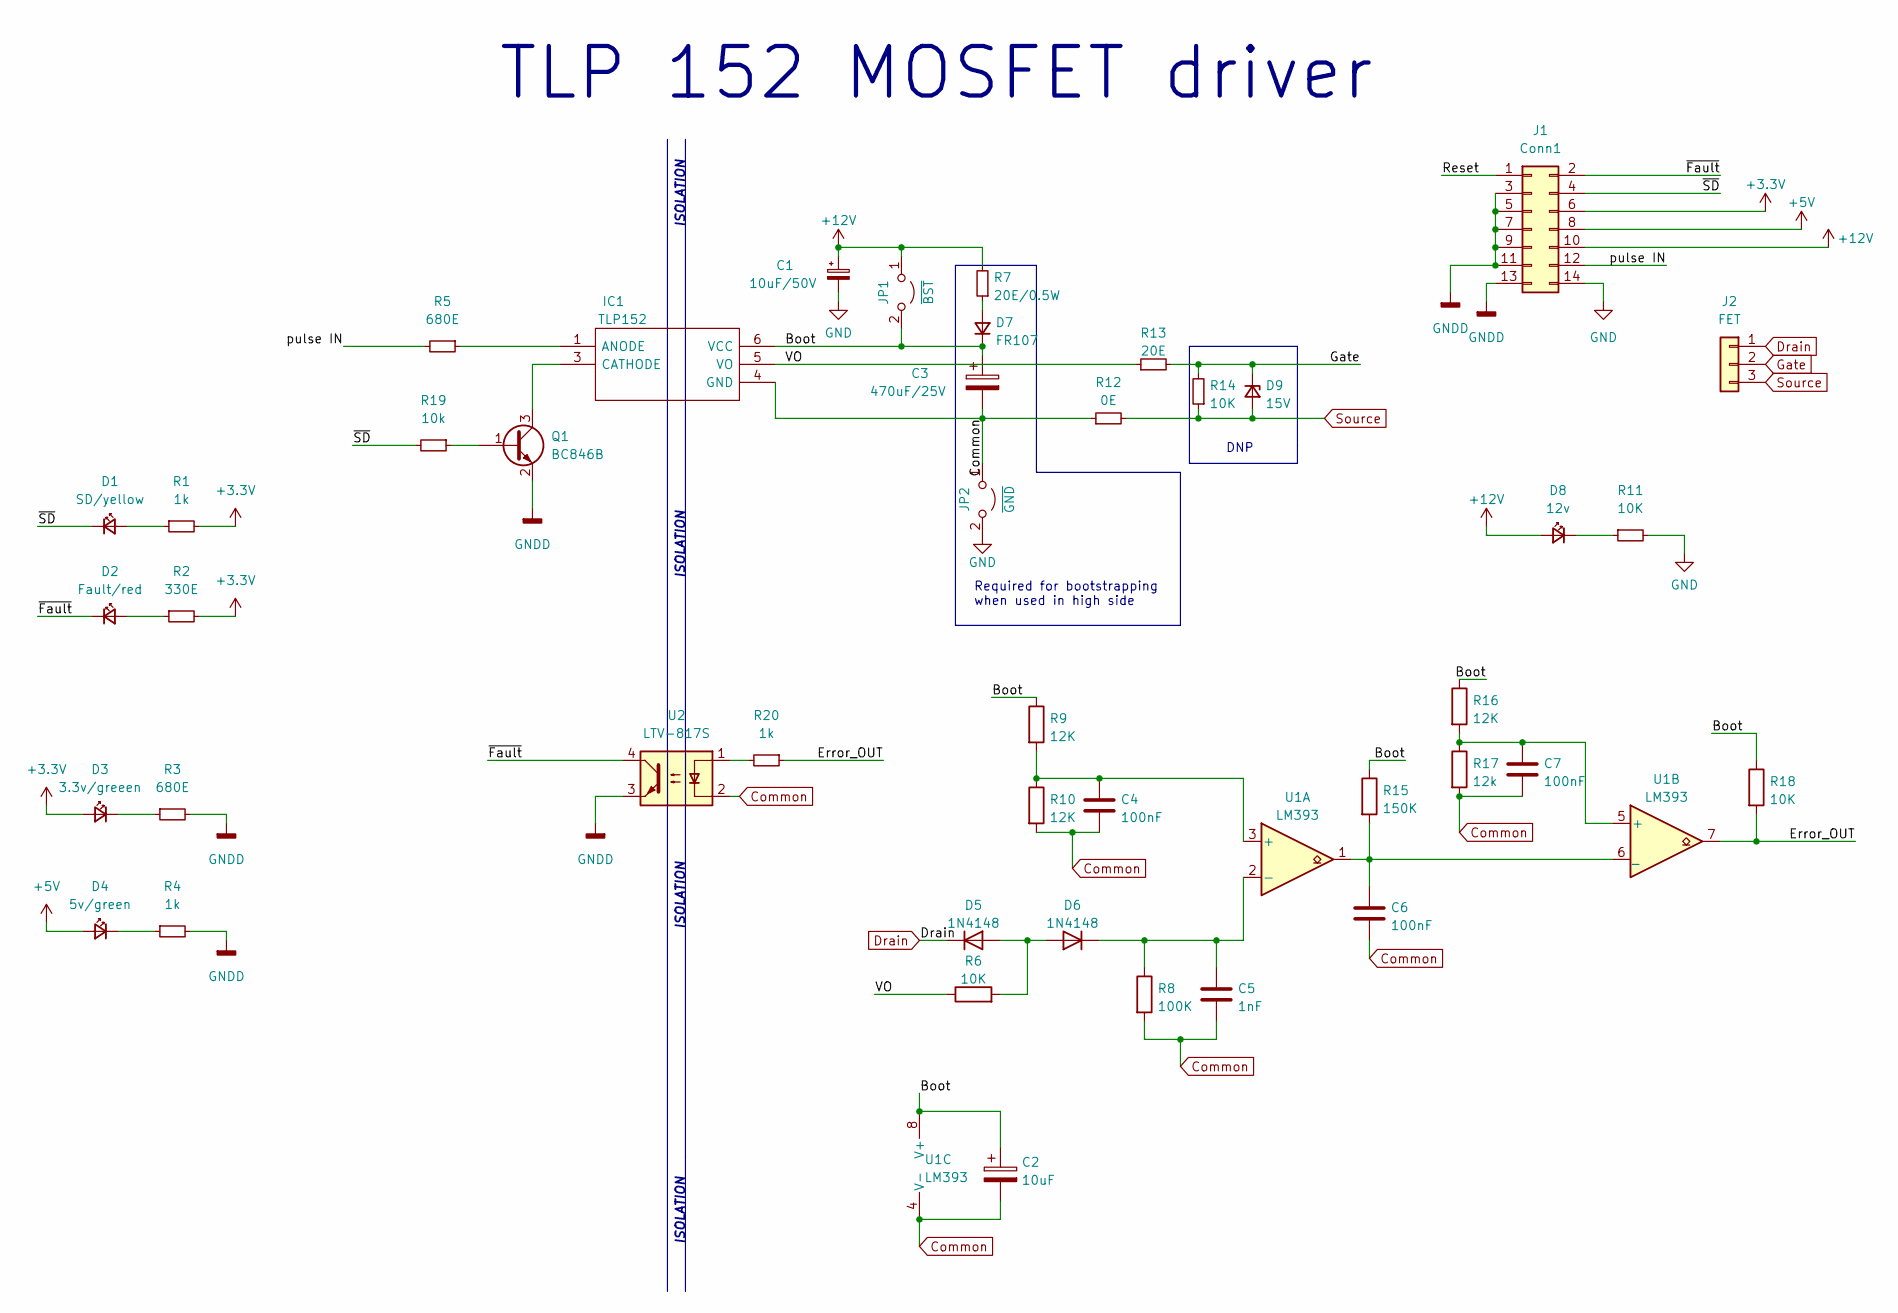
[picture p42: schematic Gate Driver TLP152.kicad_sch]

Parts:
C1: 10uF/50V; CP_Elec_5x5.4
C2: 10uF; C_0603_1608Metric
C3: 470uF/25V; CP_Elec_10x10.5
C4, C6, C7: 100nF; C_0603_1608Metric
C5: 1nF; C_0603_1608Metric
D1: SD/yellow; LED_0603_1608Metric
D2: Fault/red; LED_0603_1608Metric
D3: 3.3v/greeen; LED_0603_1608Metric
D4: 5v/green; LED_0603_1608Metric
D5, D6: 1N4148; D_MiniMELF
D7: FR107; D_SOD-123F
D8: 12v; LED_0603_1608Metric
D9: 15V; D_MiniMELF
IC1: TLP152; SO-5_4.4x3.6mm_P1.27mm; Manufacturer_Part_Number TLP152
J1: Conn1; PinHeader_2x07_P2.54mm_Horizontal
J2: FET; PinHeader_1x03_P2.54mm_Horizontal
JP1: ~{BST}; SolderJumper-2_P1.3mm_Open_RoundedPad1.0x1.5mm
JP2: ~{GND}; SolderJumper-2_P1.3mm_Open_RoundedPad1.0x1.5mm
Q1: BC846B; SOT-23
R1, R4, R20: 1k; R_0603_1608Metric
R2: 330E; R_0603_1608Metric
R3, R5: 680E; R_0603_1608Metric
R6, R11, R14, R18: 10K; R_0603_1608Metric
R7: 20E/0.5W; R_Axial_DIN0309_L9.0mm_D3.2mm_P12.70mm_Horizontal
R8: 100K; R_0603_1608Metric
R9, R10, R16: 12K; R_0603_1608Metric
R12: 0E; R_0603_1608Metric
R13: 20E; R_0603_1608Metric
R15: 150K; R_0603_1608Metric
R17: 12k; R_0603_1608Metric
R19: 10k; R_0603_1608Metric
U1: LM393; SOIC-8_3.9x4.9mm_P1.27mm
U2: LTV-817S; SMDIP-4_W9.53mm

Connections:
+3.3V: D3.2 (A), J1.6, R1.2, R2.2
+5V: D4.2 (A), J1.8
+12V: C1.1, D8.2 (A), J1.10, JP1.1 (A), R7.2
/Boot: C2.1, C3.1, D7.1 (K), IC1.6 (VCC), JP1.2 (B), R9.1, R15.1, R16.1, R18.1, U1.8 (V+)
/Error_OUT: R18.2, R20.1, U1.7
/Reset: J1.1
/VO: IC1.5 (VO), R6.1, R13.1
/pulse IN: J1.12, R5.2
/~Fault: D2.1 (K), J1.2, U2.4
/~SD: D1.1 (K), J1.4, R19.2
Common: C2.2, C3.2, C4.2, C5.2, C6.2, C7.2, IC1.4 (GND), JP2.1 (A), R8.2, R10.2, R12.1, R17.2, U1.4 (V-), U2.2
Drain: D5.1 (K), J2.1
GND: C1.2, J1.14, JP2.2 (B), R11.2
GNDD: J1.3, J1.5, J1.7, J1.9, J1.11, J1.13, Q1.2 (E), R3.2, R4.2, U2.3
Gate: D9.1 (K), J2.2, R13.2, R14.2
unnamed: C4.1, R9.2, R10.1, U1.3 (+)
unnamed: C5.1, D6.1 (K), R8.1, U1.2 (-)
unnamed: C6.1, R15.2, U1.1, U1.6 (_)
unnamed: C7.1, R16.2, R17.1, U1.5 (+)
unnamed: D1.2 (A), R1.1
unnamed: D2.2 (A), R2.1
unnamed: D3.1 (K), R3.1
unnamed: D4.1 (K), R4.1
unnamed: D5.2 (A), D6.2 (A), R6.2
unnamed: D7.2 (A), R7.1
unnamed: D8.1 (K), R11.1
unnamed: IC1.1 (ANODE), R5.1
unnamed: IC1.3 (CATHODE), Q1.3 (C)
unnamed: Q1.1 (B), R19.1
unnamed: R20.2, U2.1
Source: D9.2 (A), J2.3, R12.2, R14.1

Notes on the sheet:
TLP 152 MOSFET driver
ISOLATION
Required for bootstrapping when used in high side
DNP

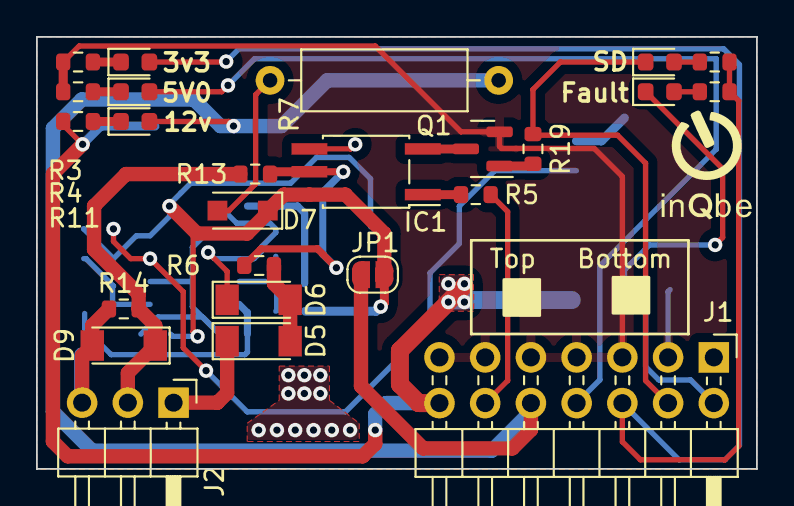
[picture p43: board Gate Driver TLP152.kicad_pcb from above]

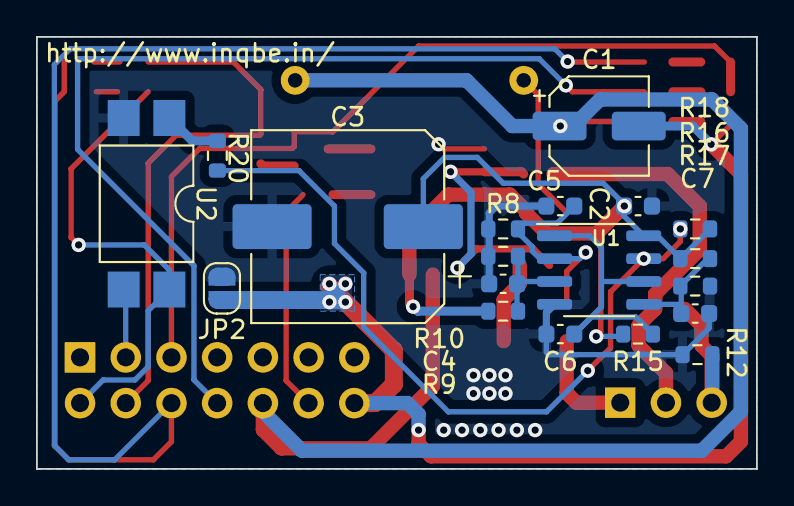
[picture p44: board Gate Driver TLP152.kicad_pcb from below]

Board: 2 copper layers, 40.0 x 24.0 mm, 44 parts (19 on the bottom side), 30 nets.

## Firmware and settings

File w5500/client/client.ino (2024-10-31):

#include    <Arduino.h>
#include    <SPI.h>
#include    <Ethernet.h>
#include    <SPI.h>
#include    <Wire.h>  // Only needed for Arduino 1.6.5 and earlier
//#include    "SSD1306Wire.h" // legacy include: `#include "SSD1306.h"`

#define     ETH_RST         4
#define     ETH_CS          5
#define     ETH_SCLK       18
#define     ETH_MISO       23
#define     ETH_MOSI       19
#define     OLED_SCL       22
#define     OLED_SDA       21


uint8_t mac[] = {
    0xDE, 0xAD, 0xBE, 0xEF, 0xFE, 0xED
};

// Initialize the OLED display using Wire library
//SSD1306Wire  display(0x3c, OLED_SDA, OLED_SCL);


// Initialize the Ethernet client library
// with the IP address and port of the server
// that you want to connect to (port 80 is default for HTTP):
EthernetClient client;

// if you don't want to use DNS (and reduce your sketch size)
// use the numeric IP instead of the name for the server:
//IPAddress server(74,125,232,128);  // numeric IP for Google (no DNS)
char server[] = "www.bing.com";    // name address for Google (using DNS)

// Variables to measure the speed
unsigned long beginMicros, endMicros;
unsigned long byteCount = 0;
bool printWebData = true;  // set to false for better speed measurement


void ethernetReset(const uint8_t resetPin)
{
    pinMode(resetPin, OUTPUT);
    digitalWrite(resetPin, HIGH);
    delay(250);
    digitalWrite(resetPin, LOW);
    delay(50);
    digitalWrite(resetPin, HIGH);
    delay(350);
}


void setup()
{
    Serial.begin(115200);
    Serial.println("ESP32 W5500 Start");

    //display.init();
    //display.flipScreenVertically();

    //display.setFont(ArialMT_Plain_10);
    //display.setTextAlignment(TEXT_ALIGN_LEFT);

   // display.drawString(0, 0, "ESP32 W5500 Start");
    // display.display();

    SPI.begin(ETH_SCLK, ETH_MISO, ETH_MOSI);

    ethernetReset(ETH_RST);
    Ethernet.init(ETH_CS);

    Serial.println("Starting ETH connection...");
    //display.drawString(0, 12, "Starting ETH connection...");
    //display.display();


    if (Ethernet.begin(mac) == 0) {

        //display.drawString(0, 24, "Failed to configure Eth using DHCP");
        Serial.println("Failed to configure Eth using DHCP");
        //display.display();

        if (Ethernet.hardwareStatus() == EthernetNoHardware) {

           // display.drawString(0, 34, "Eth shield was not found.");
            Serial.println("Eth shield was not found.");
            //display.display();

        } else if (Ethernet.linkStatus() == LinkOFF) {

            ///display.drawString(0, 34, "Eth cable is not connected.");
            Serial.println("Eth cable is not connected.");
            //display.display();

        }
        // no point in carrying on, so do nothing forevermore:
        while (true) {
            delay(1);
        }
    }


    Serial.print("Ethernet IP is: ");
    Serial.println(Ethernet.localIP());

    //display.drawString(0, 24, "Ethernet IP is: ");
    //display.drawString(0, 34, Ethernet.localIP().toString());
   // display.display();


    // give the Ethernet shield a second to initialize:
    delay(1000);
    Serial.print("connecting to ");
    Serial.print(server);
    Serial.println("...");

    // if you get a connection, report back via serial:
    if (client.connect(server, 80)) {
        Serial.print("connected to ");
        Serial.println(client.remoteIP());
        // Make a HTTP request:
        client.println("GET / HTTP/1.1");
        client.println("Host: www.bing.com");
        client.println("Connection: close");
        client.println();
    } else {
        // if you didn't get a connection to the server:
        Serial.println("connection failed");
    }
    beginMicros = micros();

}

void loop()
{
// if there are incoming bytes available
    // from the server, read them and print them:
    int len = client.available();
    if (len > 0) {
        byte buffer[80];
        if (len > 80) len = 80;
        client.read(buffer, len);
        if (printWebData) {
            Serial.write(buffer, len); // show in the serial monitor (slows some boards)
        }
        byteCount = byteCount + len;
    }

    // if the server's disconnected, stop the client:
    if (!client.connected()) {
        endMicros = micros();
        Serial.println();
        Serial.println("disconnecting.");
        client.stop();
        Serial.print("Received ");
        Serial.print(byteCount);
        Serial.print(" bytes in ");
        float seconds = (float)(endMicros - beginMicros) / 1000000.0;
        Serial.print(seconds, 4);
        float rate = (float)byteCount / seconds / 1000.0;
        Serial.print(", rate = ");
        Serial.print(rate);
        Serial.print(" kbytes/second");
        Serial.println();

        // do nothing forevermore:
        while (true) {
            delay(1);
        }
    }
}

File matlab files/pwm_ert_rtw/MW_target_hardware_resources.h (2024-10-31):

#ifndef PORTABLE_WORDSIZES
#ifdef __MW_TARGET_USE_HARDWARE_RESOURCES_H__
#ifndef __MW_TARGET_HARDWARE_RESOURCES_H__
#define __MW_TARGET_HARDWARE_RESOURCES_H__

#define MW_MULTI_TASKING_MODE 1
#include "c2000BoardSupport.h"
#include "MW_f2837xD_includes.h"
#include "c2000SchedulerTimer.h"

#define MW_USECODERTARGET 1
#define MW_TARGETHARDWARE TI Delfino F28379D LaunchPad
#define MW_EXTMODEPROTOCOLINFO_XCPONSERIAL_HOSTINTERFACE Simulink
#define MW_EXTMODEPROTOCOLINFO_XCPONSERIAL_LOGGINGBUFFERAUTO 1
#define MW_EXTMODEPROTOCOLINFO_XCPONSERIAL_LOGGINGBUFFERSIZE 1000
#define MW_EXTMODEPROTOCOLINFO_XCPONSERIAL_LOGGINGBUFFERNUM 3
#define MW_EXTMODEPROTOCOLINFO_XCPONSERIAL_MAXCONTIGSAMPLES 8
#define MW_EXTMODEPROTOCOLINFO_XCPONCAN_HOSTINTERFACE Simulink
#define MW_EXTMODEPROTOCOLINFO_XCPONCAN_LOGGINGBUFFERAUTO 1
#define MW_EXTMODEPROTOCOLINFO_XCPONCAN_LOGGINGBUFFERSIZE 1000
#define MW_EXTMODEPROTOCOLINFO_XCPONCAN_LOGGINGBUFFERNUM 3
#define MW_EXTMODEPROTOCOLINFO_XCPONCAN_MAXCONTIGSAMPLES 10
#define MW_CONNECTIONINFO_XCPONSERIAL_BAUDRATE codertarget.registry.getExtModeHostBaud(hCS);
#define MW_CONNECTIONINFO_XCPONSERIAL_COMPORT codertarget.registry.serialPortValueCallback(hCS, 'ExtModeCOMPort');
#define MW_CONNECTIONINFO_XCPONSERIAL_VERBOSE 1
#define MW_CONNECTIONINFO_XCPONCAN_CANVENDOR 
#define MW_CONNECTIONINFO_XCPONCAN_CANDEVICE 
#define MW_CONNECTIONINFO_XCPONCAN_CANCHANNEL 
#define MW_CONNECTIONINFO_XCPONCAN_BUSSPEED codertarget.registry.getExtModeCANBusSpeed(hCS)
#define MW_CONNECTIONINFO_XCPONCAN_CANIDCOMMAND 2
#define MW_CONNECTIONINFO_XCPONCAN_CANIDRESPONSE 3
#define MW_CONNECTIONINFO_XCPONCAN_ISCANIDEXTENDED 0
#define MW_CONNECTIONINFO_XCPONCAN_VERBOSE 1
#define MW_EXTMODE_CONFIGURATION XCP on Serial
#define MW_EXTMODE_CANMODULE 1
#define MW_EXTMODE_CANRXMAILBOXNUMBER 0
#define MW_EXTMODE_CANTXMAILBOXNUMBER 1
#define MW_EXTMODE_SCIMODULE 0
#define MW_EXTMODE_USEREALTIMESTAMPLOGGING 0
#define MW_EXTMODE_SIGNALBUFFERSIZE 10000.000000
#define MW_ESB_PROCESSINGUNIT c28xCPU1
#define MW_ESB_SIMDIAGSHOWINSDI 1
#define MW_ESB_SIMDIAGSAVETOFILE 1
#define MW_ESB_SIMDIAGOVERWRITEFILE 0
#define MW_ESB_HWDIAGSHOWINSDI 0
#define MW_ESB_HWDIAGSAVETOFILE 0
#define MW_ESB_HWDIAGOVERWRITEFILE 0
#define MW_ESB_HWDIAGINSTRUMENTATION Code
#define MW_ESB_HWDIAGRECORDING Continuous
#define MW_ESB_HWDIAGSTREAMINGMODETYPE Unlimited
#define MW_ESB_HWDIAGBUFFERSIZE 1024.000000
#define MW_ESB_HWDIAGNUMBUFFERS 1.000000
#define MW_ESB_HWDIAGVIEWLEVEL Task manager tasks
#define MW_ESB_SETRNG 0
#define MW_ESB_RNGSEED default
#define MW_ESB_CACHEDATA 0
#define MW_ESB_SCHEDULEEDITORSCHEDULERESET 0
#define MW_FPGADESIGN_PROJECTFOLDER soc_prj
#define MW_RTOS Baremetal
#define MW_SCHEDULER_INTERRUPT_SOURCE 0
#define MW_RUNTIME_BUILDACTION 0
#define MW_RUNTIME_DISABLEPARALLELBUILD 0
#define MW_RUNTIME_DEVICEID 0
#define MW_RUNTIME_FLASHLOAD 1
#define MW_RUNTIME_ENABLETMU 1
#define MW_RUNTIME_LOADCOMMANDARG $(TARGET_ROOT)/CCS_Config/f28379D.ccxml
#define MW_RUNTIME_CPU2MODELENABLE 102 97108115101
#define MW_RUNTIME_CPU2MODEL 
#define MW_RUNTIME_PF1DMAACCESS 0
#define MW_RUNTIME_PF2DMAACCESS 0
#define MW_TARGETLINKOBJ_USECUSTOMLINKER 0
#define MW_TARGETLINKOBJ_NAME $(TARGET_ROOT)/src/c28377D.cmd
#define MW_CLA_LSCONFIGENABLE 0
#define MW_CLA_PMLENGTH 1
#define MW_CLA_DMLENGTH 0
#define MW_CLA_CPULSLENGTH 6
#define MW_CLOCKING_CPUCLOCKRATEMHZ 200
#define MW_CLOCKING_USEINTERNALOSC 0
#define MW_CLOCKING_OSCCLK 10
#define MW_CLOCKING_AUTOSETPLLSETTINGS 1
#define MW_CLOCKING_PLLCR 40
#define MW_CLOCKING_DIVSEL 2
#define MW_CLOCKING_CLOSESTCPUCLOCK 200
#define MW_CLOCKING_CLOSESTCPUCLOCK1 200
#define MW_CLOCKING_LSPCLKDIV 0
#define MW_CLOCKING_LSPCLKDIV1 0
#define MW_CLOCKING_LSPCLK 200
#define MW_IXBAR_FLAG 49
#define MW_IXBAR_I1 None
#define MW_IXBAR_I2 None
#define MW_IXBAR_I3 None
#define MW_IXBAR_I4 None
#define MW_IXBAR_I5 None
#define MW_IXBAR_I6 None
#define MW_IXBAR_I7 20
#define MW_IXBAR_I8 21
#define MW_IXBAR_I9 99
#define MW_IXBAR_I10 54
#define MW_IXBAR_I11 55
#define MW_IXBAR_I12 57
#define MW_IXBAR_I13 None
#define MW_IXBAR_I14 None
#define MW_IXBAR_ONE_TIME 0.000000
#define MW_OUTPUTXBAR_OXBAR1 0
#define MW_OUTPUTXBAR_OXBAR_MUX1 -1
#define MW_OUTPUTXBAR_OXBAR1_MUXSELECT XXXXXXXXXXXXXXXXXXXXXXXXXXXXXXXX
#define MW_OUTPUTXBAR_OXBAR1_GPIO 0
#define MW_OUTPUTXBAR_OXBAR1_LATCH 0
#define MW_OUTPUTXBAR_OXBAR1_INVERT 0
#define MW_OUTPUTXBAR_OXBAR2 0
#define MW_OUTPUTXBAR_OXBAR_MUX2 -1
#define MW_OUTPUTXBAR_OXBAR2_MUXSELECT XXXXXXXXXXXXXXXXXXXXXXXXXXXXXXXX
#define MW_OUTPUTXBAR_OXBAR2_GPIO 0
#define MW_OUTPUTXBAR_OXBAR2_LATCH 0
#define MW_OUTPUTXBAR_OXBAR2_INVERT 0
#define MW_OUTPUTXBAR_OXBAR3 0
#define MW_OUTPUTXBAR_OXBAR_MUX3 -1
#define MW_OUTPUTXBAR_OXBAR3_MUXSELECT XXXXXXXXXXXXXXXXXXXXXXXXXXXXXXXX
#define MW_OUTPUTXBAR_OXBAR3_GPIO 0
#define MW_OUTPUTXBAR_OXBAR3_LATCH 0
#define MW_OUTPUTXBAR_OXBAR3_INVERT 0
#define MW_OUTPUTXBAR_OXBAR4 0
#define MW_OUTPUTXBAR_OXBAR_MUX4 -1
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

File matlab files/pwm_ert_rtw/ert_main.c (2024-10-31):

/*
 * Academic License - for use in teaching, academic research, and meeting
 * course requirements at degree granting institutions only.  Not for
 * government, commercial, or other organizational use.
 *
 * File: ert_main.c
 *
 * Code generated for Simulink model 'pwm'.
 *
 * Model version                  : 1.7
 * Simulink Coder version         : 24.1 (R2024a) 19-Nov-2023
 * C/C++ source code generated on : Tue Sep 17 13:06:12 2024
 *
 * Target selection: ert.tlc
 * Embedded hardware selection: Texas Instruments->C2000
 * Code generation objectives: Unspecified
 * Validation result: Not run
 */

#include "pwm.h"
#include "rtwtypes.h"
#include "MW_target_hardware_resources.h"

volatile int IsrOverrun = 0;
static boolean_T OverrunFlag = 0;
void rt_OneStep(void)
{
  /* Check for overrun. Protect OverrunFlag against preemption */
  if (OverrunFlag++) {
    IsrOverrun = 1;
    OverrunFlag--;
    return;
  }

  enableTimer0Interrupt();
  pwm_step();

  /* Get model outputs here */
  disableTimer0Interrupt();
  OverrunFlag--;
}

volatile boolean_T stopRequested;
volatile boolean_T runModel;
int main(void)
{
  float modelBaseRate = 0.001;
  float systemClock = 200;

  /* Initialize variables */
  stopRequested = false;
  runModel = false;
  c2000_flash_init();
  init_board();

#if defined(MW_EXEC_PROFILER_ON) || (defined(MW_EXTMODE_RUNNING) && !defined(XCP_TIMESTAMP_BASED_ON_SIMULATION_TIME))

  hardwareTimer1Init();

#endif

  ;
  rtmSetErrorStatus(pwm_M, 0);
  pwm_initialize();
  globalInterruptDisable();
  configureTimer0(modelBaseRate, systemClock);
  runModel =
    rtmGetErrorStatus(pwm_M) == (NULL);
  enableTimer0Interrupt();
  config_ePWM_TBSync();
  globalInterruptEnable();
  while (runModel) {
    stopRequested = !(
                      rtmGetErrorStatus(pwm_M) == (NULL));
  }

  /* Terminate model */
  pwm_terminate();
  globalInterruptDisable();
  return 0;
}

/*
 * File trailer for generated code.
 *
 * [EOF]
 */

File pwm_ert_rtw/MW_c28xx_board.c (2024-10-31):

#include "c2000BoardSupport.h"
#include "MW_f2837xD_includes.h"
#include "rtwtypes.h"
#include "pwm.h"
#include "pwm_private.h"

void init_board (void)
{
  DisableDog();
  EALLOW;
  CpuSysRegs.PCLKCR0.bit.DMA = 1U;
  CpuSysRegs.PCLKCR6.bit.SD1 = 1U;
  CpuSysRegs.PCLKCR6.bit.SD2 = 1U;
  EDIS;

#ifdef CPU1

  EALLOW;

  //enable pull-ups on unbonded IOs as soon as possible to reduce power consumption.
  GPIO_EnableUnbondedIOPullups();
  CpuSysRegs.PCLKCR13.bit.ADC_A = 1U;
  CpuSysRegs.PCLKCR13.bit.ADC_B = 1U;
  CpuSysRegs.PCLKCR13.bit.ADC_C = 1U;
  CpuSysRegs.PCLKCR13.bit.ADC_D = 1U;

  //check if device is trimmed
  if (*((Uint16 *)0x5D1B6) == 0x0000U) {
    //device is not trimmed, apply static calibration values
    AnalogSubsysRegs.ANAREFTRIMA.all = 31709U;
    AnalogSubsysRegs.ANAREFTRIMB.all = 31709U;
    AnalogSubsysRegs.ANAREFTRIMC.all = 31709U;
    AnalogSubsysRegs.ANAREFTRIMD.all = 31709U;
  }

  CpuSysRegs.PCLKCR13.bit.ADC_A = 0U;
  CpuSysRegs.PCLKCR13.bit.ADC_B = 0U;
  CpuSysRegs.PCLKCR13.bit.ADC_C = 0U;
  CpuSysRegs.PCLKCR13.bit.ADC_D = 0U;
  EDIS;
  InitSysPll(XTAL_OSC,40,0,1);

  //Turn on all peripherals
  //InitPeripheralClocks();
  EALLOW;
  CpuSysRegs.PCLKCR0.bit.CPUTIMER0 = 1U;
  CpuSysRegs.PCLKCR0.bit.CPUTIMER1 = 1U;
  CpuSysRegs.PCLKCR0.bit.CPUTIMER2 = 1U;
  CpuSysRegs.PCLKCR0.bit.HRPWM = 1U;
  CpuSysRegs.PCLKCR1.bit.EMIF1 = 1U;
  CpuSysRegs.PCLKCR1.bit.EMIF2 = 1U;

  /* Assign all Peripherals to CPU2 */
  DevCfgRegs.CPUSEL11.all = 0x0000000FU;
  DevCfgRegs.CPUSEL5.all = 0x0000000FU;
  DevCfgRegs.CPUSEL8.all = 0x00000003U;
  DevCfgRegs.CPUSEL14.all = 0x00070000U;
  DevCfgRegs.CPUSEL7.all = 0x00000003U;
  DevCfgRegs.CPUSEL0.all = 0x00000FFFU;
  DevCfgRegs.CPUSEL1.all = 0x0000003FU;
  DevCfgRegs.CPUSEL2.all = 0x00000007U;
  DevCfgRegs.CPUSEL4.all = 0x00000003U;
  DevCfgRegs.CPUSEL6.all = 0x00000007U;
  DevCfgRegs.CPUSEL12.all = 0x000000FFU;
  EDIS;

#endif                                 // #ifdef CPU1

  EALLOW;

  /* Configure low speed peripheral clocks */
  ClkCfgRegs.LOSPCP.bit.LSPCLKDIV = 0U;
  EDIS;

  /* Disable and clear all CPU interrupts */
  DINT;
  IER = 0x0000U;
  IFR = 0x0000U;
  InitPieCtrl();
  InitPieVectTable();
  initSetGPIOIPC();
  InitCpuTimers();

#ifdef CPU1

  EALLOW;

  /* Assign used ADC modules to CPU1 */
  DevCfgRegs.CPUSEL11.bit.ADC_B = 0U;

#ifdef MW_DAC_CHANNEL_A

  DevCfgRegs.CPUSEL14.bit.DAC_A = 0U;

#endif

#ifdef MW_DAC_CHANNEL_B

  DevCfgRegs.CPUSEL14.bit.DAC_B = 0U;

#endif

#ifdef MW_DAC_CHANNEL_C

  DevCfgRegs.CPUSEL14.bit.DAC_C = 0U;

#endif

  /* Assign SDFM modules to CPU1 */
#ifdef MW_SDFM_1

  DevCfgRegs.CPUSEL4.bit.SD1 = 0U;

#endif

#ifdef MW_SDFM_2

  DevCfgRegs.CPUSEL4.bit.SD2 = 0U;

#endif

#ifdef MW_SDFM_3

  DevCfgRegs.CPUSEL4.bit.SD3 = 0U;

#endif

#ifdef MW_SDFM_4

  DevCfgRegs.CPUSEL4.bit.SD4 = 0U;

#endif

  /* Assign used PWM modules to CPU1 */
  DevCfgRegs.CPUSEL0.bit.EPWM1 = 0U;
  DevCfgRegs.CPUSEL0.bit.EPWM2 = 0U;

  /* Assign used SPI modules to CPU1 */
#ifdef MW_SPI_A

  DevCfgRegs.CPUSEL6.bit.SPI_A = 0U;

#endif

#ifdef MW_SPI_B

  DevCfgRegs.CPUSEL6.bit.SPI_B = 0U;

#endif

#ifdef MW_SPI_C

  DevCfgRegs.CPUSEL6.bit.SPI_C = 0U;

#endif

#ifdef MW_SPI_D

  DevCfgRegs.CPUSEL6.bit.SPI_D = 0U;

#endif

#if defined MW_CMPSS1_COMPH || defined MW_CMPSS1_COMPL

  DevCfgRegs.CPUSEL12.bit.CMPSS1 = 0U;

#endif

#if defined MW_CMPSS2_COMPH || defined MW_CMPSS2_COMPL

  DevCfgRegs.CPUSEL12.bit.CMPSS2 = 0U;

#endif

#if defined MW_CMPSS3_COMPH || defined MW_CMPSS3_COMPL

  DevCfgRegs.CPUSEL12.bit.CMPSS3 = 0U;

#endif

#if defined MW_CMPSS4_COMPH || defined MW_CMPSS4_COMPL

  DevCfgRegs.CPUSEL12.bit.CMPSS4 = 0U;

#endif

#if defined MW_CMPSS5_COMPH || defined MW_CMPSS5_COMPL

  DevCfgRegs.CPUSEL12.bit.CMPSS5 = 0U;

#endif

#if defined MW_CMPSS6_COMPH || defined MW_CMPSS6_COMPL

  DevCfgRegs.CPUSEL12.bit.CMPSS6 = 0U;

#endif

#if defined MW_CMPSS7_COMPH || defined MW_CMPSS7_COMPL

  DevCfgRegs.CPUSEL12.bit.CMPSS7 = 0U;

#endif

#if defined MW_CMPSS8_COMPH || defined MW_CMPSS8_COMPL

  DevCfgRegs.CPUSEL12.bit.CMPSS8 = 0U;

#endif

  EDIS;

#endif                                 // #ifdef CPU1

  /* initial ePWM GPIO assignment... */
  config_ePWM_GPIO();
  EALLOW;

  /* Enable clock to ePWM */
  CpuSysRegs.PCLKCR2.bit.EPWM1 = 1U;
  CpuSysRegs.PCLKCR2.bit.EPWM2 = 1U;

  /* Disable TBCLK within ePWM before module configuration */
  CpuSysRegs.PCLKCR0.bit.TBCLKSYNC = 0U;
  EDIS;
  config_ePWMSyncSource();
  configureIXbar();

#ifdef CPU1

  /* initial GPIO qualification settings.... */
  EALLOW;
  GpioCtrlRegs.GPAQSEL1.all = 0x0U;
  GpioCtrlRegs.GPAQSEL2.all = 0x0U;
  GpioCtrlRegs.GPBQSEL1.all = 0x0U;
  GpioCtrlRegs.GPBQSEL2.all = 0x0U;
  GpioCtrlRegs.GPCQSEL1.all = 0x0U;
  GpioCtrlRegs.GPCQSEL2.all = 0x0U;
  GpioCtrlRegs.GPDQSEL1.all = 0x0U;
  GpioCtrlRegs.GPDQSEL2.all = 0x0U;
  GpioCtrlRegs.GPEQSEL1.all = 0x0U;
  GpioCtrlRegs.GPEQSEL2.all = 0x0U;
  GpioCtrlRegs.GPFQSEL1.all = 0x0U;
  EDIS;
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
